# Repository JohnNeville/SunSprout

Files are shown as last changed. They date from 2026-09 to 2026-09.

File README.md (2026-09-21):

# SunSprout

> [!WARNING]
> **Work in progress. This board has never been fabricated or tested.**
>
> Everything here has been verified only in software — ERC and DRC pass, pin assignments and
> component values are checked against manufacturer datasheets, and the fabrication outputs
> generate cleanly. No physical board exists. Nothing has been powered on, measured, or
> proven to work.
>
> It is published at this stage deliberately, to get design feedback before a fabrication run.
> Manufacturing and bring-up are intended; this page will say so once real measurements exist.
>
> **If you are thinking of building one:** treat it as an untested design, not a finished
> product. Expect to find mistakes. Errors in the charging or protection circuitry could damage
> a battery. Review it yourself before spending money on a panelised order.
>
> Feedback is genuinely welcome — especially on the power path, the charger and fuel-gauge
> configuration, and anything in [docs/hub/modules/](docs/hub/modules/) where the reasoning
> looks wrong.

An open-hardware solar and battery powered sensor system. SunSprout covers both halves of a
deployment: the **hub**, a custom board that manages power and talks to the network, and the
**remote sensors** that connect back to it over a long cable run.

The hub is the custom hardware in this project. The remote sensors are largely assembled from
existing modules, and are documented here so that a whole system can be reproduced rather than
inferred.

## The hub

A compact power-management and connectivity board built around the **ESP32-C5**. It takes power
from USB-C, a small DC or solar source, or a lithium battery. It charges the battery, regulates
a 3.3 V system rail, and exposes two independent I2C buses — one for its own power-management
ICs, and one for sensors, buffered onto a differential pair so it can drive a long cable.

| | |
|---|---|
| Documentation site | **[johnneville.github.io/SunSprout](https://johnneville.github.io/SunSprout/)** — pinout, connectors, power behaviour |
| Design files | [hardware/hub/](hardware/hub/) — KiCad 10 project, hand-routed |
| Why it is built this way | [docs/hub/modules/](docs/hub/modules/) — per-IC design notes |
| Firmware | [firmware/](firmware/) — ESPHome configuration; [docs/hub/firmware.md](docs/hub/firmware.md) for the reasoning |
| Off-board parts you need | [docs/hub/extra-components.md](docs/hub/extra-components.md) |

Every IC's datasheet-required external components are drawn directly into the schematic rather
than treated as black-box breakout modules. The schematic and PCB are maintained by hand in
KiCad; there is no generator producing them.

### Design decisions worth knowing up front

- **Two independent I2C buses.** An always-on internal bus carries the charger and the fuel
  gauge. A separate switched bus feeds the differential buffer that drives the two 8P8C jacks,
  plus its own STEMMA QT connector. A fault on a long external cable cannot stall the bus that
  reports the battery state.
- **Protection sized to what each port is for.** ESD/TVS on the ports meant to carry a cable
  off-board — the differential I2C lines on the 8P8C jacks, the USB-C data lines, and the USB
  `VBUS` rail. The STEMMA QT ports, GPIO headers and thermistor inputs have none, by design:
  they are for sensors inside the same enclosure. Reverse-polarity protection guards the
  battery and solar inputs, each sized to that input's real voltage range; USB-C gets none,
  being a keyed, spec-defined connector that cannot be connected backwards.
- **Alert lines go to their own GPIOs.** The charger and the fuel gauge each get a dedicated
  interrupt pin, so firmware reacts to a fault without polling, and without interrogating both
  devices to find which one raised it.
- **Connector families differ by role on purpose.** The battery and solar inputs use physically
  different connectors, so a solar source cannot be plugged into the battery input. The two
  thermistor inputs are a third family again, chosen to be field-terminable rather than
  requiring a pre-terminated probe.

## Remote sensors

A custom board, `SunSproutSatellite` ([hardware/satellite/](hardware/satellite/)), is the
differential-I2C endpoint that sits at the plant end of the cable — it terminates the line,
converts back to standard I2C, and reads four capacitive soil-moisture probes plus one
1-Wire soil-temperature probe. It integrates what was previously an off-the-shelf SparkFun
QwiicBus EndPoint wired to a breadboarded ADS1115. See
[docs/satellite/modules/](docs/satellite/modules/) for the per-IC design notes, and
[Use Cases](https://johnneville.github.io/SunSprout/use-cases) for the deployed topology.

**Status: schematic-capture spec only** — the KiCad project is scaffolded but no board has
been fabricated yet.

## Repository layout

```
.
├── hardware/
│   ├── hub/                  # the hub's KiCad project, libraries, and SPICE decks
│   └── satellite/            # the satellite's KiCad project and libraries
├── firmware/                 # ESPHome configuration for the hub
├── docs/
│   ├── hub/
│   │   ├── modules/          # per-IC design notes: part choice, passive values, constraints
│   │   ├── firmware.md       # why the firmware is configured the way it is
│   │   └── extra-components.md
│   └── satellite/
│       └── modules/          # per-IC design notes for the satellite board
├── tools/                    # Dockerised KiCad CLI: validation, fab outputs, doc assets
└── website/                  # Docusaurus documentation site
```

## Documentation

The prose documentation is split by audience:

- **[docs/hub/modules/](docs/hub/modules/)** explains *why* the hub is built the way it is —
  why each part was chosen, and why its passives have the values and packages they do. Written
  for someone reading the design cold. Start at the [index](docs/hub/modules/README.md).
- **[docs/hub/firmware.md](docs/hub/firmware.md)** explains the firmware decisions — why the
  watchdog is off, why the charge voltage comes from the declared chemistry, and what the
  `SFET_PRESENT` bit unlocks. The configuration itself is in [firmware/](firmware/); the chip
  drivers live in [esphome-bq-drivers](https://github.com/JohnNeville/esphome-bq-drivers).
- **[website/](website/)** is the source for the user-facing documentation site, published at
  **[johnneville.github.io/SunSprout](https://johnneville.github.io/SunSprout/)**: pinout,
  connectors, power behaviour, and downloads.

Manufacturer datasheets are deliberately not redistributed here. Each design note names the
exact part number, so you can get the datasheet from the manufacturer.

## Building and validating

Docker is the only prerequisite. No local KiCad installation is required.

```bash
tools/run_kicad_validation.sh
```

```bash
tools/generate-docs-assets.sh
```

The first runs ERC and DRC. The second regenerates the board renders, schematic PDF, STEP
model, interactive BOM, and pinout diagram under `website/static/`. Re-run it after any
schematic or layout change, so that the published assets never go stale.

See [hardware/hub/README.md](hardware/hub/README.md) for what you can do with the KiCad project
without any extra setup, and which external libraries are optional.

## License

Copyright John Neville 2026.
This source describes Open Hardware and is licensed under the CERN-OHL-S v2.

You may redistribute and modify this source and make products using it
under the terms of the CERN-OHL-S v2 (https://ohwr.org/cern_ohl_s_v2.txt).

This source is distributed WITHOUT ANY EXPRESS OR IMPLIED WARRANTY,
INCLUDING OF MERCHANTABILITY, SATISFACTORY QUALITY AND FITNESS FOR A
PARTICULAR PURPOSE. Please see the CERN-OHL-S v2 for applicable conditions.

Source location: https://github.com/JohnNeville/SunSprout

See [LICENSE](LICENSE) for the full license text.

This design also vendors Espressif's official CC BY-SA 4.0 KiCad library for the ESP32-C5
module. See [NOTICE.md](NOTICE.md) for that credit and an acknowledgment of other technical
references consulted during design.

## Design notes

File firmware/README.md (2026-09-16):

# Firmware

ESPHome configuration for the SunSprout hub.

| File | What it is |
|---|---|
| `sunsprout-hub.yaml` | The board package. Hardware only: MCU, both I2C buses, charger, fuel gauge, alert inputs, user rail, status LED. |
| `example-device.yaml` | A complete device built on that package, with WiFi, the Home Assistant API, OTA and deep sleep. |

The two chip drivers live in a separate repository,
[esphome-bq-drivers](https://github.com/JohnNeville/esphome-bq-drivers), because they are
drivers for stock TI parts rather than anything specific to this board. The board package
pulls them in through `external_components`.

## Flash a board

```bash
pip install esphome
```

Create `secrets.yaml` next to the config with `wifi_ssid`, `wifi_password`,
`fallback_password`, `api_encryption_key` and `ota_password`, then:

```bash
esphome run firmware/example-device.yaml
```

Hold `SW2` (boot) while pressing `SW1` (reset) to enter download mode for the first flash.
After that, OTA works.

## Pin map

| GPIO | Net | Use |
|---|---|---|
| GPIO2 | `SDA_INT` | Internal I2C data (`LP_I2C_SDA`) |
| GPIO3 | `SCL_INT` | Internal I2C clock (`LP_I2C_SCL`) |
| GPIO4 | `FG_ALERT` | Fuel gauge alert, active low |
| GPIO6 | `LED1_CTRL` | Status LED |
| GPIO8 | `CHG_INT` | Charger interrupt, active low |
| GPIO9 | `SDA_USER` | User I2C data |
| GPIO10 | `SCL_USER` | User I2C clock |
| GPIO23 | `EN_3V3_USER` | Enables the switched user rail |

| Device | Bus | Address |
|---|---|---|
| BQ25798 charger | internal | `0x6B` |
| BQ34Z100 fuel gauge | internal | `0x55` |

See [ESP32-C5 module](../docs/hub/modules/esp32-c5-mcu.md) for the full pin assignment.

## The two I2C buses

The ESP32-C5 has one general-purpose I2C controller and one low-power controller. The
low-power controller is hard-wired to **GPIO2 for SDA and GPIO3 for SCL**, and that is
exactly how `SDA_INT` and `SCL_INT` are routed. The internal bus takes the low-power
controller (`low_power_mode: true`), the user bus takes the general-purpose one, and both
run at the same time.

**Do not move either internal-bus pin.** The low-power controller works on no other pair.
Put `SCL_INT` anywhere else and both buses end up competing for the single general-purpose
controller, which ESPHome refuses to build.

GPIO3 is also `MTDI`, a strapping pin that selects the SDIO sampling edge alongside GPIO25.
It defaults to floating and the bus pull-up latches it to 1 at reset. This board does not
use SDIO, so that has no effect — and GPIO2 (`SDA_INT`) is the `MTMS` strapping pin under
the same pull-up, so the design already carries this condition.

## Things the firmware must get right

**The charge voltage.** The charger reads the `PROG` resistor at power-on and comes up
configured for a 1S **4.2 V** cell. A LiFePO4 cell charges to 3.65 V.

The board package declares `chemistry: lifepo4`, and the driver derives the charge voltage
limit from that, writes it during setup, and rewrites it after any register reset. There is
deliberately **no charge-voltage slider** — a limit that protects the cell should not be
something anyone can drag in Home Assistant.

If you fit a different cell, change `cell_chemistry` in the substitutions. The accepted
values are `lifepo4`, `li_ion`, `li_ion_4_35` and `li_ion_4_40`.

**The charge current ceiling.** `R302` and `R303` cap the *input* current at roughly 2 A in
hardware — nearer 2.0 A on USB-C and 2.14 A on a high-voltage solar input, because the
divider is referenced to the input-dependent `REGN` rail. There is no equivalent hardware
limit on the charge current, and in buck mode the charge current can exceed the input
current, so `max_charge_current: 2000` in the board package is what keeps the 2 A copper
safe. Do not raise it.

**The watchdog stays off.** The charger's I2C watchdog reverts the charge voltage and
current to the `PROG` defaults when it expires — which for the voltage means 4.2 V. The
board package disables it.

**`ship_fet_present: true` is what makes the reboot button work.** `Q3` is the ship FET on
`SDRV`. The charger locks `SDRV_CTRL` — and `EN_BATOC` — at 0 until `SFET_PRESENT` is set,
so without this flag the ship-mode and power-cycle controls exist but do nothing. The
driver rejects the config outright rather than let that happen quietly.

## Rebooting the board

**Power Cycle Board** opens `Q3` for about 350 ms and closes it again. Everything on the
`SYS` rail loses power — the regulator, the MCU, the internal I2C pull-ups, both STEMMA QT
ports and the user rail — so the board reboots. The board package sets
`ship_fet_action_delay: false`, otherwise the charger waits ~10 s before acting.

Two parts stay powered: the charger performs the reset itself, and the fuel gauge sits on
`VBAT_PROTECTED`, on the pack side of `Q3`, so it keeps counting coulombs through it. That
is deliberate — a gauge that loses its supply has to relearn the pack — but it means **a
power cycle cannot clear a stuck I2C slave**, because neither I2C device actually loses
power. For a wedged bus, send the nine-clock recovery sequence on `SCL` instead.

Holding `SW3` for about 10 seconds does the same thing in hardware, with no firmware
involved, which is the one that still works when the MCU is hung.

**Charger Ship Mode** and **Charger Shutdown** cut power until an adapter arrives or `SW3`
pulls `QON` low. Both are hidden by default; the charger ignores either while an adapter is
connected. Neither stops the fuel gauge's standing draw, so neither gives true zero-draw
storage — unplug the pack at `J4` for that.

## Fuel gauge setup, once per board

The gauge ships with a lithium-ion chemistry profile (`Device Chemistry` defaults to
`LION`). A LiFePO4 cell needs a 400-series one, and until it is loaded the state of charge
is wrong no matter what else is configured.

**There is no I2C command that sets the chemistry** — `CHEM_ID` only reports it, and the
only selection path TI documents is the BQChem feature in bqStudio (datasheet §8.1.2.1.6).
But the chemistry lives in ordinary data flash, which §7.2.3.1 says is reachable through
bqStudio *or* through data flash block transfers — the same protocol this driver already
uses for capacity and calibration. The datasheet calls the captured result a Golden Image
File that "can then be written to multiple battery packs".

So: **bqStudio once, to obtain the values; not once per board.** After that the bytes can
be replayed over I2C. What bqStudio supplies is the table contents, not exclusive write
access — the datasheet does not publish them.

Everything else the gauge needs *can* be written from firmware. Set
`apply_configuration: true` in the `bq34z100` block with a cell attached and reflash; the
driver writes Design Capacity, Design Energy, cell count, the Pack Configuration bits and
the `R60` sense-resistor calibration, comparing each value first so it does not wear the
flash, and reading each one back to confirm. Then, with the pack at rest and no current
flowing, press **Calibrate Gauge Current Offset** and **Calibrate Gauge Board Offset**.

Set `expected_chem_id` to the chemistry you loaded and the driver will log an error at
boot if the gauge is running something else.

## Solar tracking

The BQ25798 tracks the panel's maximum power point itself. It stops switching every couple
of minutes, measures the open-circuit input voltage, and sets `VINDPM` to a fraction of it.
Turn it on with the **Enable MPPT** switch — the board package enables it by default.

This is why there is no separate power monitor on the board and no VINDPM-chasing script
in the configuration.

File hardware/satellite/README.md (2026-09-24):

# SunSproutSatellite — KiCad project

The satellite board's KiCad 10 project. Open `SunSproutSatellite.kicad_pro`.

This board is a differential-I2C endpoint: it terminates the far end of the cable coming
from a [SunSproutHub](../hub/), converts the differential pair back to standard I2C, and
reads four capacitive soil-moisture probes plus one 1-Wire soil-temperature probe. For the
design reasoning behind each part, see [docs/satellite/modules/](../../docs/satellite/modules/).

**Status: Complete 4-layer PCB layout.** The project schematic and PCB layout are fully completed, featuring a 4-layer stackup (JLC04161H-7628), controlled-impedance differential I2C routing, dedicated inner reference planes (`In1.Cu` and `In2.Cu`), ESD protection, cable power decoupling, and complete DFM rule verification with 0 DRC violations.

## Layout & Architecture

| Path | Contents |
|---|---|
| `SunSproutSatellite.kicad_sch` | Root hierarchical schematic |
| `sheets/i2c_endpoint_v1.kicad_sch` | Differential I2C endpoint, PCA9615 buffer, termination array, cable power entry, power status LED (LED1), cut jumper (JP19), and headers J1, J7, J8, J9 |
| `sheets/adc_sensors_v1.kicad_sch` | ADS1115 16-bit 4-channel ADC, JST PH moisture probe headers (J2–J5), and address jumper JP1 |
| `sheets/onewire_v1.kicad_sch` | DS2482S-100+ I2C to 1-Wire bridge, JST PH probe header (J6), and bit-weighted address jumper JP16 |
| `SunSproutSatellite.kicad_pcb` | Completed 4-layer PCB layout (27.25 mm × 51.10 mm) with inner ground/power planes |
| `SunSproutSatellite.kicad_dru` | Custom JLCPCB 4-layer design rules (clearances, trace widths, track angles, and annular rings) |
| `../libraries/` | Project-specific symbol & footprint library (shared with Hub) |

## External library dependencies

Two parts have no stock KiCad equivalent and are copied in from the hub's own libraries
rather than referenced externally:

| Part | Symbol | Footprint |
|---|---|---|
| PCA9615 differential I2C buffer | `project:PCA9615DPZ` | `Snapeda:TSSOP10_SOT552-1_NXP-L` |
| 8P8C/RJ45 jack | `project:RJHSE5380_QwiicBusCompatible` | `Snapeda:AMPHENOL_RJHSE5380` |

Both footprints resolve externally via `KICAD_3RD_PARTY` the same way the hub's do (see
[hardware/hub/README.md](../hub/README.md#external-library-dependencies)) — or, simpler for
a board with only two such parts: place each once, then use KiCad's "Update PCB from
Schematic" so the footprint geometry gets embedded directly into this project's own files,
exactly as the hub does for every part once placed. After that, no external dependency
remains for either part.

Every other part on this board — the ADS1115 ADC, the DS2484 1-Wire bridge, the ESD
protection diode array, and all connectors — resolves from KiCad's own stock libraries with
zero setup.

## Regenerating the documentation assets

Documentation assets (3D board renders, interactive BOM, and interactive pinout SVGs) are generated via `tools/generate-docs-assets.sh`. The generated assets live under `website/static/` and `website/static/img/`. Release assets (schematic PDFs, STEP models, and fabrication zips) are produced by the release workflow.

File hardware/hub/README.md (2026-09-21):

# SunSproutHub — KiCad project

The hub board's KiCad 10 project. Open `SunSproutHub.kicad_pro`.

For the design reasoning behind each IC and its passives, see [docs/hub/modules/](../../docs/hub/modules/).

## Layout

| Path | Contents |
|---|---|
| `SunSproutHub.kicad_sch` | Root/hierarchical top sheet |
| `sheets/` | Hierarchical sub-sheets (charger, fuel gauge, regulator, user I2C) |
| `SunSproutHub.kicad_pcb` | Board layout, hand-routed |
| `SunSproutHub.kicad_dru` | Custom design rules |
| `../libraries/` | Project-specific and vendored symbol/footprint libraries (shared with Satellite) |
| `spice_models/` | ngspice decks used to verify the reverse-polarity FETs |

## What you can do without any extra setup

KiCad writes the full geometry of every symbol and footprint directly into the
`.kicad_sch` and `.kicad_pcb` files at placement time. The schematic and the board are
therefore self-contained. After cloning you can open both, run ERC and DRC, inspect every
part, and export gerbers and a pick-and-place file, with no libraries beyond the ones KiCad
ships with.

## External library dependencies

**3D models are not external.** The board file carries an embedded copy of every 3D model
(KiCad's "Collect and Embed 3D Models"), so the board renders completely with nothing
installed.

Footprints are mostly in-repo too. Three library entries still resolve outside it, and they
are only consulted when you update a footprint *from its library* — not to open, review,
render, or fabricate the board, because the geometry is already in the board file.

| Library | Resolves via | Parts |
|---|---|---|
| `Snapeda` | `KICAD_3RD_PARTY` | `J201`, `J202`, `U3`, `U8`, `U4`, `U5`, `U201`, `D5`, `U202`, `Q301`-`Q304` |
| `PCM_JLCPCB` | PCM package ([CDFER](https://github.com/CDFER/JLCPCB-Kicad-Library), MIT) | The 0402 capacitors |
| `PCM_SparkFun-Connector` | PCM package | The 13 test points |
| `PCM_Capacitor_SMD_AKL` | PCM package | `C17` only, which is DNP and not fitted |

If KiCad reports these as missing, the board is still correct. To silence the warnings,
install the matching PCM packages and point `KICAD_3RD_PARTY` at your own third-party library
directory, or remove the unused entries from `fp-lib-table`.

The `USBC1` USB-C footprint and the `CN5` screw terminal are project footprints, in
`../libraries/footprints/project.pretty/`. The Espressif module's footprint and 3D model are
vendored under `../libraries/vendor/`.

### A note on licensing

Every library this design still depends on has stated terms: SnapEDA is CC BY-SA 4.0 with the
Design Exception 1.0, CDFER's library is MIT, and Espressif's is CC BY-SA 4.0. All three are
credited in [NOTICE.md](../../NOTICE.md). Earlier revisions used EasyEDA/LCSC content, whose
redistribution terms are not published; it has since been replaced throughout and no longer
appears in the design or the embedded model set.

## Regenerating the documentation assets

The board renders, schematic PDF, STEP model, interactive BOM, and pinout SVG under
`website/static/` are all build artifacts of the files here. Regenerate them from the
repository root after any schematic or layout change:

```bash
tools/generate-docs-assets.sh
```

Docker is the only prerequisite. No local KiCad installation is required.

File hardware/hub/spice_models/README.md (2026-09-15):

# SPICE verification decks

Small ngspice decks used to check MOSFET threshold and on-state behaviour against real
manufacturer models, rather than against a generic symbol's assumed characteristics.

These decks drove the reverse-polarity FET selection documented in
[docs/hub/modules/input-protection.md](../../../docs/hub/modules/input-protection.md).

## Why the models themselves aren't committed

The `.cir` decks here are original work and are tracked. The vendor model files they
`.include` are **not** tracked — `.gitignore` excludes them. Three reasons:

1. **No redistribution grant.** The Diodes Inc model carries a warranty disclaimer and nothing
   else; the AOS models carry no terms at all. Silence is not permission. The TI PSpice models
   come from a click-through download, and the TPS631000 one is explicitly encrypted.
2. **This repository is licensed CERN-OHL-S v2.** Vendoring third-party files under a
   repo-wide reciprocal license statement implies they are offered under that license too.
   They aren't, and they can't be.
3. **Nothing is lost.** A SPICE model is a design-verification aid. It is not needed to build
   the board, so it is an "Available Component" at most — the license obligation is to say
   where to get it, which is what this file does.

This matches how the repository already treats no-redistribution vendor CAD models.

## Getting the models

Download each model and drop it in this directory under the filename shown. Then the decks run
as-is.

| Filename | Part | Source |
|---|---|---|
| `AO3400.mod` | AO3400A (`Q301`–`Q304`) | Alpha & Omega Semiconductor product page for AO3400A |
| `AO3415.mod` | AO3415 | Alpha & Omega Semiconductor product page for AO3415 |
| `DMP3098L.spice.txt` | DMP3098L-7 (`Q2`) | Diodes Incorporated product page for DMP3098L-7 |

`AO3415_clean.mod` was a locally-edited copy of `AO3415.mod`, trimmed so ngspice would parse
it. Recreate it if needed rather than expecting it in the repository.

`AO3415` stands in for `Q1`'s actual part, MDD3415, which has no published SPICE model.
Treat that result as indicative, not authoritative.

## Decks

| Deck | Checks |
|---|---|
| `test_Q301_real.cir` | `Q301` (AO3400A), gate swept 0–5 V against the USB rail. |
| `test_Q2_real.cir` | `Q2` (DMP3098L-7), the solar/DC reverse-polarity FET. |
| `test_Q1_AO3415.cir`, `test_Q1_AO3415_v2.cir` | `Q1`'s battery-side FET, using the AO3415 stand-in. The `_v2` deck uses a coarser sweep. |

Each deck measures the gate threshold at 1 mA of drain current and the on-state current at full
gate drive.

## Running

```bash
ngspice -b test_Q301_real.cir
```

Run from inside this directory, because the decks use relative `.include` paths. Log and output
files are ignored by git — they regenerate on every run.

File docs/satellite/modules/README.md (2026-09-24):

# Per-IC design notes

This folder explains the design decisions for each integrated circuit on the satellite
board. Each page covers one IC and the passive components that belong to it.

These pages tell you *why* the design uses a part or a value. They do not repeat the
manufacturer datasheets. The board does not include the datasheets. Each page gives the exact
part number, so you can get the datasheet from the manufacturer.

See [docs/hub/modules/](../../hub/modules/) for the hub's own per-IC notes. This satellite
is the far end of the cable the hub's differential I2C buffer drives — several design
decisions here are direct mirrors, or direct contrasts, of decisions made there.

## Writing style

These pages use ASD-STE100 Simplified Technical English. Sentences are short. Each sentence
gives one idea. The text uses the active voice and one term for each concept.

## Reference terms

| Term | Meaning |
|---|---|
| `SAT_3V3` | This board's local 3.3V rail. In default direct mode, it is bridged to the cable's `RJ45_VCC_1` rail via solder jumper `JP18`. For long cable runs, it can be powered by an external buck converter connected between headers `J7` and `J9`. |
| `SDA_LOCAL` / `SCL_LOCAL` | The single-ended I2C bus on this board's own side of the PCA9615. The ADS1115 and the DS2482S-100+ both sit on this bus. |
| `ADDR_SEL` | The ADS1115's address-select pin, net-named separately from `SDA_LOCAL`/`SCL_LOCAL` because it is solder-jumpered to one of four different straps, not fixed to one net. |
| `ONEWIRE_DQ` | The single 1-Wire data line between the DS2482S-100+ and the temperature probe connector. |
| DNP | Do not populate. The part is on the schematic and the layout, but the board ships without it. |

## Pages

| Page | Reference | Part |
|---|---|---|
| [Differential I2C endpoint](pca9615-i2c-endpoint.md) | `U1` | PCA9615DPZ |
| [ADS1115 ADC](ads1115-adc.md) | `U2` | ADS1115IDGSR |
| [DS2482 1-Wire bridge](ds2482-1wire-bridge.md) | `U3` | DS2482S-100+ |
| [Sensor connectors](sensor-connectors.md) | `J2`–`J6` | — |

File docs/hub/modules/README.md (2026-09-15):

# Per-IC design notes

This folder explains the design decisions for each integrated circuit on the board. Each page
covers one IC and the passive components that belong to it.

These pages tell you *why* the design uses a part or a value. They do not repeat the
manufacturer datasheets. The board does not include the datasheets. Each page gives the exact
part number, so you can get the datasheet from the manufacturer.

## Writing style

These pages use ASD-STE100 Simplified Technical English. Sentences are short. Each sentence
gives one idea. The text uses the active voice and one term for each concept.

## Reference terms

| Term | Meaning |
|---|---|
| SYS rail | The charger output rail. The voltage changes with the battery and the input source. |
| `VBAT_RAW` | The battery connector `J4`, before the reverse-polarity FET `Q1`. |
| `VBAT_PROTECTED` | The pack side of the battery path. It sits after `Q1` and before the ship FET `Q3`. The fuel gauge connects here. |
| `VBAT` | The system side of the battery path. It sits after `Q3` and feeds the charger `BAT` pins. |
| 3V3_SYS | The always-on 3.3 V rail. It supplies the MCU and the internal I2C bus. |
| 3V3_USER | The switched 3.3 V rail. Firmware controls it. It defaults to off. |
| Internal I2C bus | The always-on bus. The charger, the fuel gauge and the `J6` port share it. |
| User I2C bus | The switched bus. The differential buffer, the `J203` port and the 8P8C jacks share it. |
| DNP | Do not populate. The part is on the schematic and the layout, but the board ships without it. |

## The BOM is optimised for small batches, not for volume

This is the single decision that most shapes the passive selection, and it is not obvious from
any individual part. **The board is costed for runs of tens, not thousands.**

At an assembly house like JLCPCB, an order carries two different kinds of cost. There is the
per-unit price of each component, and there is a one-off charge for every *distinct* part
number in the design — a feeder-loading or setup fee, plus an extended-part fee for anything
outside the house's basic library. On a run of ten boards, those one-off charges dominate.
A part that costs 2 cents more per unit is irrelevant next to a few dollars of setup for the
line it sits on.

So the design repeatedly does something that looks wrong in isolation: it fits a
higher-specified, more expensive component where a cheaper one would be electrically
sufficient, because that component is *already on the board somewhere else*.

Worked examples, all visible in the schematic's per-part notes:

- The 4.7 µF positions all use one 25 V 0805 part, including where the rail never exceeds
  3.3 V and a 6.3 V 0402 would have been fine. One feeder instead of two.
- The 10 µF positions use two parts rather than five: a 0603 for the low-voltage rails and a
  25 V 0805 where derating demands it.
- The ship FET `Q3` uses the same AO3400A as the four input-multiplexer FETs, so adding it cost
  a placement but no new part number.
- One 100 nF 0402 part covers every high-frequency decoupling position on the board.

The result is **61 distinct part numbers across 112 placements**, with the passives at 27
part numbers covering 70 placements — roughly 2.6 placements per unique passive.

**If you are building this at volume, reverse these decisions.** Once per-unit cost dominates,
the calculus inverts: fit the cheapest adequate part in each position, accept more distinct
part numbers, and the setup fees amortise away. Nothing in the electrical design depends on
these choices — a 6.3 V part where 6.3 V suffices works exactly as well.

## Pages

| Page | Reference | Part |
|---|---|---|
| [ESP32-C5 module](esp32-c5-mcu.md) | `U1` | ESP32-C5-WROOM-1U |
| [Battery charger](bq25798-charger.md) | `U8`, `Q3`, `Q301`–`Q304`, `L1` | BQ25798RQMR |
| [Fuel gauge](bq34z100-fuel-gauge.md) | `U3`, `R60` | BQ34Z100PWR-G1 |
| [Buck-boost regulator](tps631000-regulator.md) | `U4`, `L2` | TPS631000DRLR |
| [User-rail load switch](tps22918-load-switch.md) | `U5` | TPS22918DBVR |
| [Differential I2C buffer](pca9615-i2c-buffer.md) | `U201` | PCA9615DPZ |
| [ESD protection](usblc6-esd-protection.md) | `D5`, `U202` | USBLC6-4SC6-ES |
| [Input reverse-polarity protection](input-protection.md) | `Q1`, `Q2`, `D2` | MDD3415, DMP3098L-7, BZT52C12S |

## Removed parts

The board does not have a separate power monitor IC. An early design had one. The charger
reports the input voltage and the input current through its own ADC. The fuel gauge reports the
battery voltage and the battery current. Together they cover the same measurements, so the
design removed the separate monitor.

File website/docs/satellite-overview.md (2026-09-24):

---
sidebar_position: 1
title: Satellite Overview
---

import useBaseUrl from '@docusaurus/useBaseUrl';

# SunSprout Satellite

:::info[Differential I2C Sensor Leaf Node]

The **SunSprout Satellite** is the dedicated remote sensor endpoint for the SunSprout ecosystem. It terminates a long differential-I2C cable run from the [SunSprout Hub](./overview.md), restores standard local I2C signaling, and monitors up to four capacitive soil-moisture probes plus a 1-Wire soil-temperature probe.

:::

<div style={{textAlign: 'center', margin: '2rem 0'}}>
  SunSprout Satellite 3D top render hero image
</div>

## What is the Satellite?

The **SunSprout Satellite** functions as a remote garden/agricultural probe station. Where standard I2C buses degrade after a few tens of centimetres, the Satellite connects to the Hub over standard Category-rated twisted-pair patch cable (up to 20+ metres) using differential signaling.

At the endpoint, the board translates the differential clock and data signals back into standard 3.3V single-ended I2C, hosts an onboard 16-bit analog-to-digital converter (ADS1115) and a hardware 1-Wire master bridge (DS2482-100+), and distributes power and ground to local sensors.

<div style={{textAlign: 'center', margin: '2rem 0'}}>
  SunSprout Satellite 3D bottom render
</div>

---

## Physical Specifications

| Property | Value | Notes |
|---|---|---|
| **Form factor** | 27.25 × 51.10 mm | Slender rectangular profile fits small waterproof enclosures or conduit |
| **Board thickness** | 1.6 mm | Standard FR4 |
| **Layer stackup** | 4 copper layers | `F.Cu` (signals), `In1.Cu` (power), `In2.Cu` (ground plane), `B.Cu` (signals) |
| **Mounting** | 3× M2 non-plated holes | 3.0 mm corner inset at top; 1 mid-board support hole |
| **Primary interface** | 1× Amphenol RJHSE5380 | 8P8C (RJ45) jack with metal EMI shield |
| **Sensor ports** | 5× JST PH 2.0mm 3-pin | 4 moisture probe inputs + 1 temperature probe input |
| **Auxiliary port** | 1× 2.54mm 4-pin header | Secondary power injection / tap header (`VCC_2`, `GND_2`, `GND`, `SAT_3V3`) |

---

## Capabilities & Architecture

### 1. Differential I2C Bus Endpoint (PCA9615)
- **PCA9615DPZ** differential buffer translates `DSCL+`/`DSCL-` and `DSDA+`/`DSDA-` back into local `SCL_LOCAL` and `SDA_LOCAL`.
- **Fixed Onboard Termination**: Populated with matched resistor ladders (390Ω bias pull-ups to `SAT_3V3`, 100Ω line matching resistors, and 390Ω bias pull-downs to `GND`) across both differential pairs. This ensures proper transmission line termination without loose plug-in resistors.
- **TVS / ESD Protection**: An onboard **USBLC6-4SC6** transient voltage suppressor array clamps all four differential lines against outdoor static and handling discharge.

### 2. High-Precision Soil Moisture Monitoring (ADS1115)
- **ADS1115IDGS** 16-bit 4-channel delta-sigma ADC with programmable gain amplifier and internal reference.
- Reads analog voltage outputs from up to **four** independent capacitive soil-moisture probes (e.g., DFRobot SEN0193 / Gravity interface).
- Four 3-pin vertical JST PH connectors (`J2`–`J5`) distribute `GND`, `SAT_3V3`, and signal lines (`MOIST1`–`MOIST4`).
- **Configurable I2C Address (`JP1`)**: 4-way solder jumper on the bottom side selects addresses `0x48`, `0x49`, `0x4A`, or `0x4B` (`0x48` default bridged).

### 3. Dedicated 1-Wire Temperature Bridge (DS2482-100+)
- Hardware I2C-to-1-Wire master bridge eliminates software bit-banging and timing jitter over long probe leads.
- Dedicated 3-pin vertical JST PH connector (`J6`) connects a waterproof DS18B20 digital temperature probe (`SAT_3V3`, `GND`, `ONEWIRE_DQ`).
- Onboard 4.7kΩ pull-up to `SAT_3V3` provides reliable bus drive.
- **Configurable I2C Address (`JP16`)**: Dual solder jumper with bit-weighting notation (`AD0 (+1)` and `AD1 (+2)`) selects addresses `0x18` (factory default), `0x19`, `0x1A`, or `0x1B`.

### 4. Power & Auxiliary Flexibility
- **Decoupled Power Architecture**: PCA9615 transceiver power (`VDDB`), differential termination bias networks (`R3`, `R5`, `R6`, `R8`), and the ESD clamp array (`U4`) connect directly to raw cable power (`RJ45_VCC_1` / `RJ45_GND_1`). This isolates cable common-mode transients and transmission-line reference planes from the local analog sensing domain.
- **Bulk Cable Reservoir (`C1`)**: An onboard 22 µF bulk capacitor (`C1`) sits directly across `RJ45_VCC_1` and `RJ45_GND_1` right at the cable entry, dampening inductive cable ringing and buffering transient load steps. Dedicated 100 nF ceramic decoupling capacitors sit directly adjacent to every active IC pin.
- **Factory Default Operation (Zero Overhead)**: Pre-bridged cuttable solder jumpers `JP18` (`RJ45_VCC_1` $\leftrightarrow$ `SAT_3V3`) and `JP17` (`RJ45_GND_1` $\leftrightarrow$ `GND`) power the board directly from the Hub's regulated 3.3V rail over Pair 1 out of the box with zero external wiring.
- **Cable Power Breakout Header (`J7`)**: Exposes raw Pair 1 (`RJ45_VCC_1`, `RJ45_GND_1`) and Pair 3 (`RJ45_VCC_2`, `RJ45_GND_2`) conductors on a 2.54mm pitch header for secondary power injection or tapping.
- **Satellite Local Power Header (`J9`) & Long-Distance Regulation**: A 2-pin 2.54mm header (`SAT_3V3`, `GND`). On extended cable runs (50–100 m) where cable IR drop is non-negligible, users can slice `JP18` (and optionally `JP17`), send higher voltage (12V/24V) down Pair 3, and connect an off-the-shelf compact buck regulator between `J7` and `J9`.
- **Single-Cut Pull-Up Jumper (`JP11`)**: A custom 3-pad solder jumper with a single collinear cut channel allows disconnecting both local 4.7kΩ I2C pull-ups simultaneously with a single craft knife slice.
- **Power Status LED (`LED1`) & Cuttable Jumper (`JP19`)**: A green 0805 power indicator illuminates whenever `SAT_3V3` is energized. Solder jumper `JP19` allows severing the LED ground connection with a hobby knife for zero quiescent draw in battery-powered applications.
- **Cable Shield Isolation (`JP13`)**: Cuttable solder jumper on the bottom side connects the RJ45 metal shield to `RJ45_GND_1` by default, allowing single-point grounding configurations when required.

---

## Further Reading
- [Dimensions & Mounting](./satellite-dimensions.md) — Exact outline, mounting hole locations, connector courtyard extents, and enclosure clearance guidance.
- [Hub Overview](./overview.md) — Main system controller, solar MPPT charger, and differential I2C driver.
- [Design Files](./design-files.md) — Schematic PDFs, Gerbers, and 3D CAD STEP models.

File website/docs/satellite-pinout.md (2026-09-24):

---
sidebar_position: 2
title: Satellite Pins & Jumpers
---

import useBaseUrl from '@docusaurus/useBaseUrl';

# Satellite Pins & Jumpers

The **SunSprout Satellite** acts as a remote sensor endpoint terminating a differential-I2C cable run from the Hub. This page details all physical connector pinouts, sensor interfaces, and the hardware configuration solder jumpers on the bottom of the board.

---

## 1. Top View: Ports & Connectors

The top side exposes the primary **RJ45 differential bus interface (`J1`)**, **five JST PH 2.0mm sensor ports (`J2`–`J6`)**, and the **auxiliary power header (`J7`)**.

import InteractivePinout from '@site/src/components/InteractivePinout';

<InteractivePinout
  board="satellite"
  topSrc="/img/satellite-pinout-top.svg"
  bottomSrc="/img/satellite-pinout-bottom.svg"
/>

### Connector Pinout Tables

#### Primary RJ45 Interface (`J1`)
Terminates standard Category-rated twisted-pair patch cable from the Hub. Uses standard T568B pair pairings for differential integrity.

| RJ45 Pin | Net Name | Function / Description | Twisted Pair |
|:---:|---|---|---|
| **1** | `DSCL_N` | Differential I2C Clock (Negative) | Pair 2 (Orange/White) |
| **2** | `DSCL_P` | Differential I2C Clock (Positive) | Pair 2 (Orange) |
| **3** | `RJ45_VCC_2` | Auxiliary Power Conductor (Pass-through to `J7` pin 4) | Pair 3 (Green/White) |
| **4** | `RJ45_VCC_1` | Primary Cable Power (Powers diff transceivers; feeds `SAT_3V3` via `JP18`) | Pair 1 (Blue) |
| **5** | `RJ45_GND_1` | Primary Ground Return (Pass-through to `J7` pin 2; bridges to system `GND` via `JP17`) | Pair 1 (Blue/White) |
| **6** | `RJ45_GND_2` | Auxiliary Ground Return (Pass-through to `J7` pin 3) | Pair 3 (Green) |
| **7** | `DSDA_N` | Differential I2C Data (Negative) | Pair 4 (Brown/White) |
| **8** | `DSDA_P` | Differential I2C Data (Positive) | Pair 4 (Brown) |
| **SH** | `SHIELD` | RJ45 Metal Chassis Shield (Tied to `RJ45_GND_1` via `JP13`) | Outer Braid / Foil |

#### Soil Moisture Sensor Ports (`J2` – `J5`)
Vertical 3-pin JST PH (2.0mm pitch) connectors. Designed for capacitive analog moisture probes (e.g., Gravity / SEN0193).

| Connector | Pin 1 | Pin 2 | Pin 3 | ADC Channel | Notes |
|---|---|---|---|---|---|
| **`J2`** | `GND` | `SAT_3V3` | `MOIST1` | ADS1115 AIN0 | Moisture Probe Channel 1 |
| **`J3`** | `GND` | `SAT_3V3` | `MOIST2` | ADS1115 AIN1 | Moisture Probe Channel 2 |
| **`J4`** | `GND` | `SAT_3V3` | `MOIST3` | ADS1115 AIN2 | Moisture Probe Channel 3 |
| **`J5`** | `GND` | `SAT_3V3` | `MOIST4` | ADS1115 AIN3 | Moisture Probe Channel 4 |

#### 1-Wire Temperature Sensor Port (`J6`)
Vertical 3-pin JST PH connector for waterproof digital temperature probes (DS18B20). Driven by the onboard DS2482-100+ hardware I2C-to-1-Wire bridge with an onboard 4.7kΩ pull-up.

| Pin | Net Name | Function | Wire Color (Typical DS18B20) |
|:---:|---|---|---|
| **1** | `SAT_3V3` | Power Supply | Red (VCC) |
| **2** | `GND` | Ground Return | Black / Blue (GND) |
| **3** | `ONEWIRE_DQ` | 1-Wire Bidirectional Data | Yellow / White (DATA) |

#### Cable Power Breakout Header (`J7`)
Standard 2.54mm (0.1") pitch 4-pin header breaking out raw conductors from cable Pairs 1 and 3 for external tapping or powering off-board modules.

| Pin | Net Name | Description | Twisted Pair |
|:---:|---|---|---|
| **1** | `RJ45_VCC_1` | Primary cable supply conductor from RJ45 pin 4 | Pair 1 (Blue) |
| **2** | `RJ45_GND_1` | Primary cable ground conductor from RJ45 pin 5 | Pair 1 (Blue/White) |
| **3** | `RJ45_GND_2` | Secondary/auxiliary ground conductor from RJ45 pin 6 | Pair 3 (Green) |
| **4** | `RJ45_VCC_2` | Secondary/auxiliary power conductor from RJ45 pin 3 | Pair 3 (Green/White) |

#### Satellite Local Power Header (`J9`)
Standard 2.54mm (0.1") pitch 2-pin header for local voltage regulation or direct 3.3V board power injection.

| Pin | Net Name | Description |
|:---:|---|---|
| **1** | `SAT_3V3` | Satellite local 3.3V power rail (powers ADC, 1-Wire bridge, sensors, and Qwiic) |
| **2** | `GND` | System digital and analog ground |

#### Power Status Indicator (`LED1` & `JP19`)
- **`LED1`**: A dedicated green 0805 SMD LED located on the top side near the mounting hole illuminates whenever the regulated `SAT_3V3` rail is powered (via cable power or local injection). Ballasted with a 120Ω resistor (`R10`).
- **`JP19`**: A 2-pad normally closed (bridged) solder jumper in series with `LED1`'s cathode return to `GND`. For battery-powered or ultra-low-power field deployments, slice the trace across `JP19` with a hobby knife to eliminate quiescent LED current draw.

> [!TIP]
> **Long-Distance Cable Regulation:** If the satellite is deployed on a very long cable run (50–100 m) with noticeable 3.3V IR drop:
> 1. Cut solder jumper `JP18` (isolating `SAT_3V3` from cable `RJ45_VCC_1`).
> 2. Inject higher voltage (e.g., 12V or 24V) at the Hub onto Pair 3 (`VCC_2` / `GND_2`).
> 3. Connect a compact 3.3V buck regulator module: Input to `J7` (pins 3 & 4), Output to `J9` (`SAT_3V3` & `GND`).
> The PCA9615 differential transceiver and termination continue to run reliably off `RJ45_VCC_1`, while local sensors receive clean, local regulation.

---

## 2. Bottom View: Hardware Jumpers & Addressing

The bottom side hosts the solder jumpers for configuring I2C addresses, terminating pull-ups, and managing power/ground routing.

<InteractivePinout
  board="satellite"
  src="/img/satellite-pinout-bottom.svg"
/>

### Jumper Configuration Matrix

#### `JP1`: ADS1115 I2C Address Selection (4-Way)
A 4-way solder jumper connecting the ADS1115 `ADDR` pin to select one of four unique I2C bus addresses.

| Configuration | Bridge Position | 7-bit Address | State |
|---|:---:|:---:|---|
| **Pads 1-2** | `ADDR` connected to `GND` | **`0x48`** | **Factory Default** (Pre-bridged with copper trace) |
| **Pads 1-3** | `ADDR` connected to `SAT_3V3` | **`0x49`** | Cut 1-2 trace; solder bridge 1-3 |
| **Pads 1-4** | `ADDR` connected to `SDA_LOCAL` | **`0x4A`** | Cut 1-2 trace; solder bridge 1-4 |
| **Pads 1-5** | `ADDR` connected to `SCL_LOCAL` | **`0x4B`** | Cut 1-2 trace; solder bridge 1-5 |

> [!TIP]
> To change the address, slice the thin copper trace bridging pads 1 and 2 with a hobby knife, then apply a small solder blob between pad 1 (common) and your chosen address pad.

#### `JP16`: DS2482-100+ 1-Wire Master Address Selection (Bit-Weighted Dual Jumper)
Controls the `AD0` (+1 bit weight) and `AD1` (+2 bit weight) address select pins of the I2C-to-1-Wire bridge. Silkscreen markings explicitly show **`DEF (0x18)`**, **`AD0 (+1)`**, and **`AD1 (+2)`**.

| Address Bits | Bridge Selection | 7-bit Address | Configuration Method |
|:---:|---|:---:|---|
| **`AD1=0, AD0=0`** | Pads 2A to GND & 2B to GND | **`0x18`** | **Factory Default** (Pre-bridged traces to GND) |
| **`AD1=0, AD0=1`** | Cut 2A bridge; solder bridge 2A to `VCC` | **`0x19`** | Adds **+1** to base address `0x18` |
| **`AD1=1, AD0=0`** | Cut 2B bridge; solder bridge 2B to `VCC` | **`0x1A`** | Adds **+2** to base address `0x18` |
| **`AD1=1, AD0=1`** | Cut both bridges; solder both to `VCC` | **`0x1B`** | Adds **+1 + 2** to base address `0x18` |

#### `JP11`: Local I2C Pull-Up Resistor Disconnect
- **Purpose**: Disconnects the two onboard 4.7kΩ pull-up resistors on `SDA_LOCAL` and `SCL_LOCAL`.
- **Design**: Collinear single-cut 3-pad jumper on top side.
- **Usage**: Both pull-ups are enabled by default. Slice across the center cut line with a single blade stroke to disable both local pull-ups if the bus master already provides adequate pull-up strength.

#### `JP19`: Power Status LED Disconnect (`LED1`)
- **Default (Bridged)**: The green power status LED (`LED1`) cathode returns to `GND` through pre-bridged trace on `JP19`.
- **Cuttable**: Slicing the copper trace between pads of `JP19` on the top side disables `LED1` to eliminate quiescent draw (~4–10 mA) for battery or energy-harvesting deployments.

#### `JP18`: Power Source Bridge (`RJ45_VCC_1` $\leftrightarrow$ `SAT_3V3`)
- **Default (Bridged)**: Satellite local power (`SAT_3V3`) is fed directly from cable Pair 1 (`RJ45_VCC_1`).
- **Cuttable**: Slicing the copper trace disconnects `SAT_3V3` from the cable supply, allowing local power injection via `J9` from an external buck or LDO regulator.

#### `JP17`: Ground Isolation Bridge (`RJ45_GND_1` $\leftrightarrow$ `GND`)
- **Default (Bridged)**: Cable primary ground (`RJ45_GND_1`) is bonded directly to local system `GND`.
- **Cuttable**: Slicing this bridge isolates cable ground return from local sensor/analog ground for galvanically isolated multi-supply operation.

#### `JP13`: Cable Shield Grounding
- **Default (Bridged)**: The metal shield of the RJ45 jack is tied directly to `RJ45_GND_1`.
- **Cuttable**: Slicing the copper trace between pads 1 and 2 isolates the cable shield from satellite ground, enabling single-point earth grounding at the Hub end to prevent ground loops.

---

## 3. Interactive BOM Viewer

For interactive probing and component highlighting:
- **[Open the Satellite Interactive BOM](pathname:///ibom-satellite/)** — Click any component to highlight its footprint, routing, and pin connections.

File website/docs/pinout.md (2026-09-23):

---
sidebar_position: 3
title: Pins & Signals
---

# Pins & Signals

The ESP32-C5-WROOM-1U module's pins are split between board-managed functions (things the
board itself wires up — buttons, I2C buses, alerts) and pins left free for your own use.

## Pinout diagram

import InteractivePinout from '@site/src/components/InteractivePinout';

<InteractivePinout
  board="hub"
  topSrc="/img/pinout-top.svg"
  bottomSrc="/img/pinout-bottom.svg"
/>

Auto-generated vector pinout diagrams (`tools/generate-docs-assets.sh`) showing all board peripherals, expansion headers (`J7`, `J8`), Stemma QT ports, buttons, strapping pins, and bottom-side hardware test points with color-coded signal tags. Use the **Top (Signals)** and **Bottom (Test Points)** toggle in the diagram toolbar to inspect both layers.

For something more useful when you're actually holding the board: **[open the interactive
BOM](pathname:///ibom/)** — hover or click any reference designator to highlight
it on the board (and vice versa), search by part/value, and toggle top/bottom layers. Generated
by [InteractiveHtmlBom](https://github.com/openscopeproject/InteractiveHtmlBom) from the same
`.kicad_pcb` source as everything else on this page.

## GPIO map

| GPIO | Function | Category | Strapping pin? | Pull resistor | Notes |
|---|---|---|---|---|---|
| CHIP_PU/EN | Reboot button (SW1) | Fixed | No (dedicated EN pin) | R1 10kΩ pull-up to 3V3_SYS + C2 1µF | Reset button |
| GPIO0 | LP_GPIO0 (Expansion) | Free | No (not a strap on ESP32-C5) | — | Routed to expansion header J7 pin 3. Low-power domain, deep-sleep wake capable |
| GPIO1 | Unused | Free | No | — | Routed to expansion header J7 |
| GPIO2 | SDA_INT — **`LP_I2C_SDA`** | Assigned | No | R20 4.7kΩ pull-up to 3V3_SYS | Internal I2C data. Fixed-function LP pin; see below. |
| GPIO3 | SCL_INT — **`LP_I2C_SCL`** | Assigned | Yes — SDIO sampling/clock-edge select | R21 4.7kΩ pull-up to 3V3_SYS | Internal I2C clock. Fixed-function LP pin; see below. |
| GPIO4 | FG_ALERT (fuel gauge) | Assigned | No — deep-sleep wake capable | R401 10kΩ pull-up to 3V3_SYS | Fuel-gauge alert, wake-capable. Kept on its own net, separate from the charger's interrupt |
| GPIO5 | Unused | Free | No | — | Routed to expansion header J8 |
| GPIO6 | LED1_CTRL (status LED) | Assigned | No | — (push-pull output) | Drives LED1 through R3 (120Ω) |
| GPIO7 | Unused | Free | Yes — paired SDIO edge-select strap | — | Routed to expansion header J7 |
| GPIO8 | CHG_INT (charger interrupt) | Assigned | No | R24 10kΩ pull-up to 3V3_SYS | Short interrupt pulse; recoverable via I2C polling |
| GPIO9 | SDA_USER (user I2C data) | Assigned | No | R201 4.7kΩ pull-up to 3V3_USER | Feeds the I2C differential buffer + external STEMMA QT port |
| GPIO10 | SCL_USER (user I2C clock) | Assigned | No | R202 4.7kΩ pull-up to 3V3_USER | Paired with GPIO9 |
| GPIO11 | U0TXD | Fixed | No | — | Debug console UART, also routed to J8 |
| GPIO12 | U0RXD | Fixed | No | — | Debug console UART, also routed to J8 |
| USB_D− | USB_DN | Fixed | No | R7, 22Ω series | Native USB peripheral. The series resistor Espressif recommends. |
| USB_D+ | USB_DP | Fixed | No | R8, 22Ω series | Native USB peripheral. Shared with the charger's BC1.2 detection input via R9/R11, which ship as cuttable 0Ω bridges. See [Notes](notes.md#the-charger-taps-the-usb-data-lines-through-cuttable-bridges). |
| GPIO15 | Reserved — in-package PSRAM chip-select | Reserved | No | — | Consumed inside the module, not by this board. See below. |
| GPIO16–22 | Not exposed | Reserved | — | — | Internal to the module, not broken out |
| GPIO23 | EN_3V3_USER | Assigned | No | R23 100kΩ pull-down to GND | Enables the switched 3V3_USER rail; defaults OFF at power-up |
| GPIO24 | Unused | Free | No | — | Routed to expansion header J8; free for reassignment |
| GPIO25 | Unused | Free | Yes — boot-mode strap, floating default | — | Routed to expansion header J8 |
| GPIO26 | Unused | Free | Yes — boot-mode strap, floating default | — | Routed to expansion header J8 |
| GPIO27 | Unused | Free | Yes — boot-mode strap | — | Routed to expansion header J8 |
| GPIO28 | Boot/flash button (SW2) | Fixed/Strap | Yes — ROM download boot strap | Internal pull-up + R4 10kΩ pull-up to 3V3_SYS | Primary ESP32-C5 boot strap. Hold SW2 low during reset (SW1) to enter download mode. Also routed to TP18 |

## Why the internal bus is on GPIO2/GPIO3

The ESP32-C5 has **one** general-purpose I2C controller and **one** low-power controller
(datasheet §4.2.1.3: *"ESP32-C5 has an I2C and an LP I2C bus interface"*). Two simultaneous I2C
buses therefore need both.

The HP controller routes to any pin through the GPIO matrix, but `LP_I2C` does not — it is
hard-wired through the LP IO MUX to **GPIO2 (`LP_I2C_SDA`) and GPIO3 (`LP_I2C_SCL`)**. So the
internal bus sits on exactly those two pins, and the user bus takes the HP controller on
GPIO9/GPIO10. Put the internal bus anywhere else and both buses contend for the single HP
controller, which won't build.

That pinning also buys something: the LP peripherals and LP CPU stay powered in deep sleep, so
the charger and fuel gauge can be polled while the main CPU is off, rather than waking the
whole chip to read a register.

## Free IO

GPIO0, GPIO1, GPIO5, GPIO7, GPIO24, GPIO25, GPIO26, and GPIO27 are unused and available for
your own projects. All of them are routed out to the two expansion headers (`J7` and `J8`),
which aren't fitted at the factory — solder a 2.54mm header strip to use them.

Note the strapping-pin caveats on GPIO7, GPIO25, GPIO26, and GPIO27 above: the
MCU samples these at reset to select a boot mode, so check what each strap does before loading
one down at boot. (GPIO28 is dedicated to the SW2 download boot button with an internal and external pull-up).

## Special-function pins

CHIP_PU/EN, GPIO28, GPIO11–12 and the native USB pins are committed to fixed board functions —
reset, boot select (SW2), debug UART and native USB respectively — and aren't available for
reassignment. (GPIO0 is in the low-power domain `LP_GPIO0` and is broken out on header J7 pin 3).

**GPIO15 is a module-level reservation, not a board one.** This design uses the
`ESP32-C5-WROOM-1U-N8R8` variant, where the `R8` denotes 8 MB of PSRAM packaged inside the
module alongside the 8 MB of flash. That PSRAM's chip-select is wired to GPIO15 *within the
module*, so the pin never reaches the module's edge as a usable IO no matter what the host
board does. This board leaves it unconnected, and the firmware doesn't enable the PSRAM either
— so it is neither routed nor in use here. A module variant without in-package PSRAM would free
the pin, at the cost of the PSRAM.

## Hardware Test Points (Bottom View)

The bottom side of the SunSproutHub PCB breaks out key electrical nodes as circular surface-mount test pads for multimeter and oscilloscope probing during bringup and verification:

| Test Point | Signal / Net | Function & Description | Category |
|---|---|---|---|
| **TP17** | `U0TXD` | ESP32-C5 primary UART console transmit | Debug / Serial |
| **TP16** | `U0RXD` | ESP32-C5 primary UART console receive | Debug / Serial |
| **TP18** | `BOOT` (`BTN1_NODE`) | Download boot mode strap (GPIO28) | Control / Strap |
| **TP19** | `RESET` (`RESET_NODE`) | Hardware reset line (`CHIP_PU` / `EN`) | Control / Power |
| **TP2** | `SDA_INT` | Internal `LP_I2C` bus data line (GPIO2) | Internal I2C |
| **TP3** | `SCL_INT` | Internal `LP_I2C` bus clock line (GPIO3) | Internal I2C |
| **TP8** | `3V3_SYS` | Always-on 3.3V system supply from buck converter | Power Rail |
| **TP7** | `3V3_USER` | Switched 3.3V power rail feeding external sensors and J8 | Power Rail |
| **TP12** | `SYS_RAIL` | Main system power bus from BQ25798 NVDC charger | Power Rail |
| **TP14** | `VBAT` | Raw 1S battery cell positive terminal voltage | Battery |
| **TP15** | `VBAT_PRO` | Protected battery voltage after discharge protection FET | Battery |
| **TP9** | `VBUS_INTERNAL` | USB-C and Solar input power rail (5V–20V) | Power Rail |
| **TP13** | `REGN_RAIL` | 5V internal gate drive and bootstrap LDO rail | Power Rail |
| **TP10** | `TS_NODE` (`CHGR_TS`) | Battery thermistor analog sensing node for BQ25798 charger | Thermistor |
| **TP11** | `FG_TS_NODE` (`FG_TS`) | Independent battery temperature sensor for BQ34Z100 fuel gauge | Thermistor |
| **TP4, TP5, TP6** | `GND` | System reference ground test pads | Ground |

### Hardware Solder Jumpers (Bottom)

- **`JUMP_CHGR_GND2` (USB D+/D- Conditioning)**: 3-pad jumper between `CHGR_USB_DN`, `GND`, and `CHGR_USB_DP`. Allows configuring USB data lines for standalone charger BC1.2 port detection.
- **`JP2` (`GRN_P -> 3V3_USER`) & `JP3` (`GRN_N -> GND`) (RJ45 Aux Power Isolation)**: Cuttable solder jumpers bridging the otherwise unused green twisted pair (RJ45 pins 3 & 6: `VCC_2` and `GND_2`/`GRN_N`) to the Hub's `3V3_USER` rail and system `GND`. Shorted as fabricated. Slice both jumpers open to isolate `VCC_2` from the onboard 3.3V supply, allowing custom external voltages (e.g. 5V, 12V) to be injected via header `J2` to power remote differential QwiicBus sensors or power-hungry satellite peripherals without back-powering the Hub.

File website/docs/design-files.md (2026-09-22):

---
sidebar_position: 8
title: Design Files & Key Components
---

# Design Files & Key Components

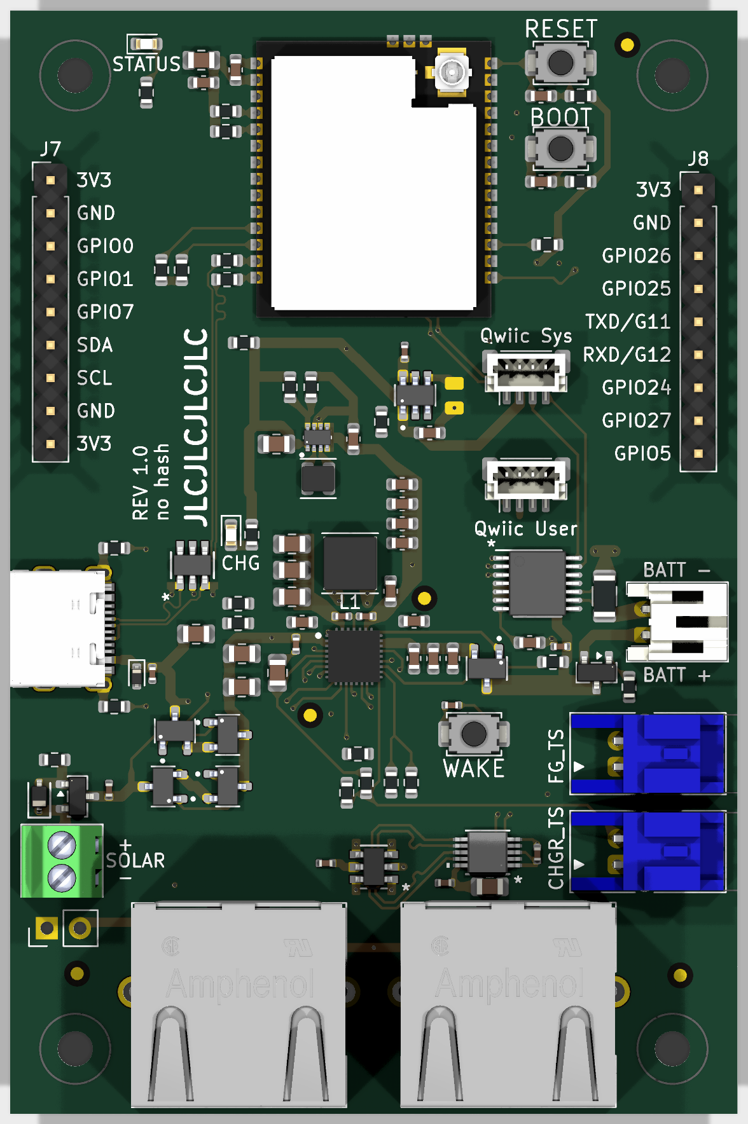
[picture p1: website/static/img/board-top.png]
Board render, top view


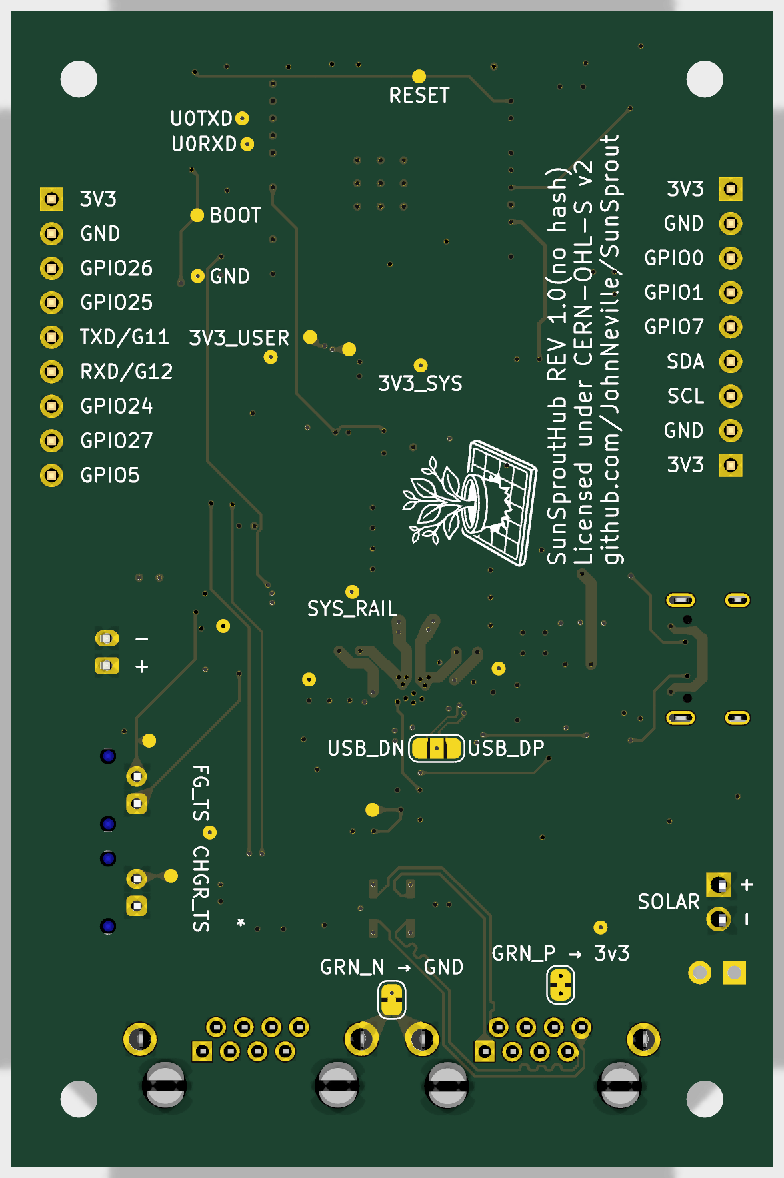
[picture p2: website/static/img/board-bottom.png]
Board render, bottom view


## Key components

| Ref | Part | Function |
|---|---|---|
| U1 | ESP32-C5-WROOM-1U | Main MCU, Wi-Fi 6 / Bluetooth 5 / 802.15.4 / CAN FD radio module |
| U8 | BQ25798 | Li-ion/Li-Po battery charger |
| U3 | BQ34Z100 | Fuel gauge |
| U4 | TPS631000 | Buck-boost regulator, 3.3V system rail |
| U5 | TPS22918 | Load switch, switched 3.3V user rail |
| U201 | PCA9615 | Differential I2C buffer, drives the two 8P8C jacks |
| D5, U202 | USBLC6-4SC6-ES | USB-C and I2C-buffer ESD protection |
| Q1, Q2, D2 | MDD3415, DMP3098L-7, BZT52C12S | Reverse-polarity protection on the battery and DC/solar inputs; D2 clamps Q2's gate |

For why each of these parts was chosen, and why its surrounding passives have the values they
do, see the per-IC design notes in the repository's `docs/hub/modules/` folder.

## A note on the BOM

The bill of materials is optimised for **small-batch assembly**, not for volume production.

Assembly houses charge a one-off setup fee per distinct part number on top of each component's
per-unit price. On a run of tens of boards, that setup cost dominates — so this design
deliberately fits a higher-specified part where a cheaper one would do, whenever that part is
already used elsewhere on the board. All the 4.7 µF positions share one 25 V 0805 part, for
instance, even where 6.3 V would be sufficient.

That yields 61 distinct part numbers across 112 placements. If you intend to build this at
volume, revisit those choices: once per-unit cost dominates, fitting the cheapest adequate part
in each position is the cheaper answer. Nothing electrical depends on it.

## Downloads

Interactive viewers hosted with the documentation site:

- **[Hub Interactive BOM](pathname:///ibom/)** — inspect component placements, values, and LCSC part numbers directly on the Hub board layout.
- **[Satellite Interactive BOM](pathname:///ibom-satellite/)** — inspect component placements and solder jumper configurations on the Satellite board layout.

Published per release on the [Releases page](https://github.com/JohnNeville/SunSprout/releases):

- **Schematic PDFs** — full multi-sheet vector schematics for both boards (`SunSproutHub-schematic_*.pdf`, `SunSproutSatellite-schematic_*.pdf`), regenerated directly from the KiCad source files.
- **3D models (STEP)** — board mechanical models (`SunSproutHub_*.step`, `SunSproutSatellite_*.step`), including the MCU module and embedded connector geometry.
- **Gerbers, BOM, and pick-and-place** — ready-to-order JLCPCB fabrication archives.

Large build outputs (schematic PDFs, 19 MB STEP mechanical models, and fabrication zips) are attached directly to each release on GitHub rather than committed to the repository history or static web bundle.

Everything above is a build artifact of the KiCad source. Regenerate the local documentation assets with `tools/generate-docs-assets.sh`; Docker is the only prerequisite there, and no local KiCad install is needed. The fabrication set, STEP models, and schematic PDFs are built automatically by the Release artifacts workflow.

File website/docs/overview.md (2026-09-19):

---
sidebar_position: 1
title: Overview
---

# SunSproutHub

:::warning[Work in progress — never fabricated or tested]

No physical board exists yet. Everything on this site is verified in software only: ERC and DRC
pass, values and pin assignments are checked against manufacturer datasheets, and the
fabrication outputs generate cleanly. Nothing has been powered on or measured.

The design is published at this stage to gather feedback before a fabrication run. Treat it as
an untested design rather than a finished product, and review it yourself before building one —
errors in the charging or protection circuitry could damage a battery.

:::

A compact power-management and connectivity board built around the **ESP32-C5**, designed to
take power from USB-C, a small DC/solar source, or a Li-ion/Li-Po battery — charge the
battery with true maximum-power-point tracking on the solar input, and regulate a clean 3.3V
system rail — while exposing two independent I2C buses for onboard and remote sensors.

Every IC's datasheet-required external components are drawn directly into the schematic rather
than treated as black-box breakout modules, and the board is hand-routed rather than
auto-generated.

## Physical

- 6-layer PCB (F.Cu, 4× inner, B.Cu).
- 10 external connectors: USB-C power input, screw-terminal DC/solar input, JST battery input,
  two STEMMA QT ports, two 8P8C (RJ45-style) differential-I2C jacks, two field-terminable
  thermistor connectors, and two GPIO expansion headers you fit yourself. See
  [Connectors](./connectors.md) for the full list.
- Two LEDs: a charge-status LED driven by the charger, and a firmware-controlled status LED.
- Three buttons: reset, boot-mode, and a wake button that brings the charger out of ship mode —
  or, held for ~10 seconds, hard power-cycles the whole board.
- U.FL external antenna connector (module-side), for installations where the onboard antenna
  isn't sufficient.

## Capabilities

### Compute & radio

| | |
|---|---|
| MCU | ESP32-C5-WROOM-1U |
| Wireless | Dual-band Wi-Fi 6, Bluetooth 5, 802.15.4, CAN FD |
| Antenna | U.FL external connector (module variant) |

### Power management

- **Li-ion/Li-Po battery charging** with JEITA temperature-qualified fast charge, via an
  onboard charge-temperature thermistor input.
- **Automatic source arbitration** between USB-C and the DC/solar input — both can be
  connected simultaneously; the charger ORs them into a single charge-path rail.
- **Fuel gauge** for state-of-charge tracking, with its own independent battery-temperature
  thermistor input (kept separate from the charger's, since each IC applies its own excitation
  to whatever's wired to its thermistor pin).
- **True MPPT on the solar input**, performed by the charger itself. It periodically samples
  the panel's open-circuit voltage and regulates to the corresponding maximum-power point,
  autonomously — no firmware control loop and no separate monitor IC involved.
- **Measurement from the charger's integrated 16-bit ADC** — input voltage, input current,
  battery voltage, battery current and temperature, all readable over I2C. Between that and the
  fuel gauge, every rail is covered without a dedicated power-monitor part.
- **Switched 3.3V "user" rail**, independent from the always-on system rail, that firmware can
  power down to save current when the secondary I2C bus and its downstream devices aren't
  needed.

### Other protections

- Reverse-polarity protection on both the battery and DC/solar inputs, sized to each source's
  expected voltage range. USB-C doesn't need one — it's a keyed, spec-defined connector.
- **ESD/TVS protection on the ports designed to carry a cable off-board**: the four
  differential I2C lines on the two 8P8C jacks, and the USB-C data lines. The USB `VBUS` rail
  gets its own TVS as well.

  The remaining connectors have **no** dedicated ESD parts — both STEMMA QT ports, the two GPIO
  expansion headers and the debug UART on them, both thermistor inputs, and the USB `CC` lines.
  Those are intended for sensors sitting close by inside the same enclosure. If you run a cable
  from one of them out of the enclosure, add protection at that end.
- Hardware alert/interrupt lines from the charger and the fuel gauge are wired to their own
  separate GPIOs, so firmware can react to a fault without polling — and without having to
  interrogate both devices to work out which one raised it.

## Interfaces

### I2C — two independent buses

- **Internal bus** — always-on, dedicated to the board's own power-management ICs (charger and
  fuel gauge) plus a local STEMMA QT connector for directly-attached sensors.
- **User bus** — switchable, feeding a PCA9615 differential I2C buffer that drives two 8P8C
  jacks, plus a second, separate STEMMA QT connector.

The differential side is wired to be compatible with the [SparkFun QwiicBus —
EndPoint](https://www.sparkfun.com/products/16988): same PCA9615 buffer, same 8P8C pinout, so
a standard Ethernet patch cable carries I2C from this board to an EndPoint, and Qwiic/STEMMA QT
devices plug into the EndPoint at the far end. That's how you get sensors metres away from the
hub instead of centimetres.

This board takes the pass-through role, so it carries **no termination resistors** on the
differential lines — the EndPoint at the far end provides them. It therefore needs to connect
to an EndPoint rather than acting as the end of a chain itself.

These buses are deliberately kept apart — see [Notes](./notes.md) for why that matters when
wiring things up.

### Connectors

See the dedicated [Connectors](./connectors.md) page for the full list with mating-part
guidance.

## Power

### Input

| Source | Connector | Notes |
|---|---|---|
| USB-C | `USBC1` | 5V USB-C power/data input. The charger runs BC1.2 and non-standard adapter detection over D+/D- to set its own input current limit. There is no USB-PD controller, so the port is 5V only; HVDCP (9V/12V) is reachable only from a USB-A QuickCharge supply over an A-to-C cable, and only if firmware enables it. |
| DC / small solar panel | `CN5` (screw terminal) | Wide-range DC input suitable for a small solar panel; can be connected at the same time as USB-C. |
| Battery | `J4` (JST PH, 2-pin) | Single cell. Double-check pack polarity against the board's silkscreen before connecting — JST-PH battery polarity isn't universally standardized across cable vendors. |

### Charging summary

| | |
|---|---|
| Charger | BQ25798, buck-boost, dual-input |
| Cell configuration | **1S**, set in hardware by the `PROG` resistor at power-on |
| Chemistry | Li-ion / Li-Po and LiFePO4 (the fuel gauge carries profiles for both) |
| Input voltage, either source | **3.6 V to 24 V** for a valid input; 30 V absolute maximum |
| Practical solar ceiling | **24 V**, the charger's own recommended maximum — the input protection no longer sets a lower one. The reverse-polarity FET on that input is self-biased, so the full input voltage appears across its ±20 V gate in normal operation as well as under a reversed source; a Zener gate clamp (`D2`) holds that within rating across the whole range. Size a panel by its cold-weather open-circuit voltage, which rises above the rated Voc. See [input protection](https://github.com/JohnNeville/SunSprout/blob/main/docs/hub/modules/input-protection.md). |
| Input current limit | **~2.0–2.1 A**, set in hardware by a resistor divider. Firmware cannot exceed it. The exact value tracks the charger's REGN rail, which is itself input-dependent — see below. |
| Charge current | Firmware-set over I2C. Defaults to **1 A**; **do not exceed 2 A** (see below). |
| Solar tracking | Autonomous open-circuit-voltage MPPT, run by the charger itself |
| Source arbitration | Both inputs may be connected at once; the charger's internal mux selects between them |
| Measurement | Integrated 16-bit ADC: input voltage/current, battery voltage/current, temperature |
| Temperature qualification | JEITA, via a thermistor on `J302` (not fitted — see [Connectors](./connectors.md)). **With no thermistor fitted the charger reads "too cold" and suspends charging** until firmware sets `TS_IGNORE`; see below. |

### Output

| Rail | Voltage | Description |
|---|---|---|
| System rail (always-on) | 3.3V | Powers the MCU, the internal power-management I2C bus, and its STEMMA QT connector (`J6`). |
| User rail (switched) | 3.3V | Powers the I2C differential buffer and its STEMMA QT connector (`J203`); firmware-controlled, defaults OFF at power-up. |

### Charging & PMU behavior

- **Input current limit: roughly 2.0 A to 2.1 A**, hardware-set by the `R302`/`R303` divider on
  the charger's `ILIM_HIZ` pin. This is an analog ceiling the charger enforces regardless of what
  firmware writes to the corresponding register. It caps the combined draw from whichever source
  (USB-C, DC/solar, or both at once) is feeding the charge path — it isn't the battery's charge
  rate.

  It is not a single fixed number, because the divider is referenced to `REGN`, and `REGN` itself
  depends on the input voltage. The charger computes the clamp as
  `V(ILIM_HIZ) = 1 V + 800 mΩ × I`, and the divider ratio is 130 k / (110 k + 130 k) = 0.542:

  | Input | `REGN` (typical) | Resulting limit |
  |---|---|---|
  | USB-C at 5 V | 4.8 V | **2.00 A** |
  | Solar or DC at 15 V | 5.0 V | **2.14 A** |
  | Across the full `REGN` spec, 4.6 V to 5.2 V | | **1.87 A to 2.27 A** |

  The divider was sized for the 5 V case. On a high-voltage input the ceiling sits about 7% above
  2 A, and worst-case silicon reaches 2.27 A — budget the copper for the top of that range, not
  for 2.00 A. The charger latches this clamp from an ADC reading taken at power-on before the
  converter starts switching, so whichever source is present at power-up sets it for that
  session.
- **Charging is enabled in hardware, but not currently sufficient on its own.** The charger's
  `CE` pin is tied to ground, so nothing has to be written to start a charge. The charger's own
  protections (OVP, OCP, thermal shutdown, UVLO) apply throughout.

  As built, though, a board with no firmware running **will not charge**, because of the
  thermistor. `J302` ships unpopulated, and the `TS` divider (`R305` 5.1 kΩ to `REGN`, `R306`
  30 kΩ to ground) then sits at 85.5% of `REGN`. Every JEITA cold threshold is below that —
  the 0 °C threshold is 73.3% of `REGN`, and even the −20 °C OTG threshold is 80% — so the
  charger reads a battery colder than its cold cutoff and suspends charging.

  The network is correct once a thermistor is present: a 103AT-type 10 kΩ NTC at 25 °C puts the
  divider at 59.5% of `REGN`, mid-window. **Fit one** — a Semitec 103AT-11 is the specified
  part; see [Connectors](./connectors.md). It is what the charger's datasheet expects, and the
  only arrangement that gives real JEITA temperature protection.

  To run without one, firmware must set `TS_IGNORE` (register `REG18`, bit 0), which tells the
  charger to treat the temperature as always acceptable. The bit defaults to 0 and TI lists it
  as reset by the watchdog and by a register reset; this board's firmware disables the watchdog,
  so in practice only the register-reset control clears it. That route gives up temperature
  qualification entirely, and the ESPHome driver does not currently expose the bit.

  There is deliberately no fixed resistor standing in for the thermistor. It would make the
  charger read a permanent 25 °C and report that as a real measurement, which is a worse
  failure than having no reading at all.
- **Battery charge current is firmware-configured** over I2C, and resets to that 1A default on
  power-up, on a watchdog timeout, and on a register reset. Program a charge current
  appropriate to your specific pack's capacity before relying on fast charging.
- **Firmware must not set the charge current above 2000mA.** Unlike the input limit, the charge
  current has no hardware ceiling, and in buck mode it can exceed the input current — so a
  higher setting can push the charge-side copper past its rating.
- **Ship mode and a true hardware power cycle**, via an external ship FET (`Q3`) on the
  charger's `SDRV` gate-driver pin. The FET sits in series in the battery path, so the charger
  can physically disconnect the pack from the system rail. That gives three states beyond normal
  operation: *ship mode* (FET off, I2C still alive — for shipping and storage), *shutdown* (FET
  off, I2C down, only an adapter brings it back), and a *system power reset* that drops the FET
  for ~350ms and actively pulls the `SYS` rail down before restoring it.
- **Holding `SW3` (WAKE) for about 10 seconds hard power-cycles the board.** This runs entirely
  inside the charger — no working firmware, no I2C — which makes it the recovery path when the
  MCU is wedged. A shorter press (~1s) just wakes the charger out of ship mode.

  Two caveats worth knowing. The reset cycles the `SYS` rail, so it restarts the MCU, both 3.3V
  rails and everything downstream of them — but *not* the charger itself (it's the thing
  performing the reset) and *not* the fuel gauge, which is deliberately wired to the pack side
  of the ship FET so it keeps coulomb-counting straight through. And since neither I2C device
  loses power, the reset can't unstick a hung I2C slave; that still needs the usual nine-clock
  recovery sequence in firmware.
- **Firmware must set the charger's `SFET_PRESENT` bit** (`REG14`, bit 7) during init. It
  defaults to 0, and while it's 0 the charger locks out every ship-FET mode above — the board
  behaves as though no FET were fitted.

### Current consumption

Not yet characterized — measurements will be added here once bring-up testing is complete.

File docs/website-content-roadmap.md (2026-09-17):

# Docs Site Content Roadmap

Tracks what's still missing or placeholder on the public docs site (`website/`), grouped by
what unblocks it. Update this alongside the site as items land — check items off or delete them
once done rather than letting it drift out of sync with the actual design.

## Blocking: needed before the site can go public at all

- [x] **Push this repo to GitHub** and enable Pages (Settings → Pages → Source: "GitHub
      Actions"). The deploy workflow (`.github/workflows/deploy-docs.yml`) is already scaffolded
      and inert until this happens.
- [x] **Fill in the real GitHub Pages URL** in `website/docusaurus.config.ts` — `url`,
      `organizationName`, and (if deploying to a project-page subpath) `baseUrl`. Currently
      placeholders.

## Near-term: fills in placeholders already on the live pages today

- [ ] **Design files download** (`website/docs/design-files.md` → Downloads section) — once the
      repo is public, publish gerbers/BOM/pick-and-place/STEP as a GitHub Release and link it
      here instead of the current "not yet available" placeholder.
- [ ] **Schematic PDF** (`website/docs/design-files.md` → Schematic section) — export and link a
      clean schematic PDF.
- [ ] **Current consumption numbers** (`website/docs/overview.md` → Power → Current consumption)
      — currently "not yet characterized." Fill in once bring-up/bench measurements exist,
      ideally broken out by state (deep sleep, Wi-Fi active, charging, etc.) the way PowerFeather-
      style hardware docs typically do — use real bring-up measurements rather than estimating.
- [ ] **Real board photos** — the site currently uses `kicad-cli`-rendered CAD images
      (`website/static/img/board-top.png` / `board-bottom.png`). Swap in or supplement with actual
      assembled-board photography once a unit exists.

## Later: new content, not just filling gaps

- [ ] **Getting Started guide** — first power-up steps, flashing firmware over native USB, LED
      status meanings, connecting a battery pack for the first time. This is genuinely new
      content (a "Guides" category alongside the existing "Hardware" one), not adapted from
      anything currently in `docs/`.
- [x] **Physical dimensions & mounting page** — done: `website/docs/dimensions.md` carries the
      outline, the M2.5 mounting pattern, and courtyard extents for every connector and control,
      all extracted from the PCB file.
- [ ] **Errata / hardware revision history** — currently only Rev A exists, so there's nothing to
      track yet, but this page should exist before a Rev B happens so changes have somewhere to
      land.
- [ ] **FAQ expansion** — `website/docs/notes.md` currently reflects known-gotchas identified
      during design review; real usage will surface more.

## Open decisions (not urgent, but worth deciding before the site gets wide traffic)

- Whether the site's own original prose needs an explicit license statement (separate from the
  Espressif CC BY-SA credit already on the Attribution page, which only covers that one vendored
  library, not writing original to this site).
- Whether to add site search (e.g. Algolia DocSearch) — only really useful once the site is
  public and indexed.

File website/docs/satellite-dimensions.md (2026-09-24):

---
sidebar_position: 2
title: Satellite Dimensions & Mounting
---

# Satellite Dimensions & Mounting

Everything on this page is measured from the production layout in
`hardware/satellite/SunSproutSatellite.kicad_pcb`. If you need exact three-dimensional geometry — component
heights, connector bodies, mating clearances — use the STEP model linked from
[Design Files](./design-files.md) rather than working from the numbers here.

---

## Board Outline

| Property | Value |
|---|---|
| **Outline Dimensions** | **27.25 × 51.10 mm** |
| **Thickness** | 1.6 mm |
| **Copper Layers** | 4 (`F.Cu`, `In1.Cu`, `In2.Cu`, `B.Cu`) |
| **Corners** | Square — no radius |
| **Cutouts / Notches** | None |

The outline is a clean, slender rectangle engineered to fit inside slim waterproof enclosures, electrical conduit, or outdoor probe housings. There is no asymmetrical keying cutout; orient the board by the RJ45 jack (`J1`) facing the cable entry point.

---

## Coordinate Frame

All positions below are given in millimetres from the **top-left corner of the board, viewed from the component (top) side**:
- **X = 0.0 mm** at the left edge, increasing to the **right** (+X).
- **Y = 0.0 mm** at the top edge, increasing **downward** (+Y).

This matches the coordinate convention used in KiCad 10 and aligns directly with the board layout and interactive pinout diagram.

---

## Mounting Holes

The board provides three non-plated mounting holes sized for standard M2 hardware:

| Hole | X (mm) | Y (mm) | Inset X | Inset Y | Purpose |
|---|---|---|---|---|---|
| **MP1** | 3.00 | 3.00 | 3.0 mm from left | 3.0 mm from top | Top-left corner mounting |
| **MP2** | 24.25 | 3.00 | 3.0 mm from right | 3.0 mm from top | Top-right corner mounting |
| **MP3** | 12.00 | 32.10 | 12.0 mm from left | Mid-board (32.1 mm) | Central mechanical standoff support |

### Mounting Hole Specifications

| Property | Value |
|---|---|
| **Drill Diameter** | **Ø2.1 mm** |
| **Fastener Size** | **M2** (screws or hex standoffs) |
| **Plating** | **Non-plated** (isolated from all internal copper and planes) |
| **Top Hole Span** | 21.25 mm (center-to-center between MP1 and MP2) |
| **Keep-out Diameter** | Ø4.5 mm circular annular clearance around each hole |

:::note[Non-Plated Holes]
Because the mounting holes are non-plated, metal screws or standoffs provide **no electrical ground connection** to the board. If chassis or shield grounding is desired, bond to the shield jumper (`JP13`) or a ground terminal on header `J7`.
:::

---

## Connector Locations & Clearances

All connectors are through-hole components mounted on the **top side** of the PCB:

| Ref | Function | Part / Type | Center X (mm) | Center Y (mm) | Orientation | Height Above PCB |
|---|---|---|---|---|---|---|
| **`J1`** | Differential I2C / Cable Input | Amphenol RJHSE5380 (8P8C / RJ45) | 15.95 | 45.20 | Facing bottom edge | ~13.5 mm |
| **`J6`** | 1-Wire Temperature Probe | JST PH 2.0mm 3-pin vertical | 3.65 | 8.30 | Vertical (left edge) | ~6.0 mm (~7.5 mm mated) |
| **`J2`** | Moisture Sensor Channel 1 | JST PH 2.0mm 3-pin vertical | 3.70 | 17.40 | Vertical (left edge) | ~6.0 mm (~7.5 mm mated) |
| **`J3`** | Moisture Sensor Channel 2 | JST PH 2.0mm 3-pin vertical | 3.65 | 26.50 | Vertical (left edge) | ~6.0 mm (~7.5 mm mated) |
| **`J4`** | Moisture Sensor Channel 3 | JST PH 2.0mm 3-pin vertical | 3.60 | 35.50 | Vertical (left edge) | ~6.0 mm (~7.5 mm mated) |
| **`J5`** | Moisture Sensor Channel 4 | JST PH 2.0mm 3-pin vertical | 3.60 | 44.50 | Vertical (left edge) | ~6.0 mm (~7.5 mm mated) |
| **`J8`** | Qwiic / STEMMA QT Extension | JST SH 1.0mm 4-pin vertical | 10.40 | 14.70 | Vertical (top-mid) | ~3.0 mm (~4.5 mm mated) |
| **`J9`** | Local Satellite Power (3.3V) | 1×2 Pin Header (2.54mm pitch) | 24.20 | 14.50 | Vertical (right edge) | ~8.5 mm mated |
| **`J7`** | Cable Bus Power Tap | 1×4 Pin Header (2.54mm pitch) | 24.20 | 25.10 | Vertical (right edge) | ~8.5 mm mated |

### Connector Spacing Highlights
- **Sensor Port Strip (`J6`, `J2`–`J5`)**: The five sensor connectors form a neat, uniform line along the left edge. The centers sit roughly 3.65 mm from the board edge, with a consistent **~9.0 mm vertical pitch** between successive connectors:
  - `J6` (Y = 8.30 mm)
  - `J2` (Y = 17.40 mm, Δ = 9.1 mm)
  - `J3` (Y = 26.50 mm, Δ = 9.1 mm)
  - `J4` (Y = 35.50 mm, Δ = 9.0 mm)
  - `J5` (Y = 44.50 mm, Δ = 9.0 mm)
- **RJ45 Differential Port (`J1`)**: Positioned at the bottom center (X = 15.95, Y = 45.20 mm). The jack's mating face is flush with the bottom board edge with the release latch facing downward towards the PCB.

---

## Solder Jumpers & Configuration Points

The board incorporates six configuration jumpers (five on the bottom side, one on the top side):

| Ref | Layer | Center (X, Y) | Silk Label | Default State | Function |
|---|---|---|---|---|---|
| **`JP1`** | **Bottom** | (12.00, 19.30) | `ADC 0x48 0x49 0x4A 0x4B` | **Pads 1-2 bridged** (Address `0x48`) | ADS1115 I2C address strap selector. Cut bridge to select alternate address. |
| **`JP11`** | **Top** | (20.30, 8.90) | `I2C PULL UP` | **Both pull-ups bridged** | Dual-trace single-cut jumper for local 4.7kΩ I2C pull-ups on `SCL_LOCAL`/`SDA_LOCAL`. |
| **`JP13`** | **Bottom** | (24.10, 38.30) | `SHLD GND` | **Bridged** | Bonds RJ45 metal shield (`J1.SHIELD`) to `RJ45_GND_1`. Cut for single-point grounding. |
| **`JP16`** | **Bottom** | (13.50, 12.40) | `1W ADDR` / `AD0 (+1)` `AD1 (+2)` `DEF (0x18)` `VCC (1)` | **Both grounded** (Address `0x18`) | Configures address strap pins on DS2482-100+ 1-Wire bridge using bit-weighting. |
| **`JP17`** | **Bottom** | (21.50, 17.30) | `GND_1 <-> GND` | **Bridged** | Bonds cable ground (`RJ45_GND_1`) to satellite system `GND`. Cut to isolate when powering externally. |
| **`JP18`** | **Bottom** | (24.00, 17.30) | `VCC_1 <-> 3V3` | **Bridged** | Passes Pair 1 cable power (`RJ45_VCC_1`) directly into local `SAT_3V3`. Cut to insert an external regulator between `J7` and `J9`. |

---

## Enclosure & Mechanical Clearances

When designing or choosing an enclosure for the SunSprout Satellite:

1. **Internal Cavity Width**: At least **29.0 mm** (providing ~0.9 mm clearance on both lateral sides of the 27.25 mm PCB).
2. **Internal Cavity Length**: At least **53.0 mm** for the PCB body, plus cable egress clearance.
3. **Cable Egress Clearance**: Allow at least **35.0 mm** clearance extending off the bottom edge (below `J1`) to accommodate the mating RJ45 plug body, strain relief boot, and minimum bend radius.
4. **Vertical Clearance (Top Side)**: At least **15.0 mm** above the top copper face. The RJ45 jack stands 13.5 mm tall; extra headroom ensures easy mating/unmating of the latch and vertical JST PH plugs.
5. **Vertical Clearance (Bottom Side)**: At least **2.5–3.0 mm** standoff clearance beneath the bottom copper layer to clear through-hole leads, clipped pins, and solder jumper beads.

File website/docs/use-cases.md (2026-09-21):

---
sidebar_position: 7
title: Use Cases
---

# Use Cases

:::warning[Not yet validated on this board]

The system described here runs today on an earlier, different board, with an off-the-shelf
SparkFun QwiicBus EndPoint standing in for the satellite. Neither half of the design
described on this page has been built yet: the hub has **not** been built, flashed, or
tested, and the satellite is a custom board (`hardware/satellite/`) that currently exists
only as a schematic-capture spec — no board has been fabricated, and the ESPHome
configuration has not been adapted to either board's components.

Treat this as the intended design, not a working recipe.

:::

## Garden soil monitoring

The design driver for this board: a solar-powered garden monitor where the sensors need to sit
some distance from the electronics.

```
  ┌──────────────────────┐              ┌───────────────────────────┐
  │  SunSproutHub        │              │  Satellite 1              │
  │  (weatherproof box)  │   Ethernet   │  SunSproutSatellite       │
  │                      │   patch      │  @ 0x48 ── 4 moisture     │
  │  solar panel ────────┤   cable      │           probes + 1 temp │
  │  battery      8P8C ──┼──────────────►└───────────────────────────┘
  │  ESP32-C5     8P8C ──┼──────────────►
  │                      │              ┌───────────────────────────┐
  └──────────────────────┘              │  Satellite 2              │
                                         │  SunSproutSatellite       │
                                         │  @ 0x49 ── 4 moisture     │
                                         │           probes + 1 temp │
                                         └───────────────────────────┘
```

The hub sits in one weatherproof enclosure with the panel and battery. Each satellite is its
own enclosure out among the plants, holding a `SunSproutSatellite` board
(`hardware/satellite/`) — a custom differential-I2C endpoint that integrates the PCA9615
buffer, the ADS1115, and a DS2484 for soil temperature onto one PCB, replacing what was
previously an off-the-shelf [SparkFun QwiicBus
EndPoint](https://www.sparkfun.com/products/16988) wired to a breadboarded ADS1115. An
ordinary Ethernet patch cable carries I2C to each one.

The board's two 8P8C jacks are wired in parallel onto the *same* differential bus, not two
separate ones — so a satellite can hang off either jack, or chain from another satellite. That
is why each ADC needs its own address.

The deployed system uses **two satellites covering eight plants** — four probes per satellite,
one per ADC channel.

### Why not just run the sensor wires

Capacitive soil probes output an analog voltage, and analog over a long run picks up noise and
drifts with wire resistance. Digitising at the plant and sending I2C differentially is far more
robust — and plain I2C itself won't survive the distance, which is what the differential buffer
on this board solves.

### Inside a satellite

| Part | Role |
|---|---|
| PCA9615 | Converts the differential pair back to standard I2C, and terminates the line — see `docs/satellite/modules/pca9615-i2c-endpoint.md` |
| ADS1115 | 16-bit ADC, four single-ended channels — one per moisture probe |
| DS2484 | I2C-to-1-Wire bridge, drives one DS18B20 soil-temperature probe |
| Capacitive soil probes | Up to four, one per ADS1115 channel |
| DS18B20 probe | One, on the DS2484's 1-Wire bus |

One PCB per enclosure keeps each satellite simple and puts the probes close to what
digitises them. Scaling means adding satellites, not stuffing more into one.

The ADS1115's address is strap-selected across `0x48`–`0x4B`, so up to four satellites can
share the bus — sixteen probes in total before addressing runs out. The deployed pair sit at
`0x48` and `0x49`.

Each probe is calibrated with a dry and a wet reference voltage, measured per-probe rather than
assumed — roughly 2.43 V dry and 1.12 V wet in the deployed setup, with one probe needing its
own value. Probes vary enough that this is worth doing individually.

### Power behaviour

Soil moisture changes slowly, so the node spends most of its life asleep: wake, read, publish,
sleep. The deployed configuration polls soil every 300 s and runs a 120 s awake window against
a 10 minute deep sleep cycle.

That pattern suits this board's switched user rail — the differential buffer and everything
downstream of it can be powered down between readings, leaving only the MCU, charger and fuel
gauge on the always-on rail. See [Overview](./overview.md#power).

## Adapting the existing configuration

The reference configuration is
[`plant_sensor.yaml`](https://github.com/JohnNeville/esphome-garden-sensor/blob/main/plant_sensor.yaml)
in the [esphome-garden-sensor](https://github.com/JohnNeville/esphome-garden-sensor)
repository. It targets the earlier board, so the satellite half carries over unchanged while
the hub half does not:

| | Earlier board | SunSproutHub |
|---|---|---|
| MCU | ESP32-S3 | ESP32-C5 |
| Charger | BQ25628E @ `0x6A` | BQ25798 |
| Fuel gauge | LC709204F @ `0x0B` | BQ34Z100 |
| Rail monitoring | INA3221 | Charger's integrated 16-bit ADC |
| I2C pins | GPIO35/36, GPIO47/48 | GPIO2/3 (internal, on `LP_I2C`), GPIO9/10 (user) — see [Pins & Signals](./pinout.md) |

The ADS1115 addressing, the soil-probe template, and calibration voltages carry over
unchanged, because nothing about them depends on which board is at the other end of the
cable. The `SunSproutSatellite` board itself is new, though — its DS2484/DS18B20
soil-temperature channel has no equivalent in the earlier configuration.

Three things are genuinely unresolved, and are the reason this page is marked work in progress:

- **ESPHome component support.** The earlier board's charger and fuel gauge had usable ESPHome
  components. Whether equivalents exist for the BQ25798 and BQ34Z100, or whether they need
  writing, has not been established.
- **MPPT handling.** The earlier configuration adjusted a target voltage in software based on
  the detected supply. This board's charger performs open-circuit-voltage MPPT in hardware, so
  that logic should be removed rather than ported — but that needs confirming against real
  behaviour once a board exists.
- **DS2484/DS18B20 support.** The earlier satellite had no soil-temperature channel, so
  `plant_sensor.yaml` has nothing to adapt here — this is new firmware work, not a port,
  once a `SunSproutSatellite` board exists to test it against.

## Other shapes this fits

Nothing about the board is specific to soil. The same hub-and-satellite pattern suits any
deployment where I2C sensors need to be metres from the power electronics: greenhouse climate
monitoring, water tank levels, or several satellites chained from one hub. The constraint is
I2C's — total bus capacitance and address collisions — rather than anything this board imposes.

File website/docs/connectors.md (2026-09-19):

---
sidebar_position: 4
title: Connectors
---

# Connectors

Ten external connectors, deliberately spread across distinct connector families by role —
so a solar source can't be physically mis-plugged into the battery input, and the two
temperature-probe inputs use a field-terminable connector rather than requiring a
pre-terminated probe.

The thermistor inputs use JST **PA**, not the JST **PH** of the battery input `J4`, precisely
so a cell can never be plugged into a `TS` sense pin. Both are 2.0 mm pitch; the housings do
not intermate.

| Ref | Type | Purpose | Mating part |
|---|---|---|---|
| `USBC1` | USB-C receptacle | USB-C power input | Any standard USB-C cable |
| `CN5` | 2.54mm screw terminal | DC / small solar panel input | Bare-wire or ferrule termination |
| `J4` | JST PH, 2-pin | Battery input | Single-cell Li-ion/Li-Po pack with a JST-PH cable — check polarity against the silkscreen before connecting |
| `J6` | JST SH, 4-pin (STEMMA QT) | Internal I2C bus — for sensors that should share the always-on power-management bus | Any STEMMA QT / Qwiic cable |
| `J203` | JST SH, 4-pin (STEMMA QT) | User I2C bus — for sensors on the switched, differential-buffer-side bus | Any STEMMA QT / Qwiic cable |
| `J201` / `J202` | 8P8C (RJ45-style) | Differential I2C — connects to a [SparkFun QwiicBus EndPoint](https://www.sparkfun.com/products/16988) for remote sensors | Standard Ethernet patch cable |
| `J2` | 2.54mm header (not fitted) | Optional external supply for the `VCC_2` rail on the 8P8C jacks — see [Notes](./notes.md#vcc_2-is-a-separate-cuttable-power-rail-on-the-8p8c-jacks) | Standard 2.54mm header strip, hand-soldered |
| `J302` | JST PA, 2-pin (`S02B-PASK-2`) | Charger thermistor input | Semitec 103AT-11 NTC thermistor (10kΩ @ 25°C), mounted on the battery pack — see [below](#terminating-your-own-thermistor-probe) |
| `J401` | JST PA, 2-pin (`S02B-PASK-2`) | Fuel-gauge thermistor input | A **second, separate** Semitec 103AT-11 NTC thermistor (10kΩ @ 25°C), also mounted on the pack |
| `J7` / `J8` | 2.54mm header (not fitted) | Spare/expansion GPIO breakout, plus the debug UART | Standard 2.54mm header strip, hand-soldered |

## Why two separate thermistors (J302 and J401)

The charger and fuel gauge each apply their own excitation/bias to whatever's wired to their
thermistor pin. Sharing a single NTC between both active bias circuits would give both ICs a
bad reading, so each gets its own thermistor — both mounted at the same physical location on
the battery cell.

## Terminating your own thermistor probe

`J302` and `J401` are JST PA 2-pin side-entry headers (`S02B-PASK-2`). To make up a probe cable:

| Part | Number | Notes |
|---|---|---|
| Housing | `PAP-02V-S` | 2-circuit, latching |
| Crimp contact | `SPHD-001T-P0.5` | AWG 28–22, insulation O.D. 0.76–1.5 mm |
| Thermistor | Semitec `103AT-11` | 10 kΩ @ 25 °C, B25/85 = 3435 K, 600 mm insulated lead |

The PA series is rated −40 °C to +105 °C and latches. Both matter for a probe that lives on a
battery pack: an intermittent `TS` connection reads as out-of-range and suspends charging, and
the connector should not be the narrowest part of the temperature range it is qualifying.

**Do not substitute the Semitec 103AT-2.** It is the same element electrically, but it ships as
a bare bead on 17 mm solid 42-alloy leads — too short for a crimp barrel, not ductile enough to
form a gas-tight crimp, and with no insulation for the support wings to grip. If you only have
103AT-2 parts, solder them to a 24–26 AWG stranded pigtail, heatshrink the joint, and crimp the
pigtail instead.

**A 3D-printer hotend thermistor will not work here**, despite the familiar-looking connector.
Those are 100 kΩ, B ≈ 3950 parts; the `R305`/`R306` divider is sized for 10 kΩ. Borrow the
connector ecosystem, not the part.

## Why two STEMMA QT ports

`J6` and `J203` sit on genuinely independent I2C buses (see [Pins & Signals](./pinout.md)) —
one always-on and dedicated to the board's own power-management ICs, the other switched and
shared with the differential-buffer path. Plugging a sensor into one vs. the other has real
electrical consequences; see [Notes](./notes.md).

## Controls

Three buttons, all on the top side:

| Ref | Label | Function |
|---|---|---|
| `SW1` | RESET | Pulls the MCU's `EN` pin low. Resets the board. |
| `SW2` | BOOT | Hold during a reset to enter firmware download mode. |
| `SW3` | WAKE | Pulls the charger's `QON` pin low — it does not go to the MCU. The hold time picks the action: a short press (~1s) wakes the charger from ship mode, bringing the board back after it has shut down to preserve the battery. **Holding for ~10 seconds triggers a full system power reset** — the charger opens the ship FET, actively pulls the `SYS` rail down, and restores it after ~350ms, restarting the MCU and both 3.3V rails. That path is pure hardware, so it works even with no firmware running. The charger and the fuel gauge stay powered through it. |

## Headers you fit yourself

`J7` and `J8` are on the board but **not factory-fitted**. They're excluded from both the bill
of materials and the pick-and-place file, so the assembler neither sources nor places them —
the pads are simply left bare for you to solder a standard 2.54mm header strip onto.

They break out the free GPIOs and the debug UART. Several of the exposed pins are strapping
pins, so check [Pins & Signals](./pinout.md) before loading one down at reset.

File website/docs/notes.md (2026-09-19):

---
sidebar_position: 6
title: Notes & FAQ
---

# Notes & FAQ

A few things that aren't obvious from the schematic alone.

## The two I2C buses are not interchangeable

This board has two independent I2C buses:

- **Internal bus** (`J6` STEMMA QT) — always-on, shared with the charger and the fuel gauge.
  Adding your own devices here means sharing bus time and address space with the board's own
  power-management traffic.
- **User bus** (`J203` STEMMA QT, plus the two 8P8C jacks via the differential I2C buffer) —
  switched, and electrically isolated from the internal bus by the buffer IC. This is the
  right bus for your own sensors and peripherals.

The 8P8C jacks speak differential I2C, not Ethernet. They use the same PCA9615 scheme and
pinout as the [SparkFun QwiicBus EndPoint](https://www.sparkfun.com/products/16988), so an
ordinary Ethernet patch cable runs from a jack here to an EndPoint, and your Qwiic/STEMMA QT
sensors plug into that. Don't plug a network switch into these — nothing will be damaged, but
nothing will work either.

This board is a pass-through node and carries no termination resistors, so the far end has to
be an EndPoint that provides them.

Downstream STEMMA QT/Qwiic accessories typically carry their own pull-up resistors, which
combine in parallel as you chain more devices onto a bus — worth keeping in mind if you chain
many devices onto the user bus.

## VCC_2 is a separate, cuttable power rail on the 8P8C jacks

Each 8P8C jack carries two power nets, not one. `VCC_1` feeds the differential I2C buffer
itself and is always tied to the board's 3.3V user rail. `VCC_2` — routed on its own wire pair
— is a second, independent rail that only reaches `VCC_1`/`GND` through two solder-jumper
bridges (`JP2` and `JP3`), which are shorted as shipped.

This mirrors the SparkFun QwiicBus reference layout, and it exists for one reason: to leave the
door open for powering hungrier sensors — soil-moisture ADCs, for example — at something other
than 3.3V, without a board revision. Cut `JP2` and `JP3` and `VCC_2` is fully isolated from this
board's own supply and ground. An unpopulated 2-pin header sits on that same net pair, ready to
accept an external 5V or 12V boost converter once the jumpers are cut.

Cutting the jumpers only isolates the rail here. The EndPoint at the far end of the cable needs
its own jumpers set to accept the injected voltage instead of drawing `VCC_2` from its own
`VCC_1`.

## J7 and J8 aren't fitted at the factory

These headers exist in the schematic and PCB layout, but they're excluded from both the bill of
materials and the pick-and-place file. The assembler leaves the pads bare. If you want them,
solder a standard 2.54mm header strip on yourself.

## Connector families are intentionally mismatched

The battery input (`J4`, JST PH) and the DC/solar input (`CN5`, screw terminal) use physically
different connector families on purpose, so a solar panel can't be plugged into the battery
input (or vice versa) even by accident.

## Reverse-polarity protection doesn't cover USB-C

The battery and DC/solar inputs both have reverse-polarity protection, sized to each source's
expected voltage range. USB-C doesn't — it's a mechanically keyed, spec-defined connector, so
there's no practical way to connect it backwards in the first place.

## Battery polarity

Double-check your battery pack's JST-PH cable polarity against the board's silkscreen marking
before connecting. JST-PH battery cables aren't universally standardized across vendors, and a
mismatched cable is one of the few ways to damage the board despite the onboard protection.

## The charger taps the USB data lines through cuttable bridges

The USB-C D+ and D- lines are shared. Each one meets the ESD diode `D5`, the MCU's native USB
peripheral, and the charger's BC1.2 detection input. The three branches join at `D5` itself,
whose footprint carries the junction internally so the clamp sits at a single star point.

The charger's branch runs through `R9` (D+) and `R11` (D-). These are **not** fitted resistors.
They are 0603 pads with a 0.3 mm copper bridge built into the footprint, shorted from the
factory and excluded from the assembly BOM. The charger therefore sees the data lines directly,
and BC1.2 detection works as intended on a prototype out of the box.

The bridges exist so the link can be broken later without a board revision. If the charger's
input capacitance turns out to disturb USB enumeration — most likely during firmware flashing —
cut the bridge through the soldermask window and, if a real value is wanted, hand-solder a 0603
resistor onto the same pads.

`JUMP_CHGR_GND2` is a three-way solder jumper that grounds the charger-side pins after a cut:
bridge the centre pad to one outer pad to ground D+, to the other to ground D-. Grounded is the
correct resting state for those pins, since a floating detection input can read as anything.

:::warning Cut before you ground
Bridging `JUMP_CHGR_GND2` while `R9`/`R11` are still intact shorts the live USB data lines to
ground and kills the port. Cut the bridges first, then ground. Nothing on the board prevents
this — the jumper is an open footprint and the bridges are declared as net ties, so neither
DRC nor the ratsnest will flag the mistake.
:::

Cutting a bridge also puts the board out of step with the design files, which continue to show
the nets as connected.

## Thermistors are required, not optional, for full charger/fuel-gauge behavior

The charger's JEITA temperature-qualified fast charging and the fuel gauge's temperature
compensation both depend on their respective thermistor inputs (`J302` and `J401`) actually
having a thermistor attached. Without them, both ICs still function, but you lose
temperature-qualified charging and accurate temperature-compensated state-of-charge.

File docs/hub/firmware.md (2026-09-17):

# Firmware

The board runs ESPHome. The configuration is in [`firmware/`](../../firmware/).

This page explains the firmware decisions. It does not explain how to flash a board. See
[firmware/README.md](../../firmware/README.md) for that.

## Why ESPHome

The board is a sensor hub. Its job is to read remote sensors and report them to a home
automation system. ESPHome does that work already. It also gives OTA updates, a Home
Assistant integration and a deep-sleep scheduler.

## Where the code lives

The configuration is split into two parts.

| Part | Location |
|---|---|
| Chip drivers for the BQ25798 and the BQ34Z100 | A separate repository, [esphome-bq-drivers](https://github.com/JohnNeville/esphome-bq-drivers) |
| Board configuration | `firmware/sunsprout-hub.yaml` in this repository |

The two chips are stock Texas Instruments parts. The drivers talk to the chips. They do not
know about this board. A separate repository lets other designs use them. It also matches the
layout that an ESPHome upstream contribution needs.

The board configuration stays here. It holds the values that the hardware sets: the pin map,
the charge limits and the sense resistor value. Those values belong next to the pages that
explain them.

## The charge voltage

The charger reads the `PROG` resistor at power-on. `R301` selects a 1S cell. The charger
then sets its battery voltage limit to **4.2 V**.

A LiFePO4 cell charges to **3.65 V**. 4.2 V damages it.

The configuration declares the cell chemistry. The driver derives the charge voltage limit
from that chemistry. It writes the limit during setup. It writes the limit again after a
register reset.

The firmware does not give a control for the charge voltage. A user must not be able to
change a limit that protects the cell. The chemistry sets the limit, and nothing else does.

## The two I2C buses

The MCU has one general-purpose I2C controller. It also has one low-power I2C controller.
The low-power controller works only on GPIO2 for `SDA` and GPIO3 for `SCL`.

The board connects `SDA_INT` to GPIO2. The board connects `SCL_INT` to GPIO3. Both match.

The internal bus therefore uses the low-power controller. The user bus uses the
general-purpose controller. Both buses work at the same time.

An earlier revision connected `SCL_INT` to GPIO1. That pin does not match. Neither bus could
then use the low-power controller, and the two buses had to share the one general-purpose
controller. Only one bus worked. The design moved the net to GPIO3 to correct this.

**Do not move the `SDA_INT` or `SCL_INT` nets.** The low-power controller accepts no other
pin pair. Any other pin returns the board to the earlier fault.

GPIO3 is also `MTDI`. `MTDI` is a strapping pin. It selects the SDIO sampling edge together
with GPIO25. Its default state is floating. The bus pull-up resistor sets the strap to 1 at
reset.

This board does not use the SDIO interface. The strap value therefore has no effect. GPIO2
is the `MTMS` strapping pin and carries the same pull-up, so the design already accepts this
condition.

## The watchdog

The charger has an I2C watchdog. The default period is 40 seconds. When the watchdog
expires, the charger returns the charge current, the charge voltage and several other
registers to their `PROG` defaults.

For this board, that means the charge voltage returns to 4.2 V.

The firmware disables the watchdog. A watchdog that can damage the cell gives no safety.

## The charge current limit

`R302` and `R303` limit the input current. That limit is analog. Firmware cannot exceed it.

The limit is not exactly 2.00 A. The divider is referenced to `REGN`, and `REGN` tracks the
input voltage: about 2.00 A from a 5 V USB source, about 2.14 A from a 15 V solar input, and
1.87 A to 2.27 A across the full `REGN` spec. See
[Battery charger](modules/bq25798-charger.md) for the derivation.

The charge current has no equivalent hardware limit. In buck mode, the charge current can be
larger than the input current. The board copper carries 2 A.

The firmware therefore applies its own ceiling of 2000 mA. The driver clamps every write to
that value. See [Battery charger](modules/bq25798-charger.md).

## The battery thermistor blocks charging

`J302` ships with no thermistor. The `TS` divider then sits at 85.5% of `REGN`, which is above
every JEITA cold threshold — the 0 °C threshold is 73.3% of `REGN`. The charger reads a cell
colder than its cold cutoff and **suspends charging**. A board with no thermistor does not
charge, whatever the firmware does.

The charger offers `TS_IGNORE`, bit 0 of `REG18`, to disable the check. **The driver does not
expose it.** The `ts_resistor_upper`, `ts_resistor_lower`, `ts_nominal_resistance` and `ts_beta`
options convert the `TS` reading into a reported temperature; none of them writes `REG18`.

Two consequences while that remains true:

- The board needs a thermistor on `J302` before it will charge. Fit a Semitec 103AT-11 — a
  103AT-type 10 kΩ NTC, which is the part the charger datasheet recommends, in the variant
  that ships on 600 mm of insulated lead you can crimp.
- The **Battery Temperature** sensor reads implausibly cold on a board with `J302` open,
  because the driver is solving for a thermistor that is not there. Treat a wildly cold
  reading as "no thermistor fitted", not as a real measurement.

Adding a `ts_ignore` option to the driver would let a thermistor-less board charge, at the cost
of giving up temperature qualification entirely. That is the honest way to run without a
thermistor: `TS_STAT` reports `000` and the configuration says plainly that the check is off.
Because this board disables the charger watchdog, the bit would persist once written — only a
register reset clears it.

A fixed resistor in place of the thermistor was considered and rejected. It would make the
charger read a constant 25 °C and publish that as a measurement.

## Maximum power point tracking

The charger has a VOC-based MPPT algorithm. The charger stops switching at an interval. It
measures the open-circuit input voltage. It then sets its input voltage limit to a fraction
of that voltage.

The firmware enables this algorithm. It does not track the maximum power point itself.
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

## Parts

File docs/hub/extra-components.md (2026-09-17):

# Extra / Off-Board Components

Hardware that isn't part of this board's own BOM but is required (or optional) for the design
to work as intended — things you need to source and wire in separately, usually onto the
battery pack itself.

## J302 — charger thermistor input (BQ25798 TS)

- **Connector:** JST PA 2-pin, side entry (`S02B-PASK-2`, LCSC `C265094`), net `TS_NODE`/GND,
  biased on-board from the charger's `REGN` rail by the R305/R306 divider (5.1kΩ / 30kΩ).
- **Required part:** a **Semitec 103AT-11 NTC thermistor (10kΩ @ 25°C, B25/85 = 3435 K)**
  mounted directly on/against the battery cell.
- **Purpose:** feeds BQ25798's TS pin for JEITA charge-temperature qualification (charger
  won't fast-charge outside its configured safe temperature window without this).
- **Status:** intended, not yet physically sourced/mounted.

## J401 — fuel gauge thermistor input (BQ34Z100 TS)

- **Connector:** JST PA 2-pin, side entry (`S02B-PASK-2`, LCSC `C265094`), net `FG_TS_NODE`,
  biased from the gauge's own `REG25` rail (the IC's internal pull-down means no external bias
  resistor is needed here).
- **Required part:** a second, separate **Semitec 103AT-11 NTC thermistor (10kΩ @ 25°C,
  B25/85 = 3435 K)**, also mounted on/against the battery cell.
- **Purpose:** lets BQ34Z100 read pack temperature directly in hardware via its TH pin, instead
  of firmware having to compute temperature elsewhere and write it into the fuel gauge's
  Temperature register over I2C. This was a deliberate choice to keep temperature reporting out
  of firmware.
- **Why a separate thermistor from J302, not a shared one:** BQ25798 and BQ34Z100 each apply
  their own excitation/bias to whatever's on their thermistor pin — sharing one physical NTC
  between two active bias circuits would give both ICs a bad reading. Two independent 103AT-11
  units (both mounted at the same physical location on the cell) is the correct approach.
- **Status:** intended, not yet physically sourced/mounted.

## J4 — main battery connector

- **Connector:** JST PH 2-pin (`Connector_JST:JST_PH_S2B-PH-K_1x02_P2.00mm_Horizontal`),
  labeled "BATTERY" in the schematic.
- **Required part:** the Li-ion/Li-Po battery pack itself (cell + any pack-level protection),
  sourced separately — standard JST-PH 2-pin battery cable.
- **Status:** external to this board by design; no action needed here beyond having a pack with
  a matching JST-PH connector.

## J7 / J8 — expansion headers (optional)

- **Connectors:** 2.54mm pin headers (1x08 and 1x10), both marked DNP — the board ships without
  them.
- **Required part:** standard 2.54mm pin header strip, hand-soldered, only if you want the free
  GPIOs or the debug UART broken out. See [docs/modules/esp32-c5-mcu.md](modules/esp32-c5-mcu.md)
  for which pins land where, and which of them are strapping pins.
- **Status:** optional, not needed for the board to function.

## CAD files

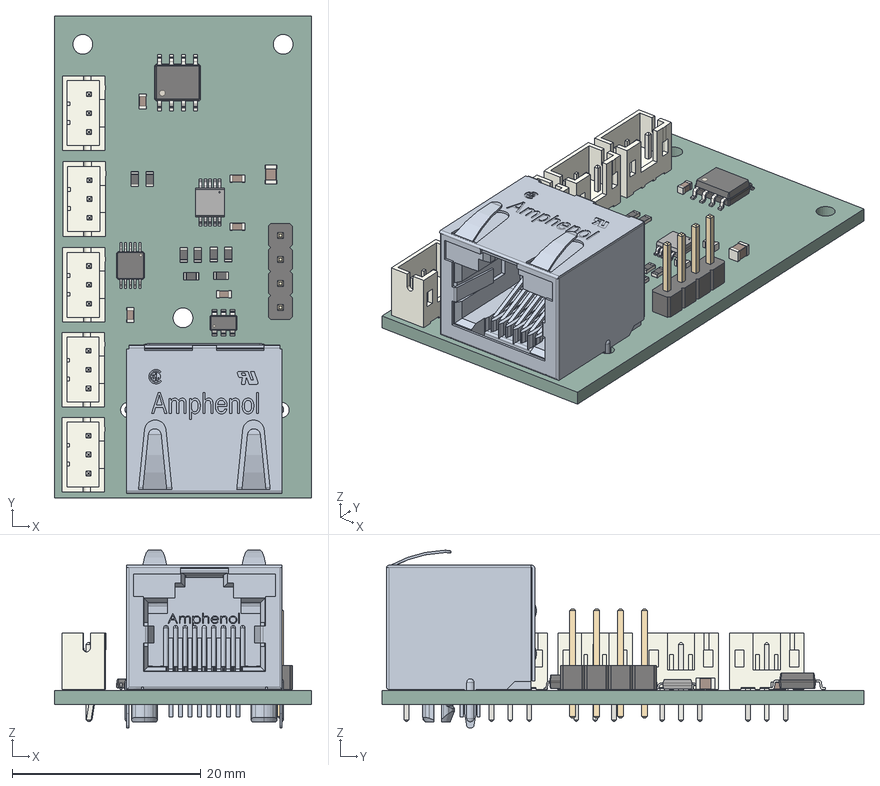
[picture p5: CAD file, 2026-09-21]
hardware/satellite/PCBModel.step
27.2 x 51.1 x 18.8 mm
R_0603_1608Metric x 8
C_0603_1608Metric x 5
JST_B3B_PH_K x 5
M-RJHSE-5380-REVT1
TSSOP-10_3x3mm_P0.5mm
SOT-23-6
C_0805_2012Metric
PinHeader_1x04_P254mm_Vertical
SOIC-8_3.9x4.9mm_P1.27mm
SunB146_PCB

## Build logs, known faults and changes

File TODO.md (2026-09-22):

# SunSprout Project TODOs

## Satellite PCB (`hardware/satellite/`)

See the detailed action items in [hardware/satellite/TODO.md](hardware/satellite/TODO.md):

- [x] **Reference Plane on `In2.Cu`:** Added `GND Fill In2` copper pour and `VCC_2` power plane zone on `In2.Cu` to provide continuous reference plane for `B.Cu` differential and I2C traces.
- [x] **ESD Diode (`U4`) Flow-Through Routing:** Eliminated branch stubs on `DSCL` and `DSDA`; traces now flow directly through SMT pads before reaching `U1`.
- [x] **RJ45 Shield Trace Width:** Replaced 0.2mm trace with dedicated copper pour `SHIELD GND Area` on `B.Cu`.
- [x] **Decoupling Capacitor Ground Inductance:** Widened GND traces on all decoupling capacitors `C1`-`C6` (`C1`: 0.40mm, `C2`: 0.60mm, `C3`: 0.60mm, `C4`: 0.50mm, `C5`: 0.50mm, `C6`: 0.50mm).
- [x] **PCA9615 Ground Pin:** Widen `U1.pin5` ground trace to 0.4mm-0.5mm (completed: 0.40mm trace to GND via at 115.5, 118.5).
- [x] **Differential Pair Coupling:** Tighten and match spacing between `DSCL_P/N` and `DSDA_P/N` pairs and align transition vias (`DSDA` vias tightened to 1.30mm; `DSCL` aligned horizontally).
- [x] **Ground Stitching Vias:** Placed adjacent ground return vias across both differential pairs and local I2C signal layer transitions (board via count increased to 58).
- [x] **Analog Crosstalk:** Increase spacing between `MOIST3` and `MOIST4` from 0.35mm edge-to-edge to >= 0.6mm (completed: 0.700mm edge-to-edge / 0.900mm center-to-center on F.Cu).
- [x] **Acid Traps:** Eliminated acute corners and hairpins on `F.Cu`, `B.Cu`, and `In2.Cu`; enforced JLCPCB DRC rule `track_angle >= 90deg` (0 violations).
- [x] **J7 Footprint Metadata:** Updated `Usage` property to `"Auxiliary 1x4 2.54mm header: Pin 1: VCC_2, Pin 2: GND_2, Pin 3: GND, Pin 4: SAT_3V3 (power breakout and bus injection)"`.
- [x] **DFM Test Points (`B.Cu`):** Added 2-pole 1.0mm test points `TP4` (`DSCL+/-`) and `TP5` (`DSDA+/-`) on `B.Cu`; power, GND, and local I2C probed via accessible solder jumpers.
- [x] **Optical Fiducial Markers:** Added 4 optical fiducials on `F.Cu` (`Fiducial_0.5mm_Mask1mm`) across board quadrants for automated SMT pick-and-place.

---

## Hub PCB (`hardware/hub/`)

See the detailed action items in [hardware/hub/TODO.md](hardware/hub/TODO.md):

- [x] **BQ25798 Charger Switching Nodes (`SW1_NODE` & `SW2_NODE`):** Enhanced with 0.3mm pad escape necking into a 3-via parallel cluster on `F.Cu`, wide polygon pours on `B.Cu`, and 2 parallel vias connecting into inductor `L1` pads.
- [x] **High-Frequency Loop Necking (`PMID_NET` & `SYS_RAIL`):** Expanded `U8` pin 29 (`PMID`) and pin 25 (`SYS`) connections into solid polygon pours directly to their high-frequency decoupling capacitors, minimizing loop inductance and ripple.
- [x] **Bootstrap Capacitor Loops (`C317` & `C318`):** Kept on `F.Cu` to preserve single-sided SMT assembly, routed with via transitions per TI BQ25798 datasheet Section 8.4.1 (which explicitly validates vias on both sides of BTST caps).
- [x] **Battery Path Trace Widths (`VBAT`, `VBAT_RAW`, `VBAT_PROTECTED`):** Covered `U8` pins 22/23 entry with a 0.8mm polygon pour, and widened `VBAT_RAW` / `VBAT_PROTECTED` tracks with filled pin connections to minimize IR drop and localized resistance at 2A.
- [x] **Fuel Gauge Shunt (`R60`) Kelvin Sensing & Filtering:** Re-routed `FG_SRN` and `BATT_RTN` as an ultra-short (2.78 mm), tightly coupled parallel pair from the inner edges of `R60` pads directly to `U3` pins 9/10 (matched to within 0.007 mm), eliminating solder/pad IR drop errors.
- [x] **ESP32-C5 Boot Button Rewiring:** Re-routed `SW2` / `C21` (`BTN1_NODE`) to `GPIO28` instead of `GPIO0`, and exposed `GPIO0` on header `J7 pin 3`.
- [x] **Mass Programming Pogo-Pin Test Points:** Added `TP16` (`U0RXD`), `TP17` (`U0TXD`), `TP18` (`BTN1_NODE` / `GPIO28`), and `TP19` (`RESET_NODE`) on `B.Cu` to enable automated single-sided bed-of-nails flashing.
- [x] **Inner Layer Copper Balance (`In2.Cu` & `In3.Cu`):** Added full-board GND fill zone (`"Inner GND fills"`) across `In2.Cu` and `In3.Cu` with filled copper polygons to balance layer density and mitigate board warpage during reflow.
- [x] **Acid Traps:** Cleaned up acute corners and trace reversals across the board; verified with KiCad custom DRC rule (0 violations).
- [x] **Firmware Sleep Leakage Prevention:** Float `GPIO9`/`GPIO10` (to stop 1.40 mA into `R201`/`R202` on unpowered `3V3_USER`) and clear BQ25798/BQ34Z100 interrupts before sleep (to stop 660 uA on `R24`/`R401`).

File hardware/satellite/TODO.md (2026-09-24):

# SunSprout Satellite PCB -- Layout & Routing Review Action Items

This document tracks electrical, signal integrity, power integrity, and DFM improvements identified during post-DRC routing review of `SunSproutSatellite.kicad_pcb`.

---

## 1. High Priority (Reliability, Protection & Signal Integrity)

- [x] **Add Reference Planes to `In2.Cu` and `In1.Cu` (Copper Flood / Zone Splits)**
  - **Status:** **Completed.** 
    - **`In2.Cu` (directly adjacent to `B.Cu` differential pairs across 0.10mm prepreg):** Split into 2 zones: `SAT GND` covering the main board, and `RJ45_GND_1` providing an unbroken, solid ground reference plane under 100% of the differential I2C traces on `B.Cu`.
    - **`In1.Cu` (adjacent to `F.Cu`):** Split into 3 zones: `SAT GND` covering sensor circuitry, `RJ45_GND_1` under differential components, and a large bottom-right copper pour for `RJ45_VCC_2`.
  - **Issue:** Inner planes previously lacked proper zone definitions and grounding separation between raw cable domain and clean sensor ground.
  - **Resolution:** Re-architected both inner layers with clean boundary splits and continuous reference under all high-speed and differential signals.

- [x] **Decouple Cable Power Entry & Add External Buck Header (`C1`, `JP18`, `JP17`, `J7`, `J9`)**
  - **Status:** **Completed.** 
    - Placed bulk capacitor `C1` (22µF) directly across raw cable entry nets `RJ45_VCC_1` and `RJ45_GND_1`.
    - Tied `U1` `VDDB`, differential bus termination pull-ups/pull-downs (`R3`-`R8`), and TVS `U4` to `RJ45_VCC_1` and `RJ45_GND_1`.
    - Added cuttable normally-closed solder jumpers `JP18` (`RJ45_VCC_1` $\leftrightarrow$ `SAT_3V3`) and `JP17` (`RJ45_GND_1` $\leftrightarrow$ `GND`).
    - Standardized `J7` as 4-pin cable bus power breakout: Pin 1 = `RJ45_VCC_1`, Pin 2 = `RJ45_GND_1`, Pin 3 = `RJ45_GND_2`, Pin 4 = `RJ45_VCC_2`.
    - Added `J9` 2-pin header for local satellite power: Pin 1 = `SAT_3V3`, Pin 2 = `GND`, enabling plug-and-play external buck converter attachment for long-distance runs (>20m).

- [x] **Route ESD Diode (`U4`) In-Line Without Stubs (Flow-Through Routing)**
  - **Status:** **Completed.** Re-routed differential lines (`DSCL_P/N`, `DSDA_P/N`) so signals enter `U4` pads directly and exit towards termination resistors and `U1`, eliminating the previous 1.4mm-2.5mm dead-end side stubs.
  - **Issue:** Dead-end stubs to `U4` added parasitic inductance that compromised sub-nanosecond transient ESD clamping into `U1` (`PCA9615`).
  - **Resolution:** Replaced branching stubs with direct in-pad entry/exit routing.

- [x] **Widen RJ45 Cable `SHIELD` Trace to >= 1.5mm - 2.0mm**
  - **Status:** **Completed.** Replaced the narrow 24mm long 0.2mm trace on `B.Cu` with a dedicated copper flood zone polygon: `SHIELD GND Area` on `B.Cu` (`min_thickness 0.25mm`), providing a robust, low-inductance connection from RJ45 tabs `SH1`/`SH2` to `JP13`.
  - **Issue:** A 0.2mm trace on `SHIELD` posed impedance and surge-handling risks during cable discharge events (CDE).
  - **Resolution:** Converted the entire shield connection into a solid polygon pour on `B.Cu`.

- [x] **Optimize Decoupling Capacitor GND Connections (`C1`-`C6`)**
  - **Status:** **Completed.** All decoupling capacitor GND connections widened (`C1`: 0.40mm, `C2`: 0.60mm, `C3`: 0.60mm, `C4`: 0.50mm, `C5`: 0.50mm, `C6`: 0.50mm), minimizing parasitic loop inductance.
  - **Resolution:** Widened GND traces on F.Cu to 0.40mm-0.60mm.

- [x] **Widen PCA9615 (`U1`) Pin 5 (`VSS`/`GND`) Connection**
  - **Status:** **Completed.** Connection from Pin 5 at (115.5, 117.665) to GND via (115.5, 118.5) widened to 0.40mm on `F.Cu`, minimizing driver sink inductance and mitigating ground bounce.
  - **Resolution:** Re-routed with 0.40mm width.

---

## 2. Medium Priority (Differential Symmetry, Crosstalk & Return Paths)

- [x] **Tightly Couple Differential I2C Pairs (`DSCL_P/N` and `DSDA_P/N`)**
  - **Status:** **Completed.** `DSDA` transition vias tightened to 1.30mm center-to-center. `DSCL` pair aligned horizontally at Y=134.6mm. Straight differential runs maintain tight 0.20mm-0.25mm edge-to-edge coupling.
  - **Resolution:** Vias aligned and tightened; skew compensation matched.

- [x] **Add Ground Stitching Vias at Signal Layer Transitions**
  - **Status:** **Completed.** Ground stitching vias placed adjacent to signal layer transitions across both differential pairs (`DSCL_N` at 1.11mm, `DSCL_P` at 1.32mm, `DSDA_P` at 1.46mm) and local I2C lines (`SDA_LOCAL` at 1.05mm, `SCL_LOCAL` at 1.29mm). Total board vias increased to 58.
  - **Resolution:** Return current loop area minimized at every transition.

- [x] **Increase Isolation Between Analog Sensor Inputs (`MOIST3` & `MOIST4`)**
  - **Status:** **Completed.** Increased center-to-center spacing along the 6.4mm parallel run on `F.Cu` (Y=131.69 to 138.10) to 0.900mm (0.700mm edge-to-edge), exceeding the >= 0.6mm target to prevent capacitive sensor crosstalk.
  - **Resolution:** Offset `MOIST4` to X=105.900mm (0.70mm isolation from `MOIST3` at X=105.000mm).

---

## 3. Low Priority (DFM & Documentation Consistency)

- [x] **Eliminate Acute 45 deg Corners and Trace Hairpins (< 90 deg Acid Traps)**
  - **Status:** **Completed.** Cleaned up acute trace angles, added JLCPCB track angle rule constraint (`track_angle >= 90deg`) in `SunSproutSatellite.kicad_dru`, and verified with KiCad DRC passing with 0 design violations.
  - **Resolution:** Acute junctions on In2.Cu, B.Cu shield, and F.Cu diff traces eliminated.

- [x] **Update J7 & J9 Footprint Property Descriptions**
  - **Status:** **Completed.** Updated footprint `Usage` property in schematic and PCB:
    - `J7`: `"Auxiliary 1x4 2.54mm header: Pin 1: RJ45_VCC_1, Pin 2: RJ45_GND_1, Pin 3: RJ45_GND_2, Pin 4: RJ45_VCC_2"`
    - `J9`: `"Local Satellite Power 1x2 2.54mm header: Pin 1: SAT_3V3, Pin 2: GND"`
  - **Resolution:** Metadata accurately matches physical pinout.

- [x] **Add Dedicated Test Points on `B.Cu` for Production & Bench Probing**
  - **Status:** **Completed.** Added 2-pole 1.0mm test point pads on `B.Cu`: `TP4` for differential clock (`DSCL_P` / `DSCL_N`) and `TP5` for differential data (`DSDA_P` / `DSDA_N`). Dedicated test points for `SDA_LOCAL`, `SCL_LOCAL`, `GND`, and `SAT_3V3` are intentionally omitted as accessible solder jumpers for the address pin (`JP1`, etc.) and power jumper pads for `VCC_1` / `VCC_2` already provide direct probe access.

- [x] **Add Optical Fiducial Markers on `F.Cu` and `B.Cu`**
  - **Status:** **Completed.** Added 4 optical fiducial markers on `F.Cu` (`Fiducial_0.5mm_Mask1mm`) distributed across board quadrants for automated SMT pick-and-place alignment.
  - **Resolution:** Added fiducials at (113.9, 122.3), (106.6, 102.9), (123.9, 133.7), and (124.2, 106.5).

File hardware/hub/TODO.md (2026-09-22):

# SunSprout Hub PCB — Layout & Routing Review Action Items

This document tracks electrical, power integrity, thermal, signal integrity, and DFM improvements identified during post-DRC routing review of `SunSproutHub.kicad_pcb`.

---

## 1. High Priority (Critical Power, Thermal & SMPS Reliability)

- [x] **Strengthen Charger Switching Nodes (`SW1_NODE` & `SW2_NODE`) Via Transitions and Fanout**
  - **Status:** **Completed.** Implemented 0.30mm pad fanouts into parallel 3-via clusters at `U8` pins 26/28, wide low-inductance polygon fills on `B.Cu`, and parallel 2-via clusters at `L1` pads.
  - **Context & Design Ceiling:** The system input current ceiling is limited to 2A and firmware limits charging current to 2A. Section 8.4.2 of the BQ25798 datasheet demonstrates routing switching nodes through vias to the bottom layer (`B.Cu`), which validates the layer-hopping topology.
  - **Issue:**
    - Pins 28 (`SW1`) and 26 (`SW2`) originally exited their QFN pads with narrow **0.20mm (8 mil) traces** over ~0.8mm–1.3mm before reaching a single via.
    - Transitioning through only a single 0.3mm drill via added ~1.2 nH parasitic inductance to the fast switching loop.
  - **Resolution:**
    - Kept the `F.Cu` pad escape necking at 0.30mm over the short ~0.8mm exit to comfortably satisfy DRC clearances.
    - Expanded into 3 parallel vias on `F.Cu` / `B.Cu` under the IC and 2 parallel vias at `L1`, cutting transition inductance by >60% and dividing current to <0.7A/via.
    - Replaced the single 0.8mm trace with wide polygon fills on `B.Cu` for low AC impedance.

- [x] **Widen High-Frequency Loop Connections on `PMID_NET` and `SYS_RAIL`**
  - **Status:** **Completed.** Fanned out `U8` pins 29 (`PMID`) and 25 (`SYS`) into solid polygon pours directly bridging into their respective decoupling capacitors on `F.Cu`, eliminating 0.20mm bottlenecks and minimizing switching ripple and loop inductance.
  - **Issue:**
    - Pin 29 (`PMID`) of `U8` carries high-frequency discontinuous input current and was necked down to a **0.20mm trace for 0.82mm** (from 50.57, 73.01 to 50.57, 72.19) before reaching its capacitor.
    - Pin 25 (`SYS_RAIL`) was necked down to a **0.20mm trace for 1.57mm** (from 52.37, 73.04 to 52.88, 71.67) before fanning out.
  - **Impact:** Choked high-frequency decoupling capacitor charge delivery, increased input/output voltage ripple, and caused unnecessary $I^2R$ power loss.
  - **Resolution:** Replaced narrow traces with wide polygon pours on `F.Cu` directly connecting IC pins to capacitor pads, passing full DRC.

- [x] **Bootstrap Capacitor Loops (`C317` / `C318`) Placement and Routing**
  - **Status:** **Completed / Closed as Designed.** Retained `C317` and `C318` on `F.Cu` connected via layer transitions.
  - **Rationale & Datasheet Reference:** TI BQ25798 datasheet Section 8.4.1 (Priority 2) explicitly states: *"The BTST capacitors can be connected with vias on both sides."* Unlike the continuous high-frequency multi-amp current loops on `PMID` and `SYS`, bootstrap capacitors only provide pulsed gate drive charge to the high-side FETs and recharge from `REGN`.
  - **DFM Advantage:** Keeping `C317` and `C318` on `F.Cu` alongside all other passives preserves single-sided SMT assembly, eliminating the costs, stencils, and yield risks of a double-sided SMT process.

- [x] **Widen Battery & High-Current Power Paths (`VBAT`, `VBAT_RAW`, `VBAT_PROTECTED`)**
  - **Status:** **Completed.** Entry into `U8` pins 22/23 is covered with a 0.8mm polygon pour, eliminating the 0.30mm neck, and `VBAT_RAW` / `VBAT_PROTECTED` high-current battery paths have wide tracks with solid filled pin connections.
  - **Issue:**
    - Battery net `VBAT` previously dropped to **0.30mm** at `U8` pins 22/23 over ~2.9mm of segments.
    - Battery lines required solid wide copper connections to handle the 2A charge/discharge current with minimal IR drop.
  - **Resolution:** Upgraded the `U8` pins 22/23 entry to a 0.8mm polygon pour and ensured wide tracks with solid pad connections across the battery path.

---

## 2. Medium Priority (Precision Sensing, Crosstalk & RF)

- [x] **Correct Kelvin Sense Routing on Fuel Gauge Shunt Resistor (`R60`)**
  - **Status:** **Completed.** Re-routed `FG_SRN` and `BATT_RTN` as an ultra-short (2.78 mm), tightly coupled parallel pair from the inner corners of `R60` pads directly to `U3` pins 9/10, matched to within 0.007 mm.
  - **Issue:**
    - `R60` is a 10 mOhm 1206 current sense resistor. Previously, sense traces connected to the outer edges of the pads where high-current traces entered, including solder fillet and copper pad resistance in the measurement.
    - Sense lines originally diverged with a large open loop area.
  - **Resolution:**
    - Connected both sense traces directly to the inside edges of `R60` pads (under the component body), bypassing all power return current and eliminating the 10%-20% measurement offset.
    - Routed as a matched parallel pair (2.7804 mm vs 2.7876 mm) with minimal loop area for high common-mode noise rejection.

- [x] **Balance Copper on Inner Signal Layers (`In2.Cu` & `In3.Cu`)**
  - **Status:** **Completed.** Added full-board GND fill zone (`"Inner GND fills"`) across `In2.Cu` and `In3.Cu` (Priority 1, 0.5mm clearance, 0.25mm min thickness), ensuring balanced copper distribution across the 6-layer stackup to eliminate reflow warpage.

- [x] **Rewire Hardware Boot Button (`SW2`) to `GPIO28` Instead of `GPIO0`**
  - **Status:** **Completed.** `U1` Pin 15 (`GPIO28`) is now connected to `BTN1_NODE` (`SW2` and debounce cap `C21`), and `GPIO0` is cleanly routed out to header `J7` pin 3 as an expansion LP I/O.
- [x] **Add Mass-Programming & Flashing Test Points to `B.Cu` (Bed-of-Nails Jig)**
  - **Status:** **Completed.** Added dedicated test points on `B.Cu`: `TP16` (`U0RXD`), `TP17` (`U0TXD`), `TP18` (`BTN1_NODE` / `GPIO28`), and `TP19` (`RESET_NODE` / `EN`), enabling automated single-sided bed-of-nails flashing.

---

## 3. Low Priority (DFM & Cleanup)

- [x] **Fix 52 Acute Angle Corners (< 90°) and Trace Reversals (Acid Traps)**
  - **Status:** **Completed.** Cleaned up acute trace junctions and hairpins across the board; verified against custom DRC rule (`track_angle >= 90deg`), passing with 0 violations.
  - **Issue:**
    - 52 acute 45° corners and 0° trace hairpins/reversals were previously identified across the board.
  - **Resolution:** Straightened trace geometries and verified clean DRC pass under the 90-degree track angle rule.

---

## 4. Firmware & Power Architecture Checklist (Battery Sleep Optimization)

- [x] **Float `GPIO9` and `GPIO10` Before Entering Deep Sleep (1.40 mA Leakage Fix)**
  - **Status:** **Completed.** Added `on_shutdown` hook in `firmware/example-device.yaml` turning off `user_rail` (`GPIO23`) and setting `GPIO9` / `GPIO10` to floating inputs (High-Z) with pad hold disabled via `gpio_set_direction`, `gpio_set_pull_mode(GPIO_FLOATING)`, and `gpio_hold_dis`.
  - **Issue:** When the `TPS22918` load switch turns off `3V3_USER`, its quick output discharge (QOD) pulls the rail to 0V. Pull-ups `R201` and `R202` (4.7k ohm) connect `SDA_USER` and `SCL_USER` to `3V3_USER`. If the ESP32 enters deep sleep with `GPIO9` or `GPIO10` driving HIGH or internal pull-ups enabled, up to 1.40 mA continuously leaks into ground through the QOD.
  - **Resolution:** Configured `GPIO9` and `GPIO10` as High-Z inputs with internal pull-ups/pull-downs and RTC pad hold disabled prior to cutting `EN_3V3_USER`.

- [x] **Clear BQ25798 and BQ34Z100 Interrupts Prior to Deep Sleep (660 uA Leakage Fix)**
  - **Status:** **Completed.** Implemented native `on_shutdown()` hooks and `clear_interrupts()` / `clear_alert()` methods in `esphome-bq-drivers` for both `BQ25798Component` (reading registers 0x22-0x27) and `BQ34Z100Component` (reading `CMD_FLAGS` 0x0E/0x0F), automatically releasing open-drain lines high on shutdown/deep sleep. Also exposed buttons and automation actions (`bq25798.clear_interrupts`, `bq34z100.clear_alert`).
  - **Issue:** `CHG_INT` and `FG_ALERT` have 10k ohm pull-up resistors (`R24`, `R401`) to `3V3_SYS`. If an uncleared fault, charge state change, or fuel gauge alert holds either open-drain line low during sleep, each asserted line continuously drains 330 uA (3.3V / 10k ohm).
  - **Resolution:** Implemented native interrupt and alert clearing directly in `esphome-bq-drivers` via component `on_shutdown()` lifecycle hooks, guaranteeing zero static draw on `R24` and `R401` during deep sleep.

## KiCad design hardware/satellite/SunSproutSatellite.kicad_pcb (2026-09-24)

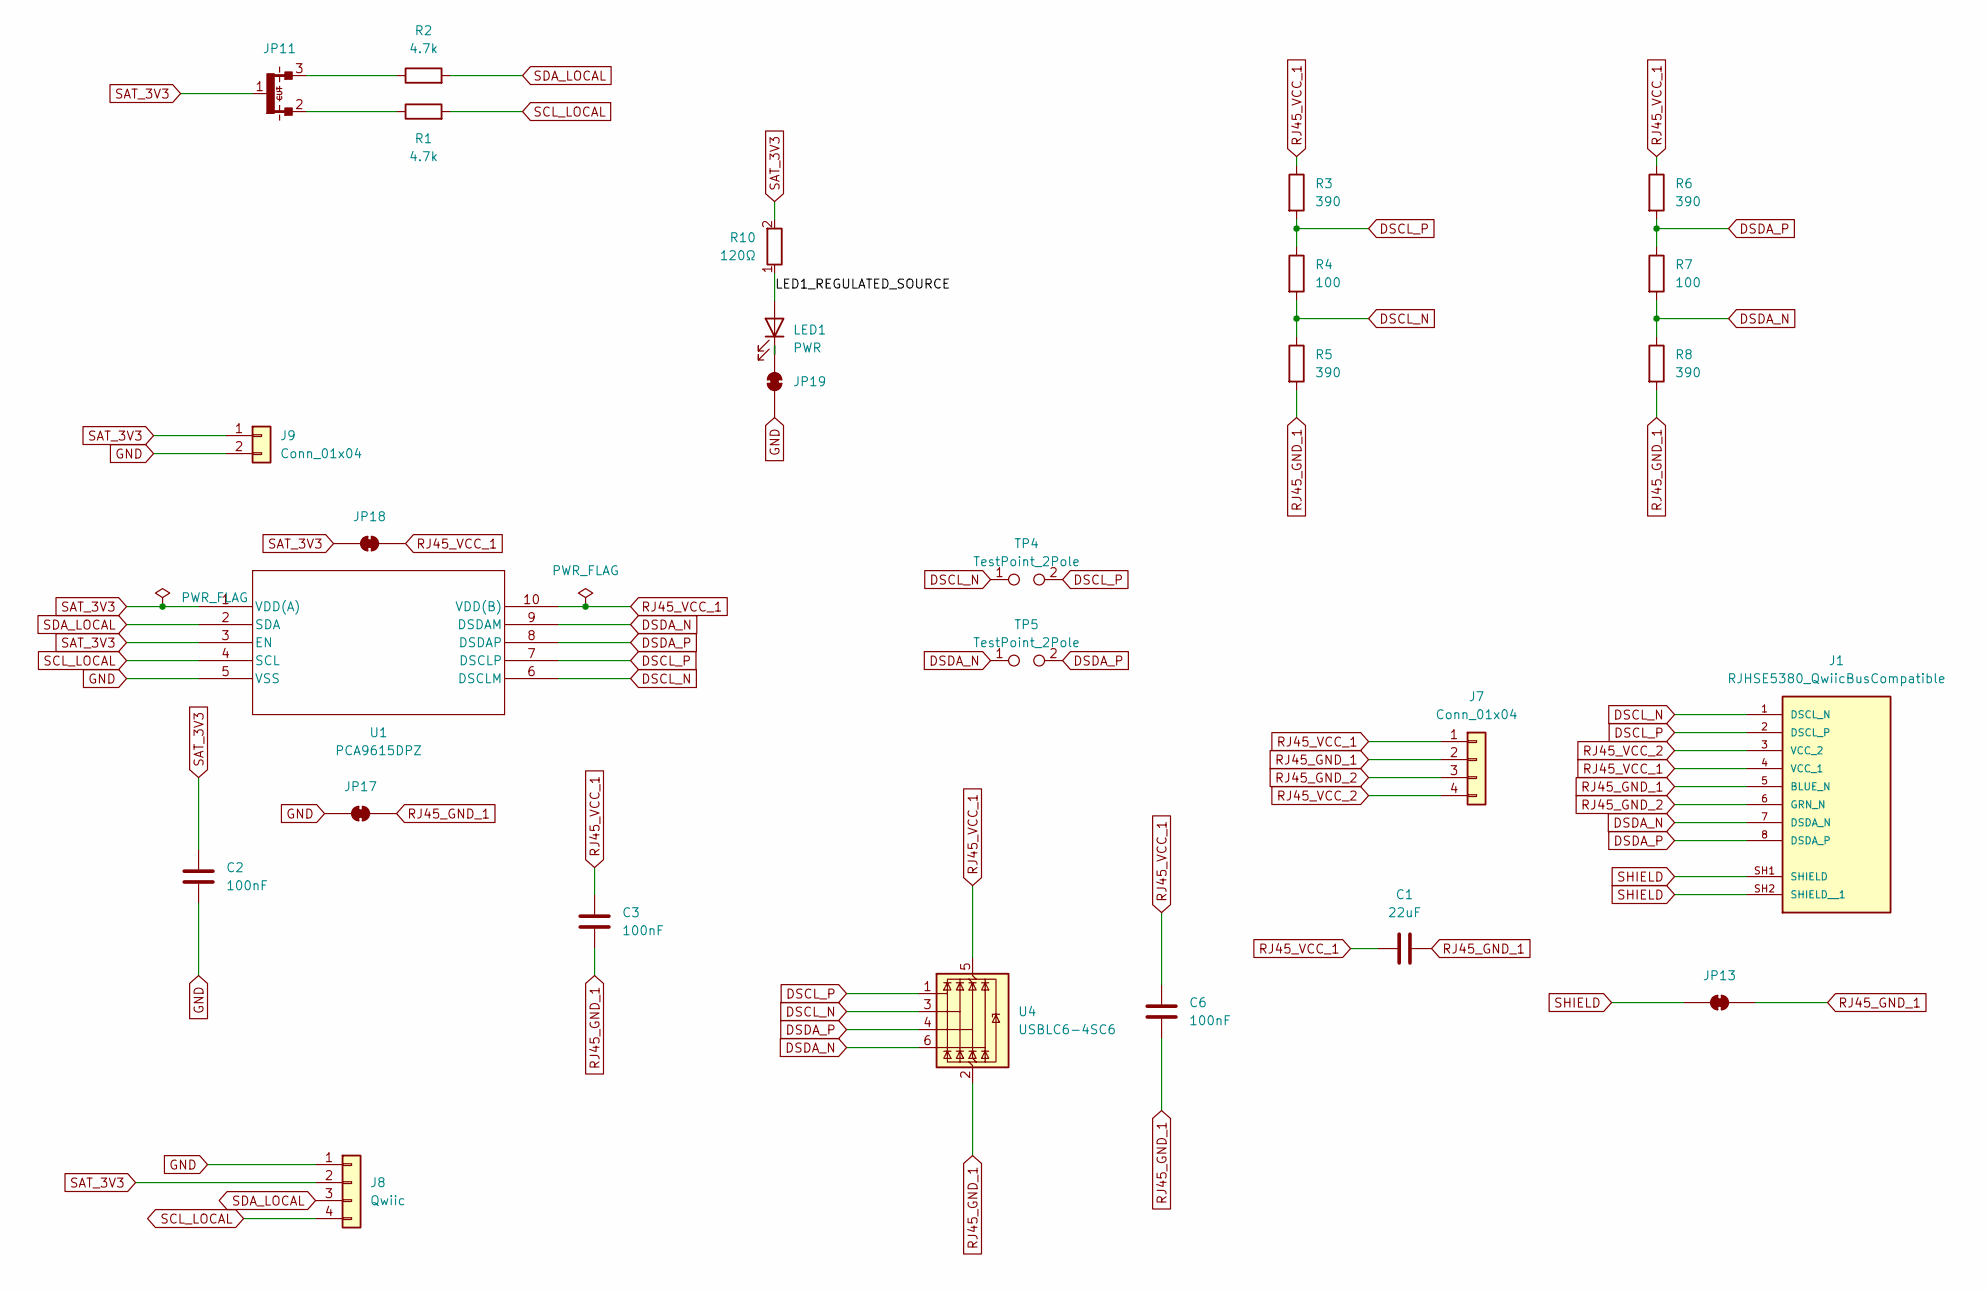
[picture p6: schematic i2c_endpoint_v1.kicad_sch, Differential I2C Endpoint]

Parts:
C1: 22uF; C_0805_2012Metric_Pad1.18x1.45mm_HandSolder; LCSC Part C45783
C2, C3, C6: 100nF; C_0805_2012Metric_Pad1.18x1.45mm_HandSolder; LCSC Part C28233
J1: RJHSE5380_QwiicBusCompatible; AMPHENOL_RJHSE5380; LCSC Part C464586
J7: Conn_01x04; PinHeader_1x04_P2.54mm_Vertical; LCSC Part C22368214
J8: Qwiic; JST_SH_BM04B-SRSS-TB_1x04-1MP_P1.00mm_Vertical; MPN BM04B-SRSS-TB(LF)(SN); LCSC Part C160390
J9: Conn_01x04; PinHeader_1x02_P2.54mm_Vertical; LCSC Part C22368214
JP11: SolderJumper_3_DualPullUp_Bridged; SolderJumper-3_P1.3mm_DualPullUp_SingleCut_RoundedPad1.0x1.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
JP13, JP17, JP18, JP19: SolderJumper_2_Bridged; SolderJumper-2_P1.3mm_Bridged_RoundedPad1.0x1.5mm
LED1: PWR; LED_0805_2012Metric_Pad1.15x1.40mm_HandSolder
R1, R2: 4.7k; R_0805_2012Metric_Pad1.20x1.40mm_HandSolder; LCSC Part C17673
R3, R5, R6, R8: 390; R_0805_2012Metric_Pad1.20x1.40mm_HandSolder; LCSC Part C17655
R4, R7: 100; R_0805_2012Metric_Pad1.20x1.40mm_HandSolder; LCSC Part C17408
R10: 120Ω; R_0805_2012Metric_Pad1.20x1.40mm_HandSolder
TP4, TP5: TestPoint_2Pole; TestPoint_2Pole_Pad_D1.0mm
U1: PCA9615DPZ; TSSOP10_SOT552-1_NXP-L; LCSC Part C3824272
U4: USBLC6-4SC6; SOT-23-6; LCSC Part C5180279

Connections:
/Differential I2C Endpoint/LED1_REGULATED_SOURCE: LED1.2 (A), R10.1
DSCL_N: J1.1 (DSCL_N), R4.2, R5.1, TP4.1, U1.6 (DSCLM), U4.3 (I/O2)
DSCL_P: J1.2 (DSCL_P), R3.2, R4.1, TP4.2, U1.7 (DSCLP), U4.1 (I/O1)
DSDA_N: J1.7 (DSDA_N), R7.2, R8.1, TP5.1, U1.9 (DSDAM), U4.6 (I/O4)
DSDA_P: J1.8 (DSDA_P), R6.2, R7.1, TP5.2, U1.8 (DSDAP), U4.4 (I/O3)
GND: C2.2, J8.1 (GND), J9.2, JP17.2 (B), JP19.2 (B), U1.5 (VSS); also elsewhere on the board
unnamed: JP11.2 (SCL_PU), R1.1
unnamed: JP11.3 (SDA_PU), R2.1
unnamed: JP19.1 (A), LED1.1 (K)
RJ45_GND_1: C1.2, C3.2, C6.2, J1.5 (BLUE_N), J7.2, JP13.2 (B), JP17.1 (A), R5.2, R8.2, U4.2 (GND)
RJ45_GND_2: J1.6 (GRN_N), J7.3
RJ45_VCC_1: C1.1, C3.1, C6.1, J1.4 (VCC_1), J7.1, JP18.1 (A), R3.1, R6.1, U1.10 (VDD(B)), U4.5 (VBUS)
RJ45_VCC_2: J1.3 (VCC_2), J7.4
SAT_3V3: C2.1, J8.2 (3v3), J9.1, JP11.1 (VCC), JP18.2 (B), R10.2, U1.1 (VDD(A)), U1.3 (EN); also elsewhere on the board
SCL_LOCAL: J8.4 (SCL), R1.2, U1.4 (SCL); also elsewhere on the board
SDA_LOCAL: J8.3 (SDA), R2.2, U1.2 (SDA); also elsewhere on the board
SHIELD: J1.SH1 (SHIELD), J1.SH2 (SHIELD__1), JP13.1 (A)

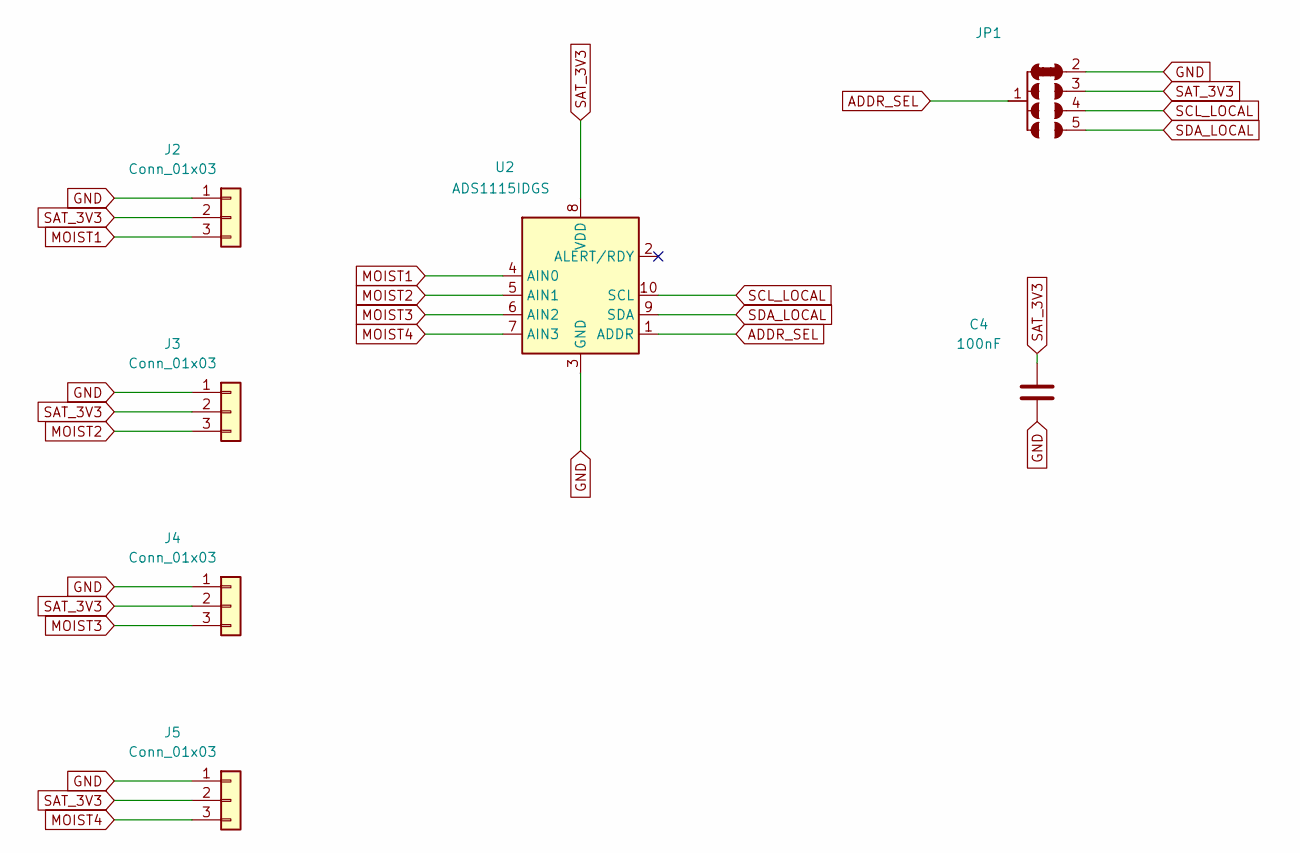
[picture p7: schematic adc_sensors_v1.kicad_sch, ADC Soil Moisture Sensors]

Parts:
C4: 100nF; C_0805_2012Metric_Pad1.18x1.45mm_HandSolder; LCSC Part C28233
J2, J3, J4, J5: Conn_01x03; JST_PH_B3B-PH-K_1x03_P2.00mm_Vertical; LCSC Part C131339
JP1: SolderJumper_4_Bridged12; ADCAddrJumper1mmPads
U2: ADS1115IDGS; TSSOP-10_3x3mm_P0.5mm; LCSC Part C37593

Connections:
ADDR_SEL: JP1.1 (ADDR), U2.1 (ADDR)
GND: C4.2, J2.1, J3.1, J4.1, J5.1, JP1.2 (0x48), U2.3 (GND); also elsewhere on the board
MOIST1: J2.3, U2.4 (AIN0)
MOIST2: J3.3, U2.5 (AIN1)
MOIST3: J4.3, U2.6 (AIN2)
MOIST4: J5.3, U2.7 (AIN3)
SAT_3V3: C4.1, J2.2, J3.2, J4.2, J5.2, JP1.3 (0x49), U2.8 (VDD); also elsewhere on the board
SCL_LOCAL: JP1.4 (0x4B), U2.10 (SCL); also elsewhere on the board
SDA_LOCAL: JP1.5 (0x4A), U2.9 (SDA); also elsewhere on the board

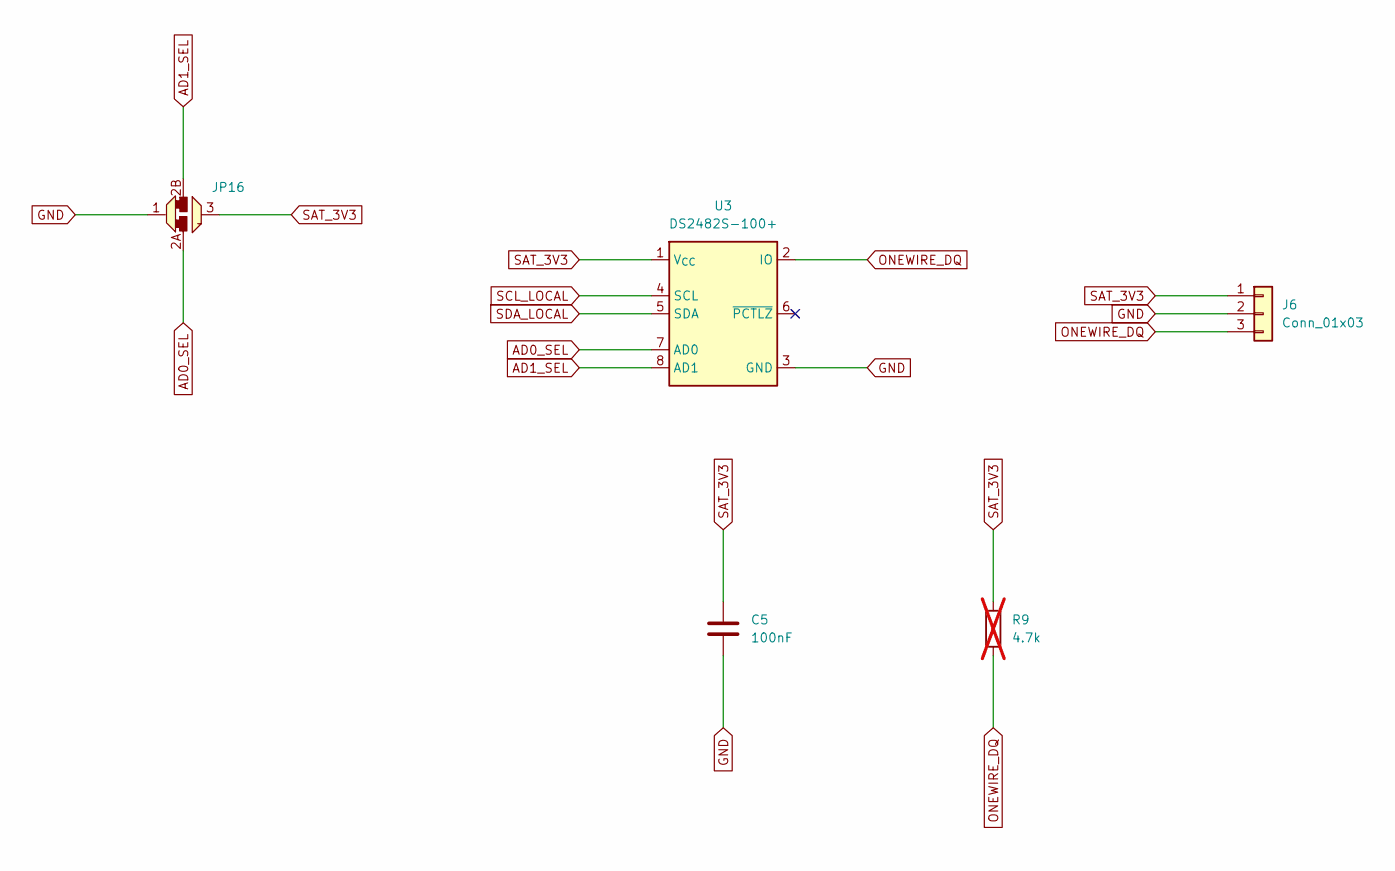
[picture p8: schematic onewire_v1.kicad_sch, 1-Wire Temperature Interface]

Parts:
C5: 100nF; C_0805_2012Metric_Pad1.18x1.45mm_HandSolder; LCSC Part C28233
J6: Conn_01x03; JST_PH_B3B-PH-K_1x03_P2.00mm_Vertical; LCSC Part C131339
JP16: Dual Solder Jumper with Both connected to Pin 1.; SolderJumper-3_P_1WAddr
R9: 4.7k; R_0805_2012Metric_Pad1.20x1.40mm_HandSolder; LCSC Part C23162; not fitted
U3: DS2482S-100+; SOIC-8_3.9x4.9mm_P1.27mm; LCSC Part C143306

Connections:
AD0_SEL: JP16.2A (C), U3.7 (AD0)
AD1_SEL: JP16.2B (C), U3.8 (AD1)
GND: C5.2, J6.2, JP16.1 (A), U3.3 (GND); also elsewhere on the board
ONEWIRE_DQ: J6.3, R9.2, U3.2 (IO)
SAT_3V3: C5.1, J6.1, JP16.3 (B), R9.1, U3.1 (V_{CC}); also elsewhere on the board
SCL_LOCAL: U3.4 (SCL); also elsewhere on the board
SDA_LOCAL: U3.5 (SDA); also elsewhere on the board

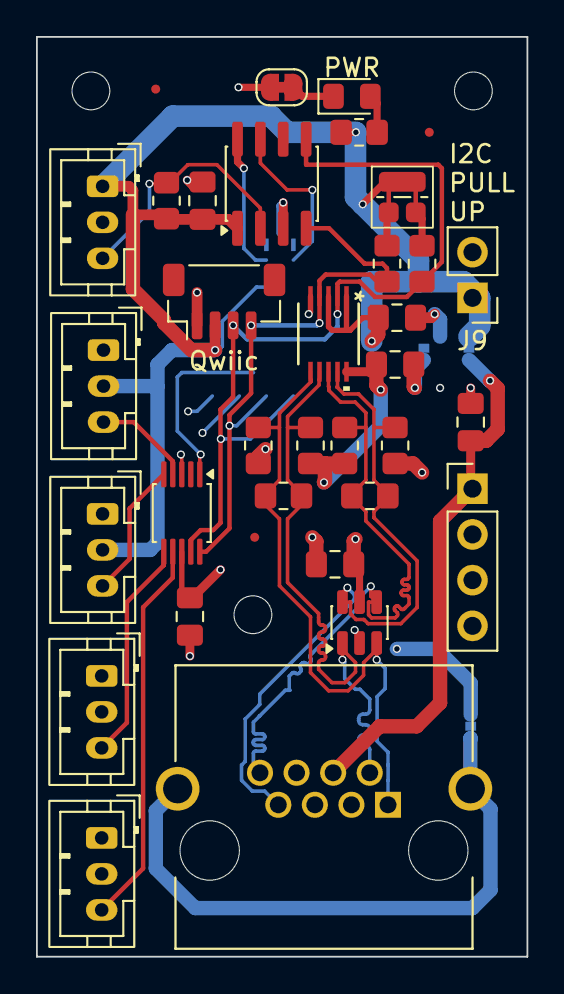
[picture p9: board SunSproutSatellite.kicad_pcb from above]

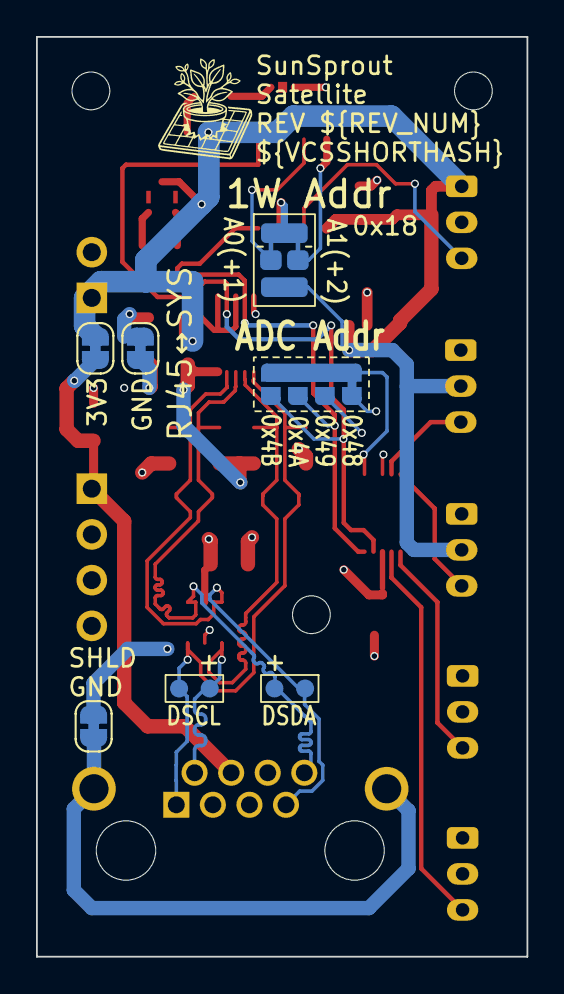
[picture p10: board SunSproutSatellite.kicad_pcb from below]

Board: 4 copper layers, 27.2 x 51.1 mm, 45 parts (7 on the bottom side), 25 nets.

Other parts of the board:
MP1, MP2, MP3: MountingHole_2.1mm
Ref**: Fiducial_0.5mm_Mask1mm
Ref**#2, Ref**#3: Fiducial_0.5mm_Mask1mm

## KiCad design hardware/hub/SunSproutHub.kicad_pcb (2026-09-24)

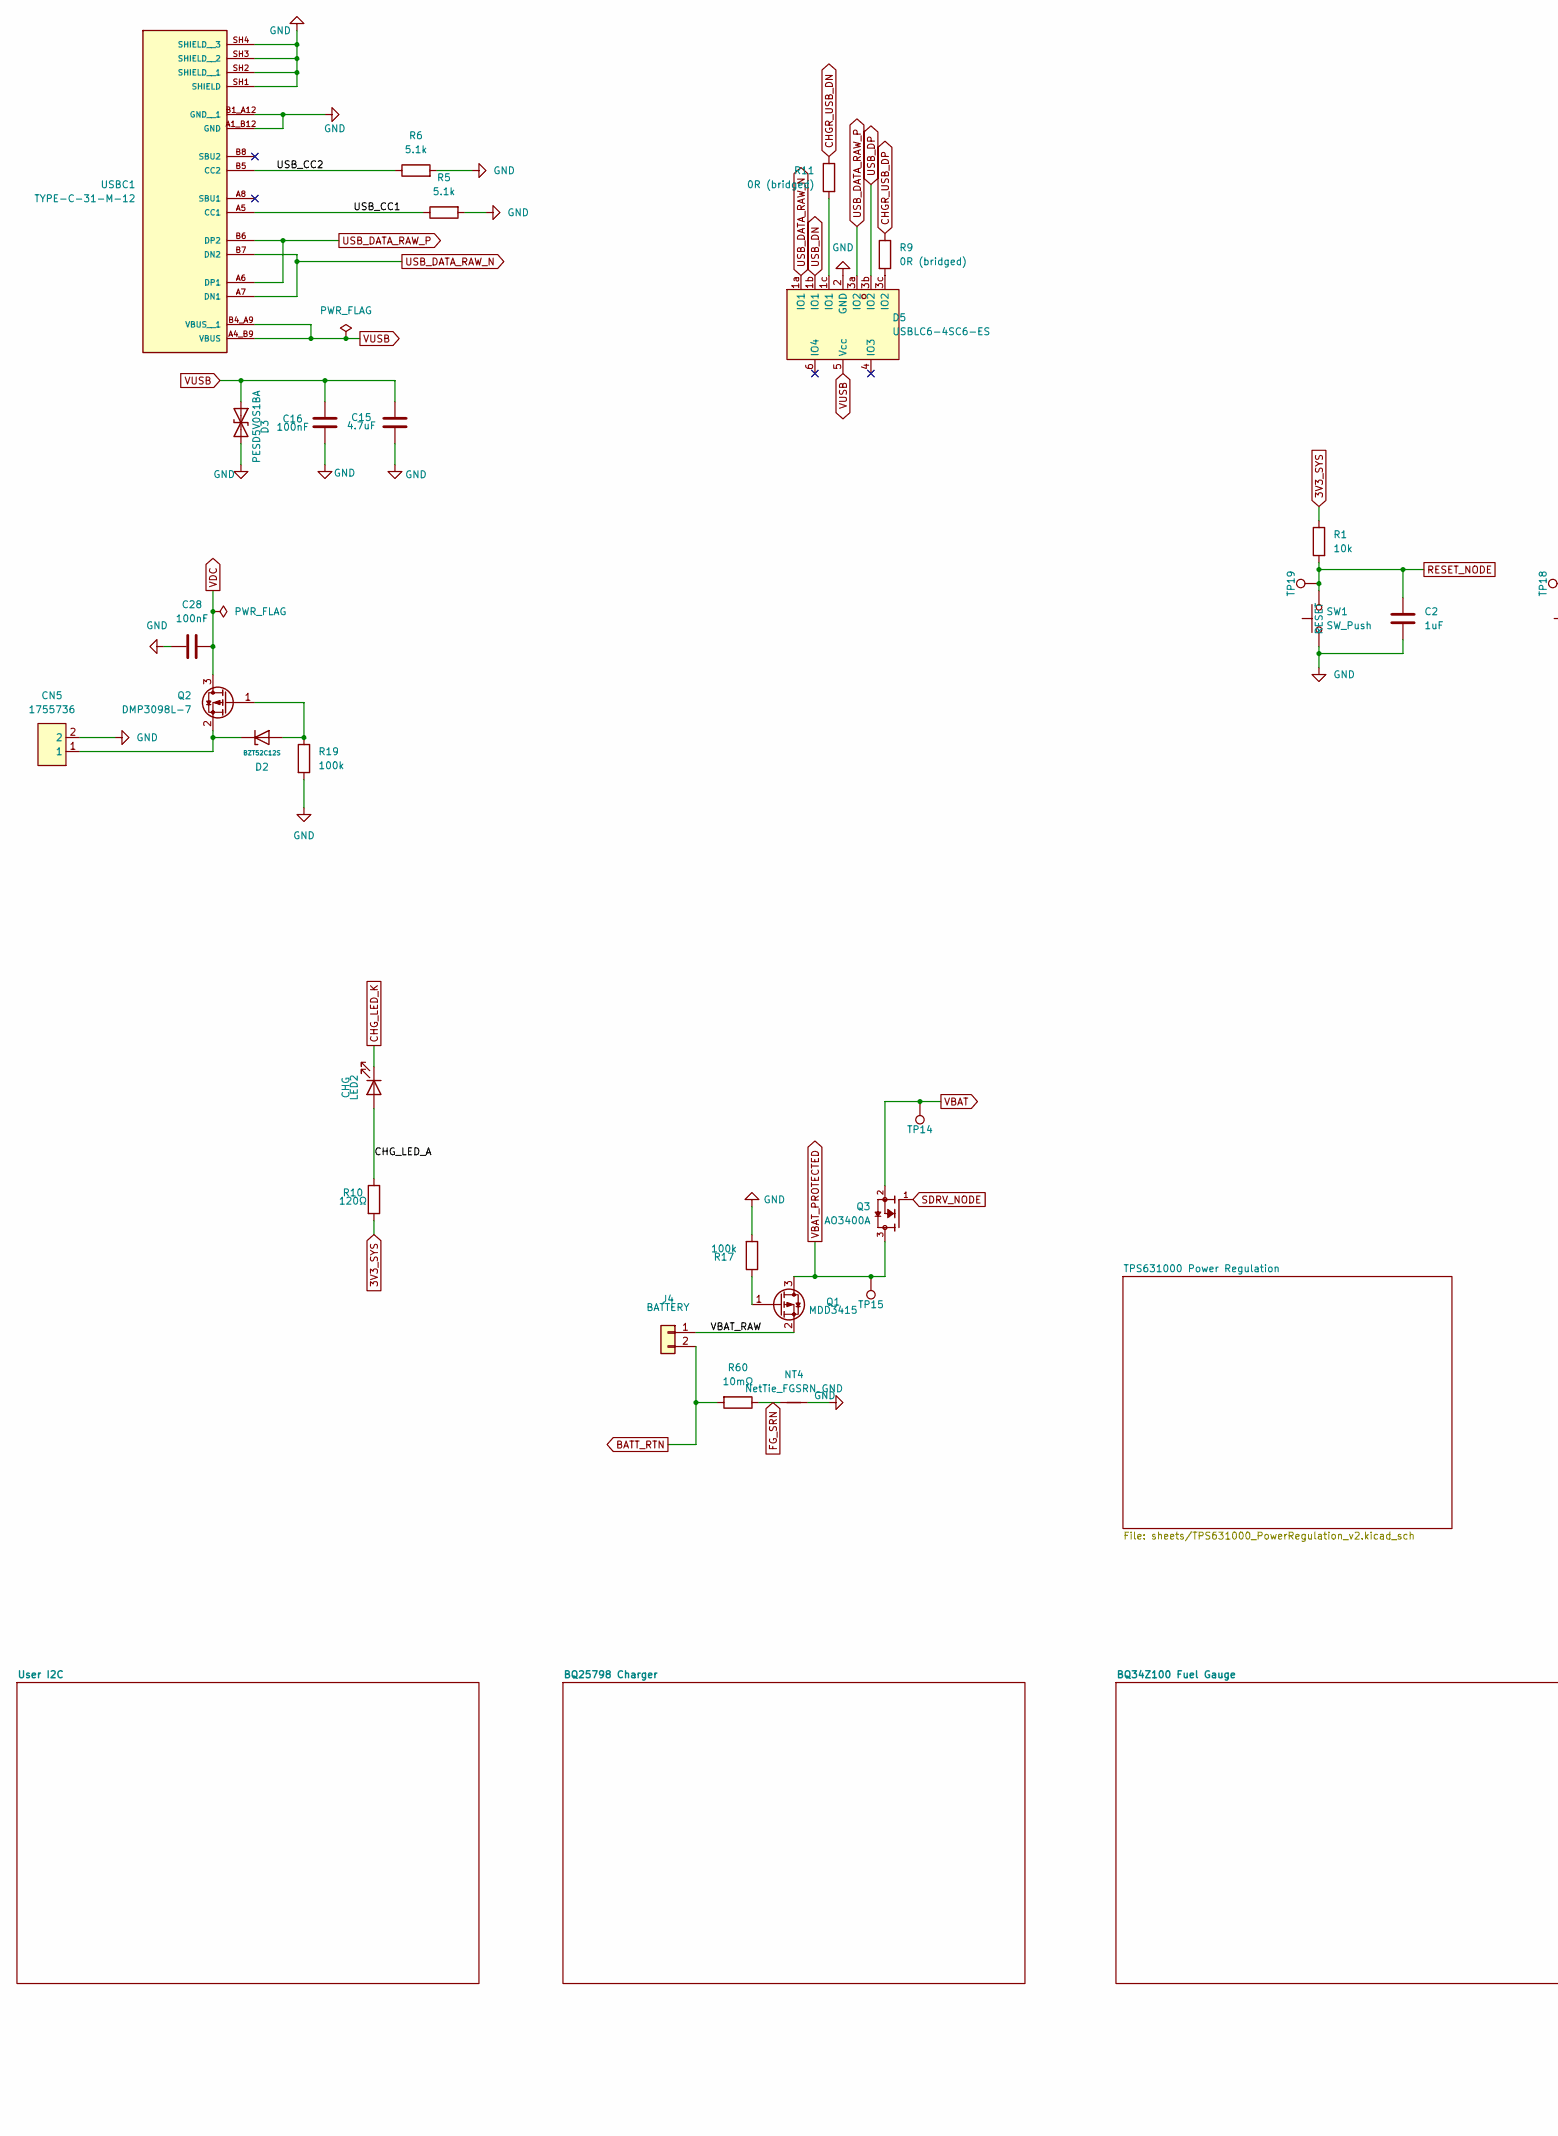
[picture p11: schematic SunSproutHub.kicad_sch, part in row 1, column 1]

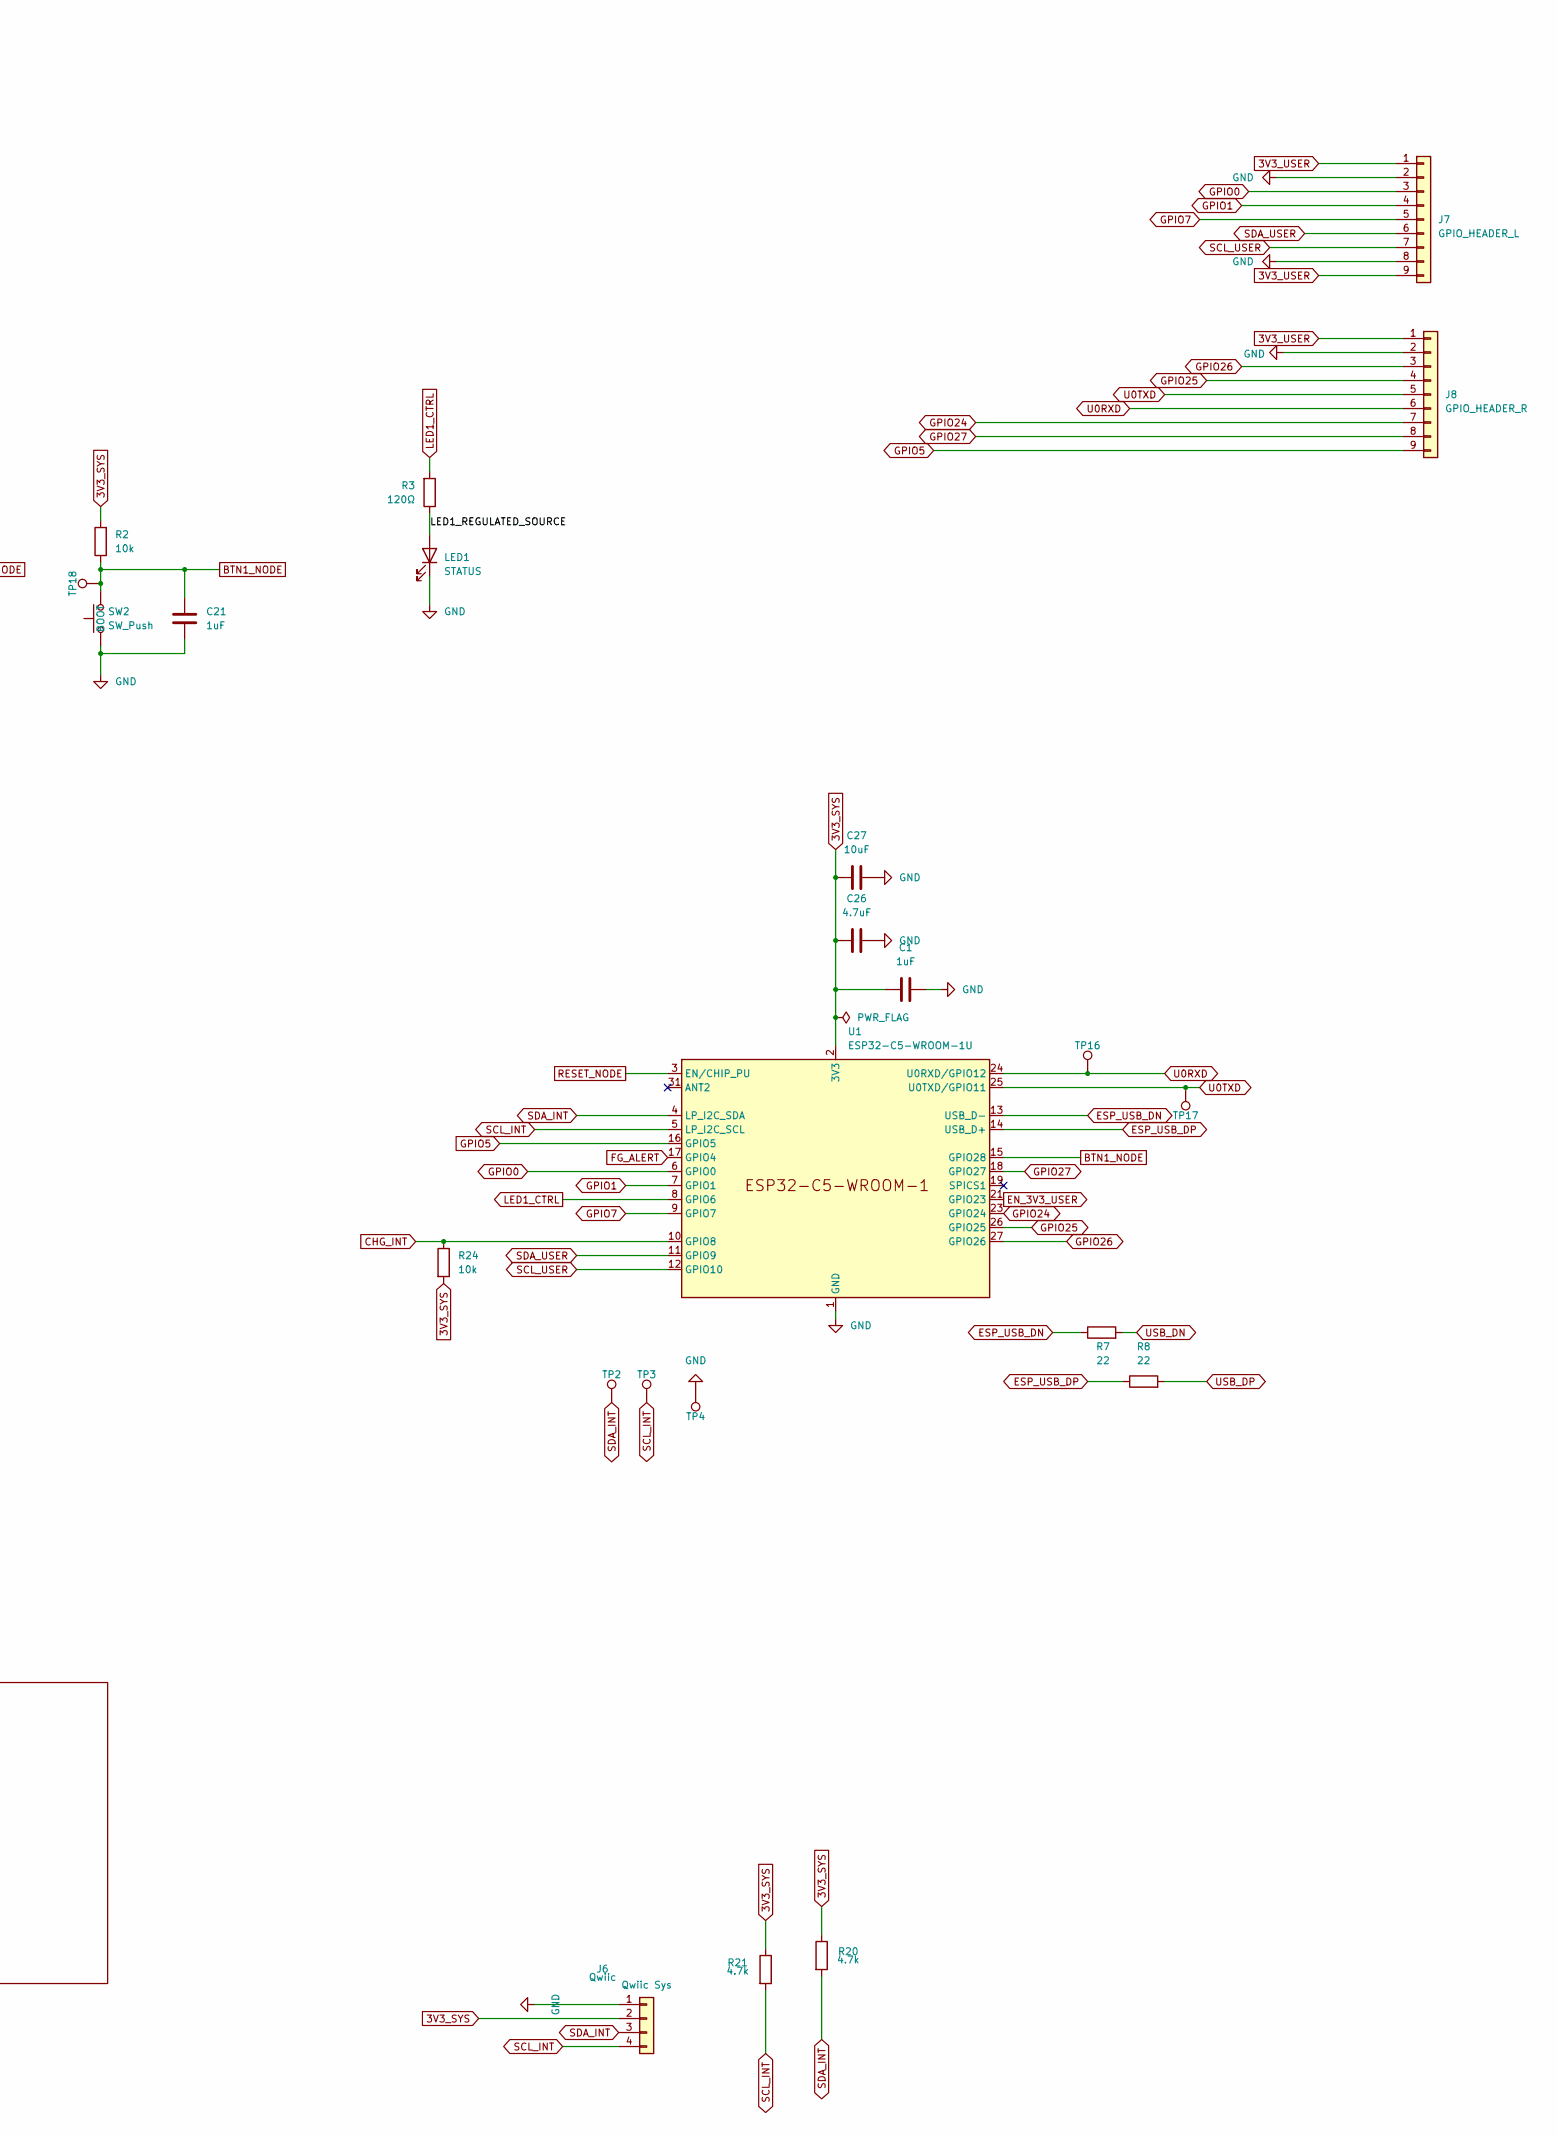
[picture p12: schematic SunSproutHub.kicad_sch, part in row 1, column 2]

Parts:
C1, C2, C21: 1uF; C_0603_1608Metric; MPN CL10A105KB8NNNC; LCSC Part C15849
C15, C26: 4.7uF; C_0805_2012Metric; MPN CL21A475KAQNNNE; LCSC Part C1779
C16: 100nF; C_0402; MPN CL05B104KB54PNC; LCSC Part C307331
C27: 10uF; C_0603_1608Metric; MPN CL10A106MA8NRNC; LCSC Part C96446
C28: 100nF; C_0402; LCSC Part C307331
CN5: 1755736; DB125-2.54-2P-GN-S; MPN DB125-2.54-2P-GN-S; LCSC Part C918120
D2: BZT52C12S; D_SOD-323; MPN BZT52C12S; LCSC Part C19077447
D3: PESD5V0S1BA; D_SOD-523; LCSC Part C20615818
D5: USBLC6-4SC6-ES; USBLC6-4SC6-ES_WIthNetTie; MPN USBLC6-4SC6-ES; LCSC Part C5180279
J4: BATTERY; JST_PH_S2B-PH-K_1x02_P2.00mm_Horizontal; MPN S2B-PH-K(LF)(SN); LCSC Part C265016
J6: Qwiic; JST_SH_BM04B-SRSS-TB_1x04-1MP_P1.00mm_Vertical; MPN BM04B-SRSS-TB(LF)(SN); LCSC Part C160390
J7: GPIO_HEADER_L; LeftSide_PinHeader_1x09_P2.54mm_Vertical
J8: GPIO_HEADER_R; PinHeader_1x09_P2.54mm_Vertical
LED1: STATUS; LED_0603_1608Metric; MPN KT-0603W; LCSC Part C2290
LED2: CHG; LED_0603_1608Metric; MPN KT-0603R; LCSC Part C2286
NT4: NetTie_FGSRN_GND; NetTie-2_SMD_Pad0.8mm_ParallelVias0.3mm
Q1: MDD3415; SOT-23; MPN MDD3415; LCSC Part C840839
Q2: DMP3098L-7; SOT-23; MPN DMP3098L-7; LCSC Part C150492
Q3: AO3400A; SOT95P280X125-3N; MPN AO3400A; LCSC Part C20917
R1, R2, R24: 10k; R_0603_1608Metric; MPN 0603WAF1002T5E; LCSC Part C25804
R3, R10: 120Ω; R_0603_1608Metric; MPN 0603WAF1200T5E; LCSC Part C22787
R5, R6: 5.1k; R_0603_1608Metric; MPN 0603WAF5101T5E; LCSC Part C23186
R7, R8: 22; R_0603_1608Metric; MPN 0603WAF220JT5E; LCSC Part C23345
R9, R11: 0R (bridged); R_0603_1608Metric_CuttableBridge
R17, R19: 100k; R_0603_1608Metric; MPN 0603WAF1003T5E; LCSC Part C25803
R20, R21: 4.7k; R_0603_1608Metric; MPN 0603WAF4701T5E; LCSC Part C23162
R60: 10mΩ; R_1206_3216Metric; LCSC Part C105362
SW1, SW2: SW_Push; SW_SPST_TS-1088-xR020; MPN TS-1088-AR02016; LCSC Part C720477
TP2: SDA_INT; TestPoint-1.0mm
TP3: SCL_INT; TestPoint-1.0mm
TP4: GND; TestPoint-1.0mm
TP14: VBAT; TestPoint-1.0mm
TP15: VBAT_PRO; TestPoint-1.0mm
TP16: U0RXD; TestPoint-1.0mm
TP17: U0TXD; TestPoint-1.0mm
TP18: BOOT; TestPoint-1.0mm
TP19: RESET; TestPoint-1.0mm
U1: ESP32-C5-WROOM-1U; MPN ESP32-C5-WROOM-1U-N8R8-V1.2; LCSC Part C54951858
USBC1: TYPE-C-31-M-12; USB-C_TYPE-C-31-M-12; MPN TYPE-C-31-M-12; LCSC Part C165948

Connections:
3V3_SYS: C1.1, C26.1, C27.1, J6.2 (3v3), R1.1, R2.2, R10.2, R20.1, R21.1, R24.2, U1.2 (3V3); also elsewhere on the board
3V3_USER: J7.1, J7.9, J8.1; also elsewhere on the board
/CHG_LED_A: LED2.2 (A), R10.1
/LED1_REGULATED_SOURCE: LED1.2 (A), R3.1
/USB_CC1: R5.1, USBC1.A5 (CC1)
/USB_CC2: R6.1, USBC1.B5 (CC2)
/VBAT_RAW: J4.1, Q1.2 (S)
BATT_RTN: J4.2, R60.2; also elsewhere on the board
BTN1_NODE: C21.1, R2.1, SW2.1, TP18.1 (1_1), U1.15 (GPIO28)
CHGR_USB_DN: R11.1; also elsewhere on the board
CHGR_USB_DP: R9.1; also elsewhere on the board
CHG_INT: R24.1, U1.10 (GPIO8); also elsewhere on the board
CHG_LED_K: LED2.1 (K); also elsewhere on the board
EN_3V3_USER: U1.21 (GPIO23); also elsewhere on the board
ESP_USB_DN: R7.1, U1.13 (USB_D-)
ESP_USB_DP: R8.1, U1.14 (USB_D+)
FG_ALERT: U1.17 (GPIO4); also elsewhere on the board
FG_SRN: NT4.2, R60.1; also elsewhere on the board
GND: C1.2, C2.2, C15.2, C16.2, C21.2, C26.2, C27.2, C28.2, CN5.2, D3.2 (A2), D5.2 (GND), J6.1 (GND), J7.2, J7.8, J8.2, LED1.1 (K), NT4.1, R5.2, R6.2, R17.2, R19.2, SW1.2, SW2.2, TP4.1 (1_1), U1.1 (GND), U1.28 (GND), U1.29 (GND), U1.30 (GND), U1.32 (GND), USBC1.A1_B12 (GND), USBC1.B1_A12 (GND__1), USBC1.SH1 (SHIELD), USBC1.SH2 (SHIELD__1), USBC1.SH3 (SHIELD__2), USBC1.SH4 (SHIELD__3); also elsewhere on the board
GPIO0: J7.3, U1.6 (GPIO0)
GPIO1: J7.4, U1.7 (GPIO1)
GPIO5: J8.9, U1.16 (GPIO5)
GPIO7: J7.5, U1.9 (GPIO7)
GPIO24: J8.7, U1.23 (GPIO24)
GPIO25: J8.4, U1.26 (GPIO25)
GPIO26: J8.3, U1.27 (GPIO26)
GPIO27: J8.8, U1.18 (GPIO27)
LED1_CTRL: R3.2, U1.8 (GPIO6)
unnamed: D5.1c (IO1), R11.2
unnamed: D5.3c (IO2), R9.2
unnamed: Q1.1 (G), R17.1
unnamed: D2.2, Q2.1 (G), R19.1
unnamed: CN5.1, D2.1, Q2.2 (S)
RESET_NODE: C2.1, R1.2, SW1.1, TP19.1 (1_1), U1.3 (EN/CHIP_PU)
SCL_INT: J6.4 (SCL), R21.2, TP3.1 (1_1), U1.5 (LP_I2C_SCL); also elsewhere on the board
SCL_USER: J7.7, U1.12 (GPIO10); also elsewhere on the board
SDA_INT: J6.3 (SDA), R20.2, TP2.1 (1_1), U1.4 (LP_I2C_SDA); also elsewhere on the board
SDA_USER: J7.6, U1.11 (GPIO9); also elsewhere on the board
SDRV_NODE: Q3.1; also elsewhere on the board
U0RXD: J8.6, TP16.1 (1_1), U1.24 (U0RXD/GPIO12)
U0TXD: J8.5, TP17.1 (1_1), U1.25 (U0TXD/GPIO11)
USB_DATA_RAW_N: D5.1a (IO1), USBC1.A7 (DN1), USBC1.B7 (DN2)
USB_DATA_RAW_P: D5.3a (IO2), USBC1.A6 (DP1), USBC1.B6 (DP2)
USB_DN: D5.1b (IO1), R7.2
USB_DP: D5.3b (IO2), R8.2
VBAT: Q3.2, TP14.1 (1_1); also elsewhere on the board
VBAT_PROTECTED: Q1.3 (D), Q3.3, TP15.1 (1_1); also elsewhere on the board
VDC: C28.1, Q2.3 (D); also elsewhere on the board
VUSB: C15.1, C16.1, D3.1 (A1), D5.5 (Vcc), USBC1.A4_B9 (VBUS), USBC1.B4_A9 (VBUS__1); also elsewhere on the board

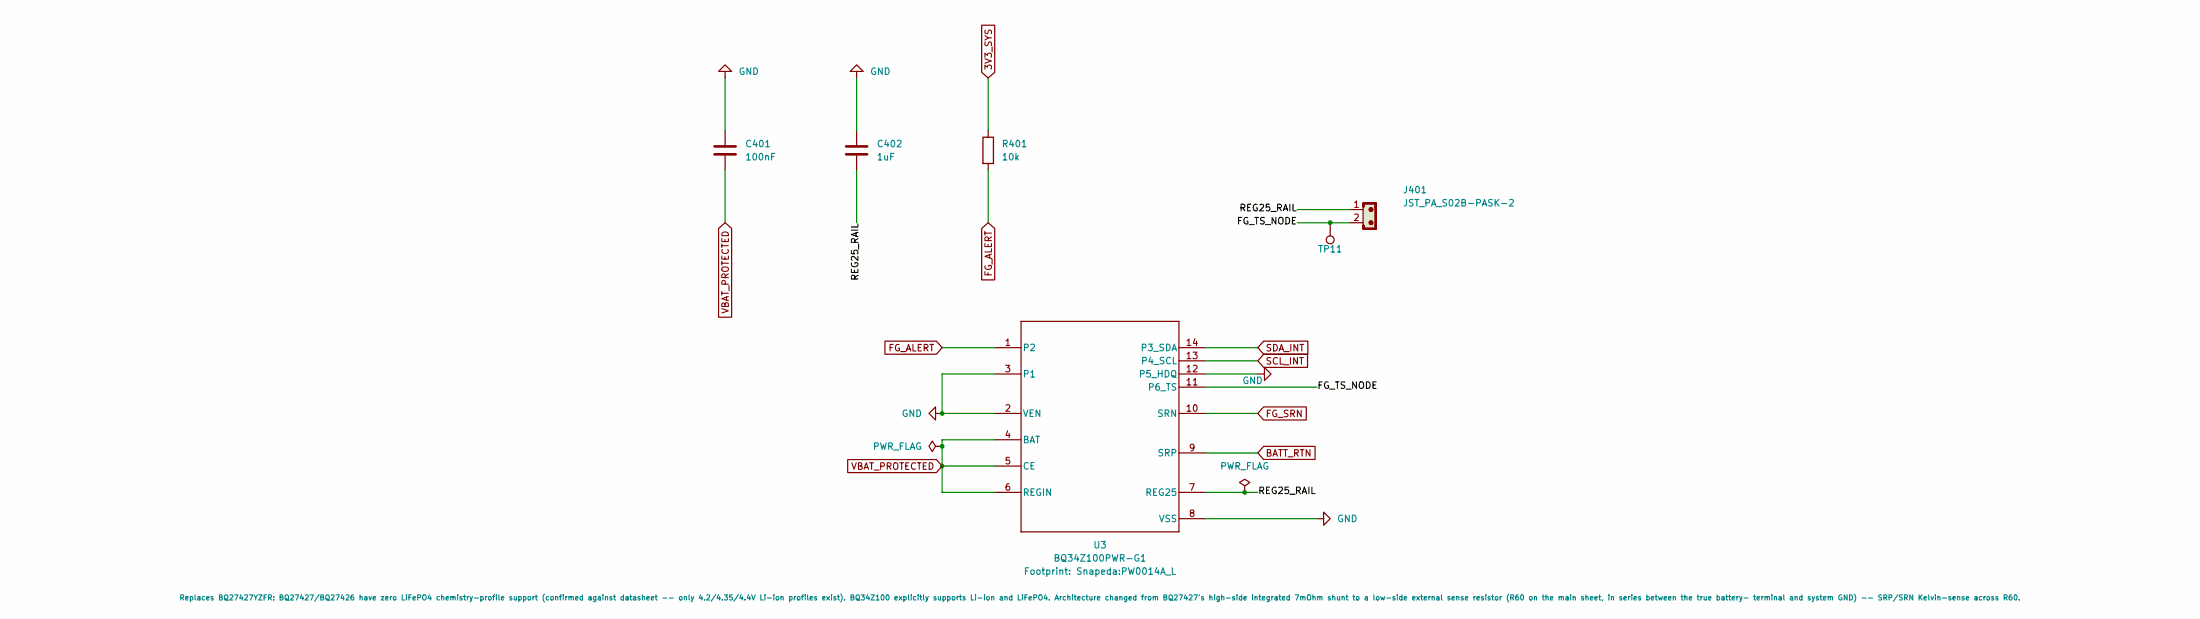
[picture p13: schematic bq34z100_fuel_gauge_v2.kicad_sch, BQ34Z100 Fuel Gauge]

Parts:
C401: 100nF; C_0402; MPN CL05B104KB54PNC; LCSC Part C307331
C402: 1uF; C_0603_1608Metric; MPN CL10A105KB8NNNC; LCSC Part C15849
J401: JST_PA_S02B-PASK-2; JST_PA_S02B-PASK-2_1x02_P2.00mm_Horizontal; MPN S02B-PASK-2(LF)(SN); LCSC Part C265094
R401: 10k; R_0603_1608Metric; MPN 0603WAF1002T5E; LCSC Part C25804
TP11: FG_TS_NODE; TestPoint-1.0mm
U3: BQ34Z100PWR-G1; PW0014A_L; MPN BQ34Z100PWR-G1; LCSC Part C91302

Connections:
3V3_SYS: R401.1; also elsewhere on the board
/BQ34Z100 Fuel Gauge/FG_TS_NODE: J401.2, TP11.1 (1_1), U3.11 (P6_TS)
/BQ34Z100 Fuel Gauge/REG25_RAIL: C402.2, J401.1, U3.7 (REG25)
BATT_RTN: U3.9 (SRP); also elsewhere on the board
FG_ALERT: R401.2, U3.1 (P2); also elsewhere on the board
FG_SRN: U3.10 (SRN); also elsewhere on the board
GND: C401.1, C402.1, U3.2 (VEN), U3.3 (P1), U3.8 (VSS), U3.12 (P5_HDQ); also elsewhere on the board
SCL_INT: U3.13 (P4_SCL); also elsewhere on the board
SDA_INT: U3.14 (P3_SDA); also elsewhere on the board
VBAT_PROTECTED: C401.2, U3.4 (BAT), U3.5 (CE), U3.6 (REGIN); also elsewhere on the board

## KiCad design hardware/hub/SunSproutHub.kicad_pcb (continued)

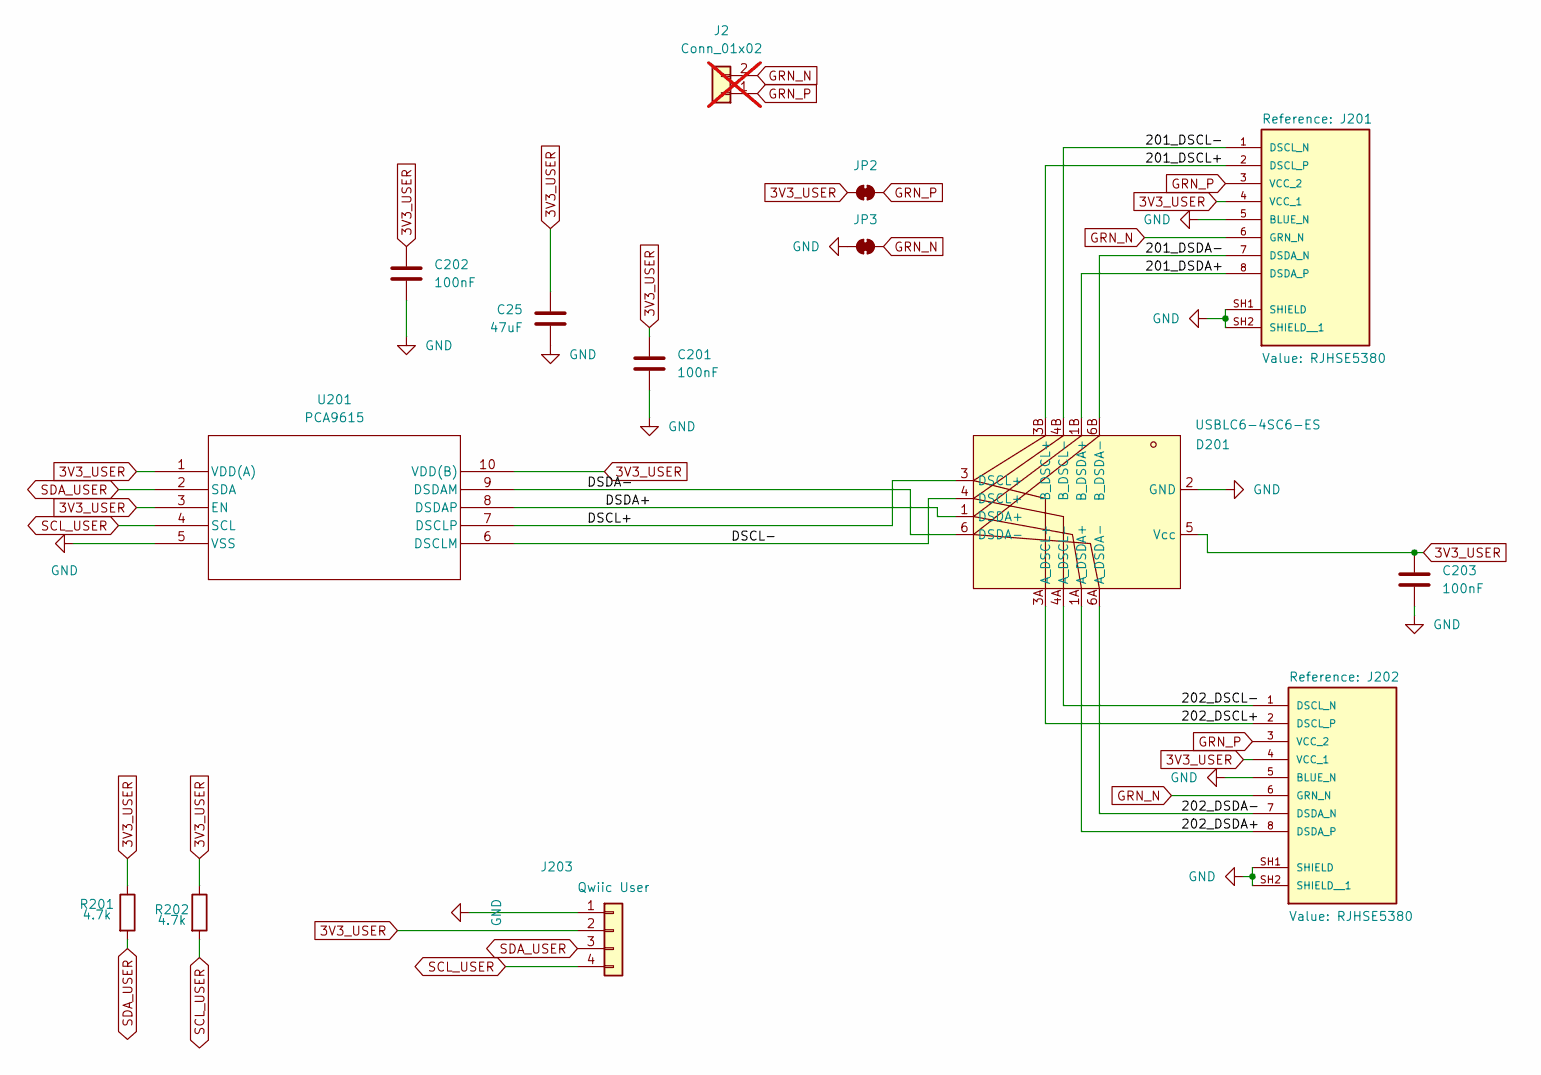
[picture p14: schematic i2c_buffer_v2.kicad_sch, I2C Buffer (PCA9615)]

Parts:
C25: 47uF; C_0805_2012Metric; LCSC Part C16780
C201, C202: 100nF; C_0402; MPN CL05B104KB54PNC; LCSC Part C307331
C203: 100nF; C_0402; LCSC Part C307331
D201: USBLC6-4SC6-ES; SOT23-6L_STM_w_NetTies_1346ab; MPN USBLC6-4SC6-ES; LCSC Part C5180279
J2: Conn_01x02; PinHeader_1x02_P2.54mm_Vertical; not fitted
J201, J202: RJHSE5380; AMPHENOL_RJHSE5380; MPN RJHSE5380; LCSC Part C464586
J203: Qwiic; JST_SH_BM04B-SRSS-TB_1x04-1MP_P1.00mm_Vertical; MPN BM04B-SRSS-TB(LF)(SN); LCSC Part C160390
JP2, JP3: SolderJumper-2_P1.3mm_Bridged_RoundedPad1.0x1.5mm
R201, R202: 4.7k; R_0603_1608Metric; MPN 0603WAF4701T5E; LCSC Part C23162
U201: PCA9615; TSSOP10_SOT552-1_NXP-L; MPN PCA9615DPZ; LCSC Part C3824272

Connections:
3V3_USER: C25.1, C201.1, C202.1, C203.1, D201.5 (Vcc), J201.4 (VCC_1), J202.4 (VCC_1), J203.2 (3v3), JP2.1 (A), R201.1, R202.1, U201.1 (VDD(A)), U201.3 (EN), U201.10 (VDD(B)); also elsewhere on the board
/User I2C/201_DSCL+: D201.3B (B_DSCL+), J201.2 (DSCL_P)
/User I2C/201_DSCL-: D201.4B (B_DSCL-), J201.1 (DSCL_N)
/User I2C/201_DSDA+: D201.1B (B_DSDA+), J201.8 (DSDA_P)
/User I2C/201_DSDA-: D201.6B (B_DSDA-), J201.7 (DSDA_N)
/User I2C/202_DSCL+: D201.3A (A_DSCL+), J202.2 (DSCL_P)
/User I2C/202_DSCL-: D201.4A (A_DSCL-), J202.1 (DSCL_N)
/User I2C/202_DSDA+: D201.1A (A_DSDA+), J202.8 (DSDA_P)
/User I2C/202_DSDA-: D201.6A (A_DSDA-), J202.7 (DSDA_N)
/User I2C/DSCL+: D201.3 (DSCL+), U201.7 (DSCLP)
/User I2C/DSCL-: D201.4 (DSCL+), U201.6 (DSCLM)
/User I2C/DSDA+: D201.1 (DSDA+), U201.8 (DSDAP)
/User I2C/DSDA-: D201.6 (DSDA-), U201.9 (DSDAM)
GND: C25.2, C201.2, C202.2, C203.2, D201.2 (GND), J201.5 (BLUE_N), J201.SH1 (SHIELD), J201.SH2 (SHIELD__1), J202.5 (BLUE_N), J202.SH1 (SHIELD), J202.SH2 (SHIELD__1), J203.1 (GND), JP3.1 (A), U201.5 (VSS); also elsewhere on the board
GRN_N: J2.2, J201.6 (GRN_N), J202.6 (GRN_N), JP3.2 (B)
GRN_P: J2.1, J201.3 (VCC_2), J202.3 (VCC_2), JP2.2 (B)
SCL_USER: J203.4 (SCL), R202.2, U201.4 (SCL); also elsewhere on the board
SDA_USER: J203.3 (SDA), R201.2, U201.2 (SDA); also elsewhere on the board

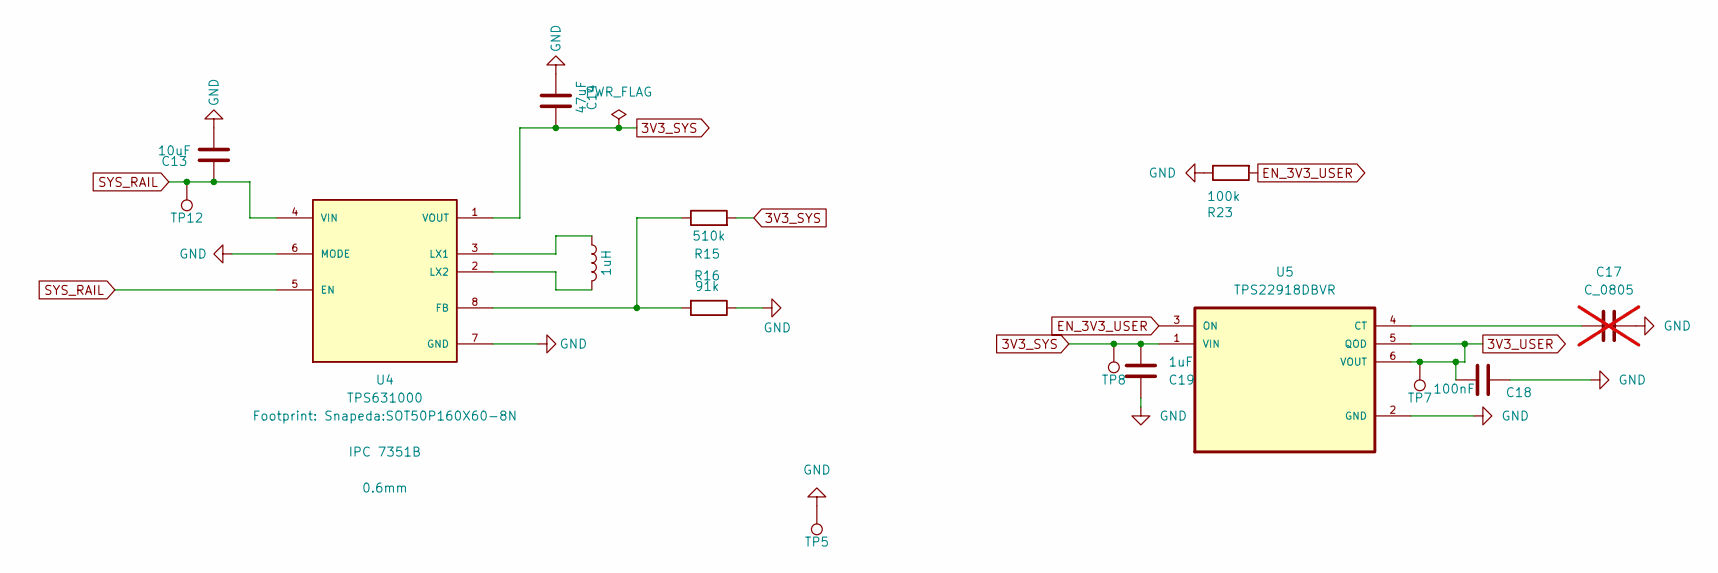
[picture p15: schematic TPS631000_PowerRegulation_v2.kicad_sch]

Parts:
C13: 10uF; C_0603_1608Metric; MPN CL10A106MA8NRNC; LCSC Part C96446
C14: 47uF; C_0805_2012Metric; LCSC Part C16780
C17: C_0805; C_0805_2012Metric; not fitted
C18: 100nF; C_0402; LCSC Part C307331
C19: 1uF; C_0603_1608Metric; MPN CL10A105KB8NNNC; LCSC Part C15849
L2: 1uH; L_Changjiang_FTC252012S; MPN FTC252012S1R0MBCD; LCSC Part C22400405
R15: 510k; R_0603_1608Metric; LCSC Part C23192
R16: 91k; R_0603_1608Metric; LCSC Part C23265
R23: 100k; R_0603_1608Metric; MPN 0603WAF1003T5E; LCSC Part C25803
TP5: GND; TestPoint-1.0mm
TP7: 3V3_USER; TestPoint-1.0mm
TP8: 3V3_SYS; TestPoint-1.0mm
TP12: SYS_RAIL; TestPoint-1.0mm
U4: TPS631000; SOT50P160X60-8N; MPN TPS631000DRLR; LCSC Part C5219190
U5: TPS22918DBVR; SOT95P280X145-6N; MPN TPS22918DBVR; LCSC Part C131941

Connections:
3V3_SYS: C14.1, C19.1, R15.2, TP8.1 (1_1), U4.1 (VOUT), U5.1 (VIN); also elsewhere on the board
3V3_USER: C18.2, TP7.1 (1_1), U5.5 (QOD), U5.6 (VOUT); also elsewhere on the board
EN_3V3_USER: R23.2, U5.3 (ON); also elsewhere on the board
GND: C13.2, C14.2, C17.2, C18.1, C19.2, R16.1, R23.1, TP5.1 (1_1), U4.6 (MODE), U4.7 (GND), U5.2 (GND); also elsewhere on the board
unnamed: R15.1, R16.2, U4.8 (FB)
unnamed: L2.2, U4.3 (LX1)
unnamed: L2.1, U4.2 (LX2)
unnamed: C17.1, U5.4 (CT)
SYS_RAIL: C13.1, TP12.1 (1_1), U4.4 (VIN), U4.5 (EN); also elsewhere on the board

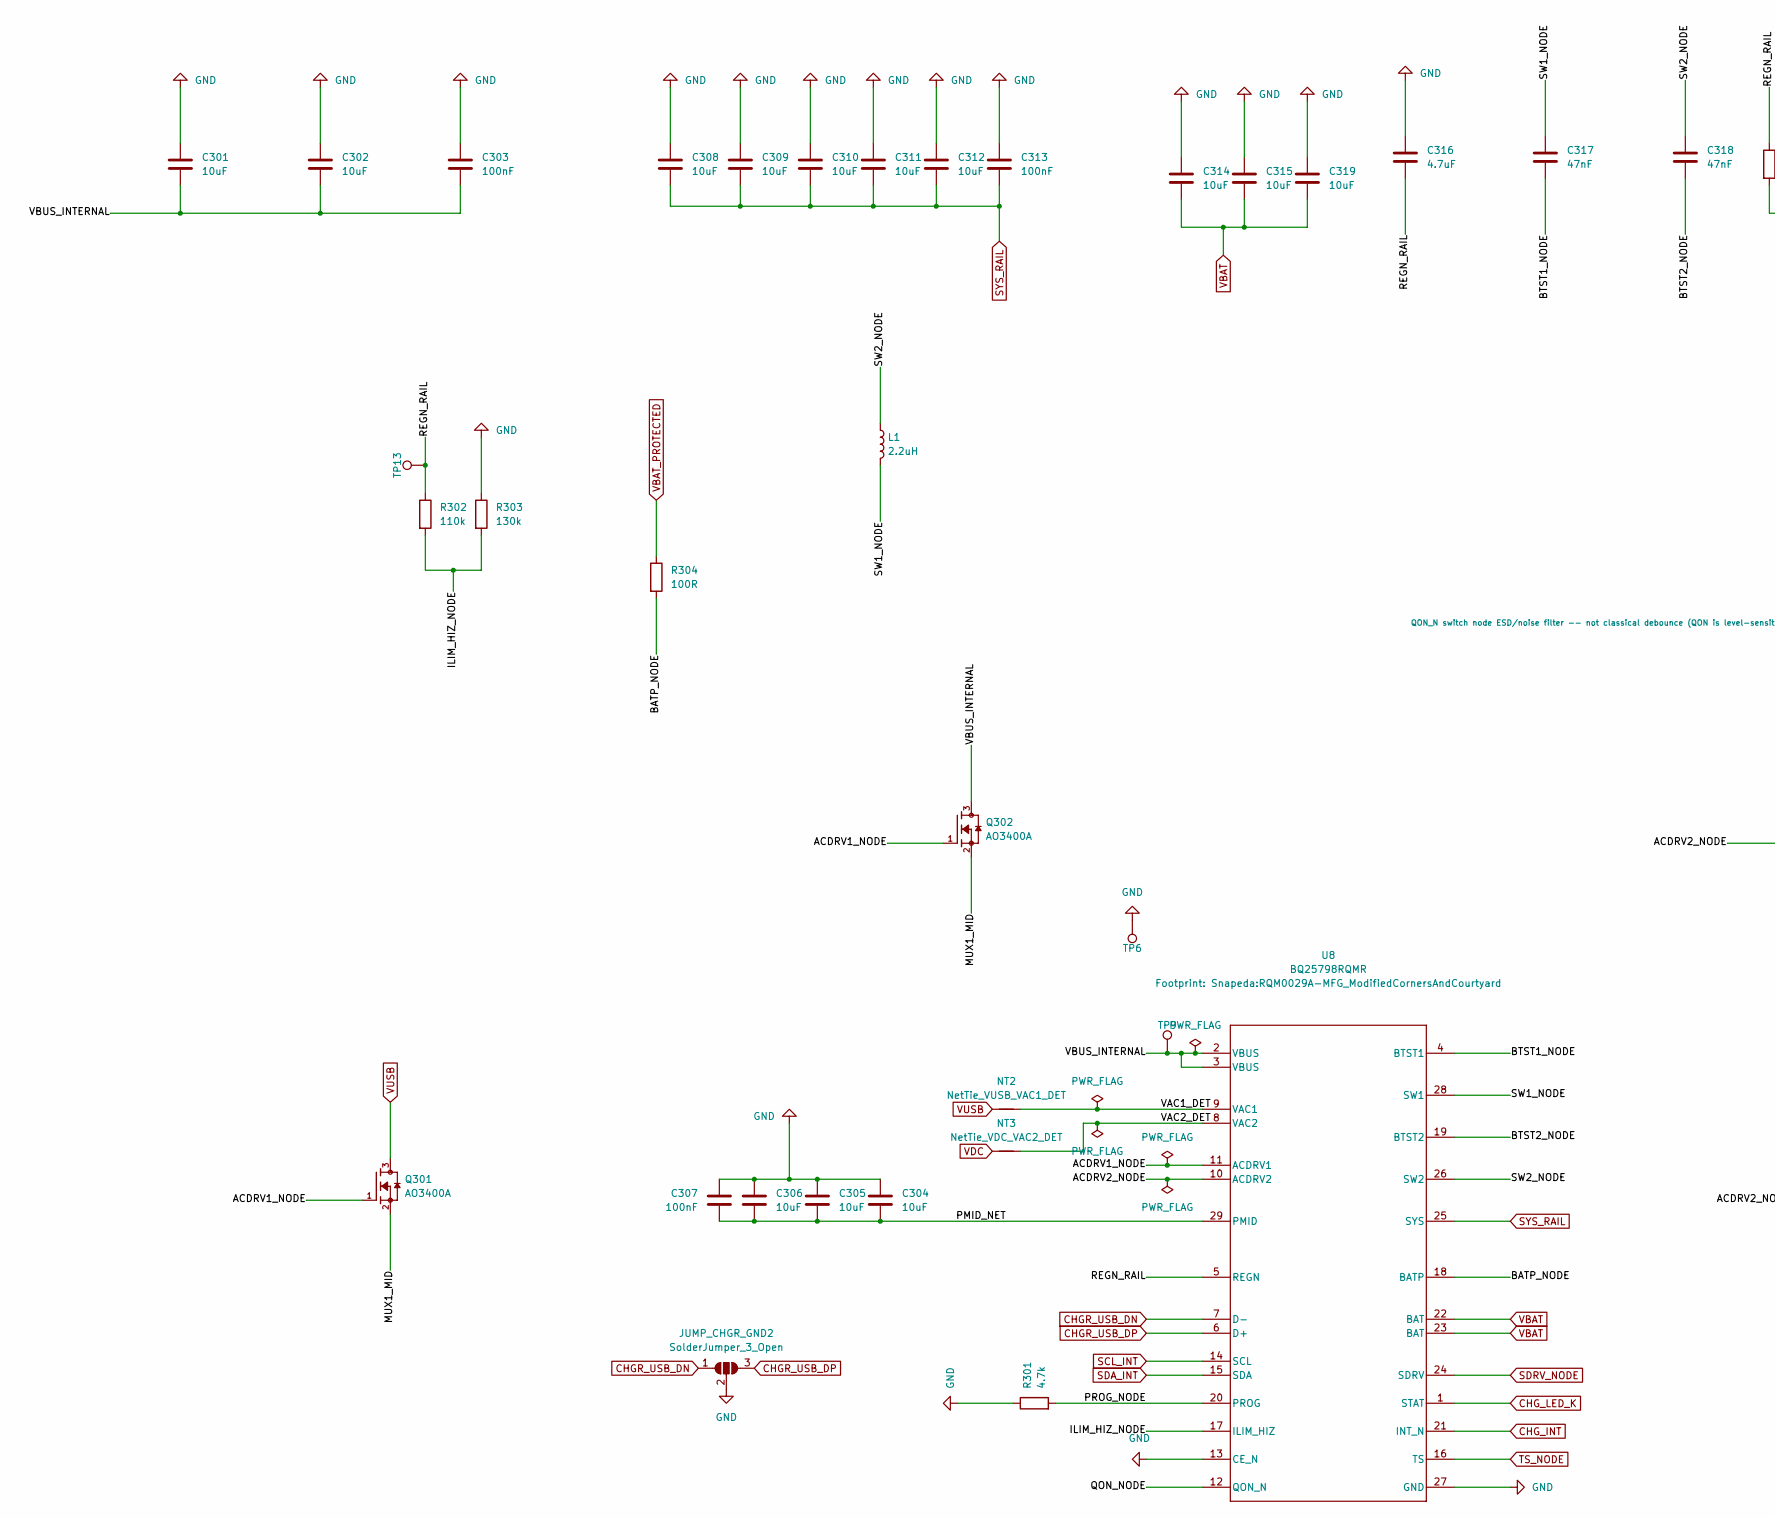
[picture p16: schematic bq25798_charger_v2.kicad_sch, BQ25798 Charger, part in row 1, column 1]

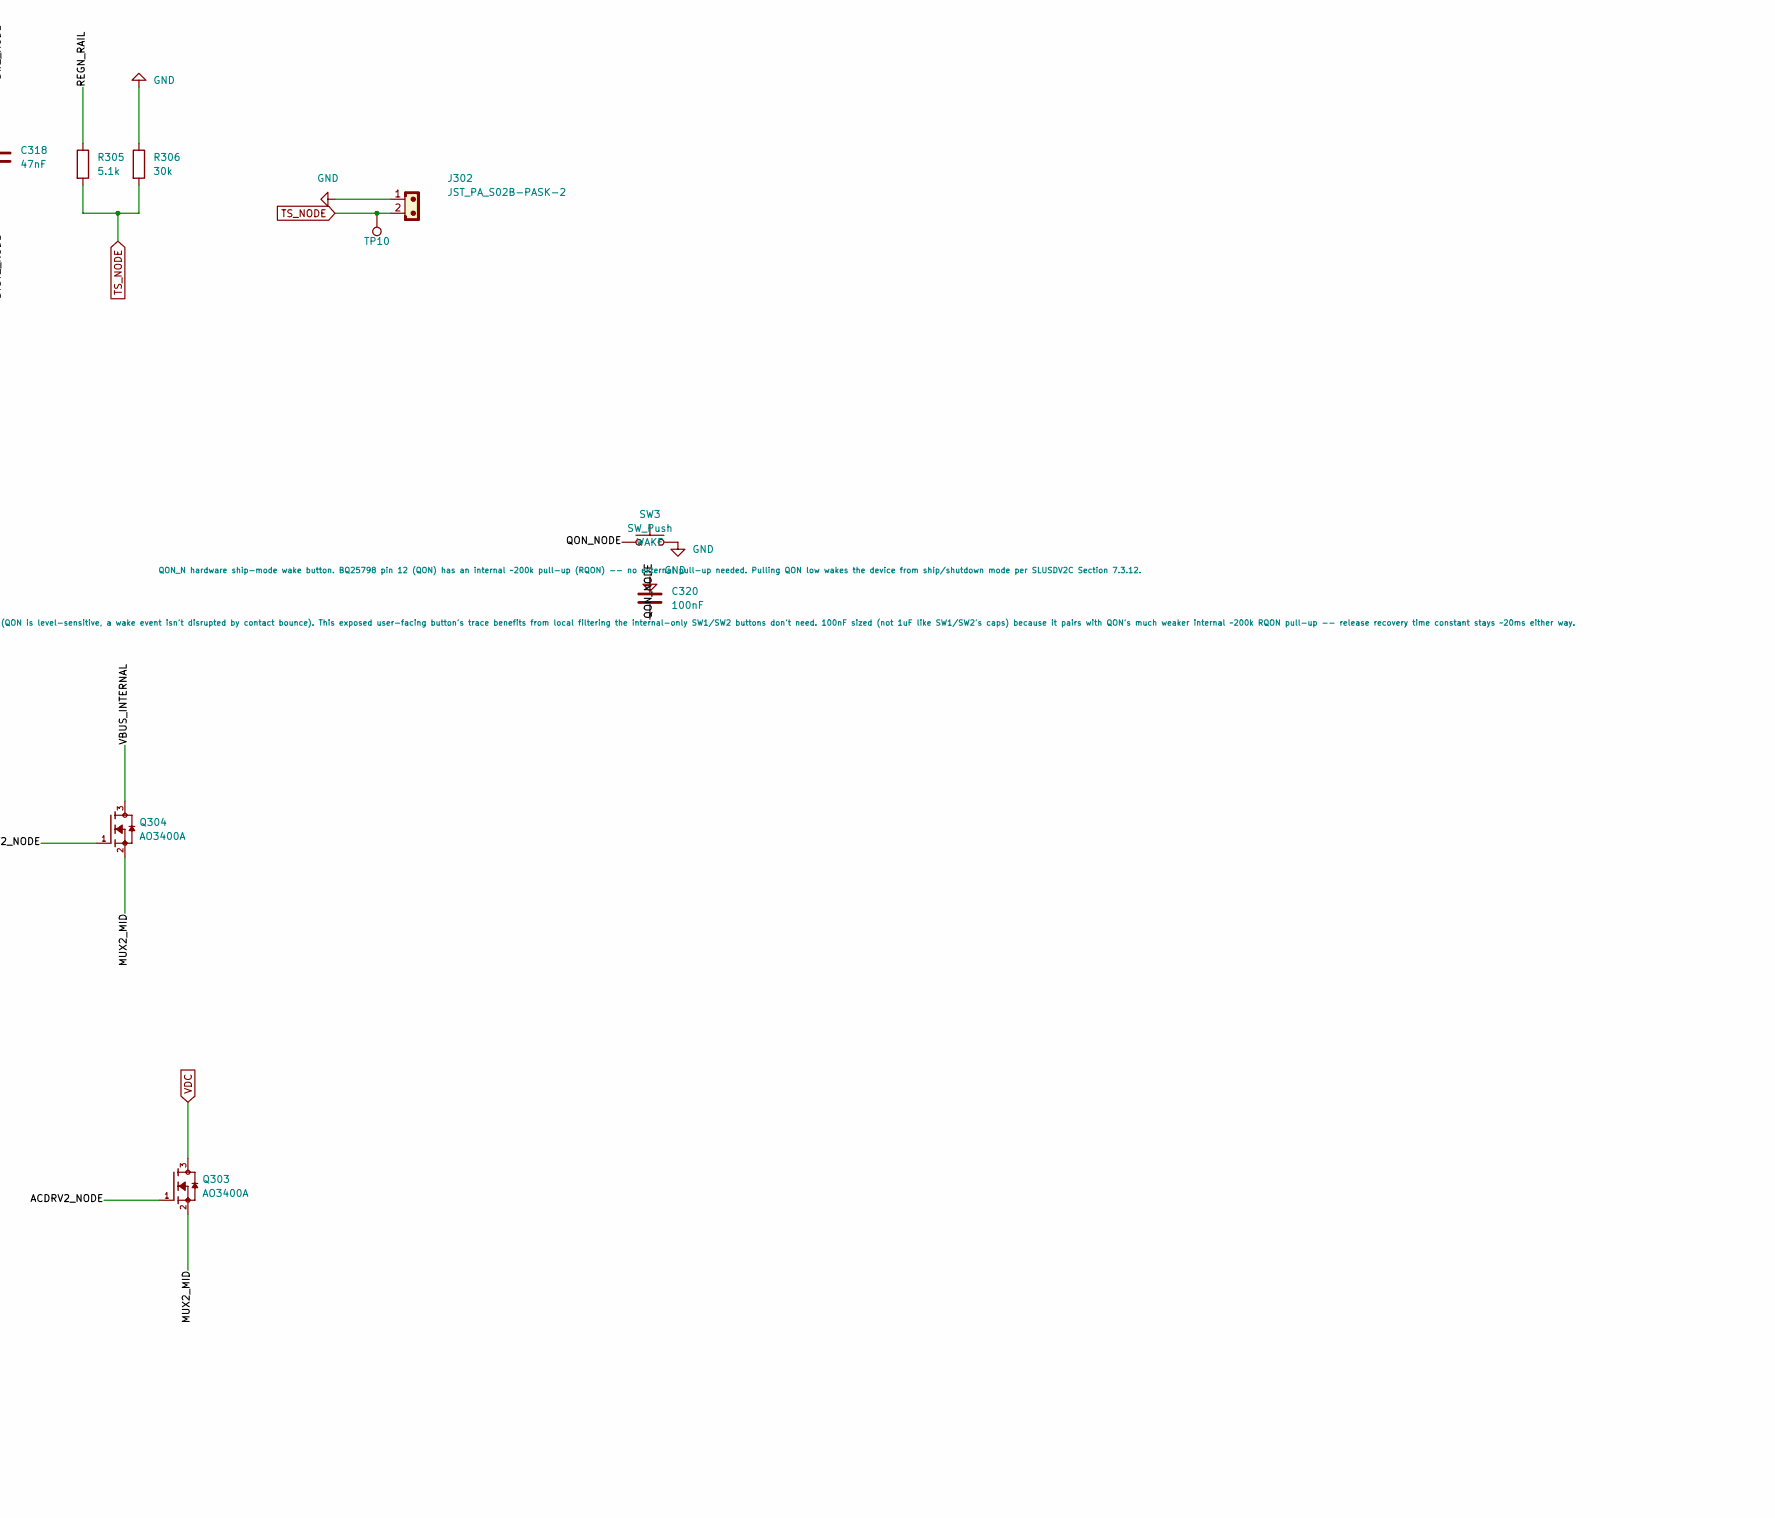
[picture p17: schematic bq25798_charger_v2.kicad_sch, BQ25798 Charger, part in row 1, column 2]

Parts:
C301, C302, C304, C305, C306: 10uF; C_0805_2012Metric; MPN GRM21BR61H106KE43L; LCSC Part C440198
C303, C307, C313, C320: 100nF; C_0402; MPN CL05B104KB54PNC; LCSC Part C307331
C308, C309, C310, C311, C312, C314, C315, C319: 10uF; C_0603_1608Metric; MPN CL10A106MA8NRNC; LCSC Part C96446
C316: 4.7uF; C_0805_2012Metric; MPN CL21A475KAQNNNE; LCSC Part C1779
C317, C318: 47nF; C_0603_1608Metric; MPN CL10B473KB8NNNC; LCSC Part C1622
J302: JST_PA_S02B-PASK-2; JST_PA_S02B-PASK-2_1x02_P2.00mm_Horizontal; MPN S02B-PASK-2(LF)(SN); LCSC Part C265094
JUMP_CHGR_GND2: SolderJumper_3_Open; SolderJumper-3_P1.3mm_Open_RoundedPad1.0x1.5mm_NumberLabels
L1: 2.2uH; L_Changjiang_FTC404030S; MPN FTC404030S2R2MGCA; LCSC Part C39676081
NT2: NetTie_VUSB_VAC1_DET; NetTie-2_SMD_Pad0.5mm
NT3: NetTie_VDC_VAC2_DET; NetTie-2_SMD_Pad0.5mm
Q301, Q302, Q303, Q304: AO3400A; SOT95P280X125-3N; MPN AO3400A; LCSC Part C20917
R301: 4.7k; R_0603_1608Metric; MPN 0603WAF4701T5E; LCSC Part C23162
R302: 110k; R_0603_1608Metric; MPN 0603WAF1103T5E; LCSC Part C25805
R303: 130k; R_0603_1608Metric; MPN 0603WAF1303T5E; LCSC Part C22795
R304: 100R; R_0603_1608Metric; MPN 0603WAF1000T5E; LCSC Part C22775
R305: 5.1k; R_0603_1608Metric; MPN 0603WAF5101T5E; LCSC Part C23186
R306: 30k; R_0603_1608Metric; MPN 0603WAF3002T5E; LCSC Part C22984
SW3: SW_Push; SW_SPST_TS-1088-xR020; MPN TS-1088-AR02016; LCSC Part C720477
TP6: GND; TestPoint-1.0mm
TP9: VBUS_INTERNAL; TestPoint-1.0mm
TP10: TS_NODE; TestPoint-1.0mm
TP13: REGN_RAIL; TestPoint-1.0mm
U8: BQ25798RQMR; RQM0029A-MFG_ModifiedCornersAndCourtyard; MPN BQ25798RQMR; LCSC Part C2876593

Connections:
/BQ25798 Charger/ACDRV1_NODE: Q301.1, Q302.1, U8.11 (ACDRV1)
/BQ25798 Charger/ACDRV2_NODE: Q303.1, Q304.1, U8.10 (ACDRV2)
/BQ25798 Charger/BATP_NODE: R304.2, U8.18 (BATP)
/BQ25798 Charger/BTST1_NODE: C317.2, U8.4 (BTST1)
/BQ25798 Charger/BTST2_NODE: C318.2, U8.19 (BTST2)
/BQ25798 Charger/ILIM_HIZ_NODE: R302.2, R303.2, U8.17 (ILIM_HIZ)
/BQ25798 Charger/MUX1_MID: Q301.2, Q302.2
/BQ25798 Charger/MUX2_MID: Q303.2, Q304.2
/BQ25798 Charger/PMID_NET: C304.2, C305.2, C306.2, C307.2, U8.29 (PMID)
/BQ25798 Charger/PROG_NODE: R301.2, U8.20 (PROG)
/BQ25798 Charger/QON_NODE: C320.2, SW3.1, U8.12 (QON_N)
/BQ25798 Charger/REGN_RAIL: C316.2, R302.1, R305.1, TP13.1 (1_1), U8.5 (REGN)
/BQ25798 Charger/SW1_NODE: C317.1, L1.2, U8.28 (SW1)
/BQ25798 Charger/SW2_NODE: C318.1, L1.1, U8.26 (SW2)
/BQ25798 Charger/VAC1_DET: NT2.2, U8.9 (VAC1)
/BQ25798 Charger/VAC2_DET: NT3.2, U8.8 (VAC2)
/BQ25798 Charger/VBUS_INTERNAL: C301.2, C302.2, C303.2, Q302.3, Q304.3, TP9.1 (1_1), U8.2 (VBUS), U8.3 (VBUS)
CHGR_USB_DN: JUMP_CHGR_GND2.1 (A), U8.7 (D-); also elsewhere on the board
CHGR_USB_DP: JUMP_CHGR_GND2.3 (B), U8.6 (D+); also elsewhere on the board
CHG_INT: U8.21 (INT_N); also elsewhere on the board
CHG_LED_K: U8.1 (STAT); also elsewhere on the board
GND: C301.1, C302.1, C303.1, C304.1, C305.1, C306.1, C307.1, C308.1, C309.1, C310.1, C311.1, C312.1, C313.1, C314.1, C315.1, C316.1, C319.1, C320.1, J302.1, JUMP_CHGR_GND2.2 (C), R301.1, R303.1, R306.1, SW3.2, TP6.1 (1_1), U8.13 (CE_N), U8.27 (GND); also elsewhere on the board
SCL_INT: U8.14 (SCL); also elsewhere on the board
SDA_INT: U8.15 (SDA); also elsewhere on the board
SDRV_NODE: U8.24 (SDRV); also elsewhere on the board
SYS_RAIL: C308.2, C309.2, C310.2, C311.2, C312.2, C313.2, U8.25 (SYS); also elsewhere on the board
TS_NODE: J302.2, R305.2, R306.2, TP10.1 (1_1), U8.16 (TS)
VBAT: C314.2, C315.2, C319.2, U8.22 (BAT), U8.23 (BAT); also elsewhere on the board
VBAT_PROTECTED: R304.1; also elsewhere on the board
VDC: NT3.1, Q303.3; also elsewhere on the board
VUSB: NT2.1, Q301.3; also elsewhere on the board



Board: 6 copper layers, 56.0 x 85.0 mm, 136 parts (21 on the bottom side), 88 nets.

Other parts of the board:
Fid1, Fid8, Fid9: Fiducial_1mm_Mask2mm
Fid6, Fid7: (no value)
MH1, MH2, MH3, MH4: MountingHole_2.7mm_M2.5

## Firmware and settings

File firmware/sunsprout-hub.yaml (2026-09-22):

# SunSprout hub board package.
#
# Describes the hardware only: the MCU module, both I2C buses, the charger, the
# fuel gauge, the status LED, the alert inputs and the switched user rail. It
# has no WiFi, API, OTA or deep-sleep configuration, so you can layer your own
# on top. See example-device.yaml for a complete device built from this file.
#
# Include it as a package:
#
#   packages:
#     hub: !include firmware/sunsprout-hub.yaml
#
# Override any of the substitutions below in your own config.

substitutions:
  # Nominal capacity of the attached cell, in mAh. Sets the charge-termination
  # current to C/10 and the fuel gauge's Design Capacity.
  battery_capacity: "6000"
  battery_energy_mwh: "19200"   # capacity x 3.2 V nominal, for LiFePO4

  # The cell chemistry. The charge voltage limit is derived from this and
  # written to the charger during setup -- the charger's PROG resistor selects
  # 4.2 V at power-on, which would damage a LiFePO4 cell. Change this if you
  # fit a different chemistry; do not set the voltage by hand.
  cell_chemistry: "lifepo4"
  # Conservative default. The hardware ceiling is 2000 mA -- see below.
  charge_current: "1000"

external_components:
  - source: github://JohnNeville/esphome-bq-drivers
    components: [bq25798, bq34z100]

esp32:
  # ESP32-C5-WROOM-1U-N8R8: 8 MB quad-SPI flash, 8 MB quad-SPI PSRAM.
  board: esp32-c5-devkitc-1
  variant: esp32c5
  flash_size: 8MB
  framework:
    type: esp-idf

psram:
  mode: quad
  speed: 80MHz

# --- I2C buses -------------------------------------------------------------
# Both buses have 4.7 kOhm pull-ups on the board.
#
# The ESP32-C5 has one general-purpose I2C controller and one low-power one.
# The low-power controller is hard-wired to GPIO2 for SDA and GPIO3 for SCL,
# which is exactly how SDA_INT and SCL_INT are routed, so the internal bus
# takes it and the user bus gets the general-purpose controller. Both run at
# once. Do not move either internal-bus pin: the low-power controller works on
# no other pair, and losing it puts the two buses back in contention.
i2c:
  # Always-on internal bus, on the low-power controller. Charger, fuel gauge
  # and the J6 port share it.
  - id: bus_internal
    sda: GPIO2      # SDA_INT / LP_I2C_SDA
    scl: GPIO3      # SCL_INT / LP_I2C_SCL
    low_power_mode: true
    scan: true

  # Switched user bus, behind the PCA9615 differential buffer. It has no power
  # until the 3V3_USER rail is enabled, so scanning it at boot finds nothing.
  - id: bus_user
    sda: GPIO9      # SDA_USER
    scl: GPIO10     # SCL_USER
    scan: false

# --- Charger ---------------------------------------------------------------
bq25798:
  i2c_id: bus_internal
  address: 0x6B
  update_interval: 30s

  battery_capacity: ${battery_capacity}
  chemistry: ${cell_chemistry}
  cell_count: 1
  default_charge_current: ${charge_current}

  # The board's PMID, SYS, SW1, SW2 and BAT copper is rated for 2 A, while the
  # IC will source 5 A. R302/R303 cap the *input* current at roughly 2 A in
  # hardware (REGN-dependent: ~2.00 A at 5 V in, ~2.14 A at 15 V in), but
  # there is no equivalent hardware limit on the charge current,
  # and in buck mode the charge current can exceed the input current. This
  # clamp is what keeps a firmware fault off the copper.
  max_charge_current: 2000

  # Q3 is the ship FET on SDRV, in series in the battery path between the
  # reverse-polarity FET Q1 and the charger's BAT pins. The charger locks
  # SDRV_CTRL (and EN_BATOC) at 0 until SFET_PRESENT is set, so this flag is
  # what makes the power-cycle button below do anything at all.
  ship_fet_present: true
  # The charger otherwise waits ~10 s before acting on SDRV_CTRL, which is a
  # long time to watch a board you just asked to reboot.
  ship_fet_action_delay: false
  # EN_BATOC opens Q3 above the IC's fixed ~9.3 A discharge threshold. That is
  # far above the 2 A this board's copper is rated for, so treat it as a
  # dead-short backstop rather than as copper protection -- the charge-current
  # ceiling below is what guards the copper.
  battery_ocp: true

  # Disabled: a watchdog expiry would silently revert the charge voltage to
  # the PROG default of 4.2 V, which would damage a LiFePO4 cell.
  watchdog: disabled

  # TS divider: R305 5.1 kOhm from REGN, R306 30 kOhm to ground, sized for
  # a 103AT-type 10 kOhm NTC. The thermistor itself is off-board, via J302.
  #
  # With J302 open the divider sits at 85.5% of REGN, above every JEITA cold
  # threshold (0 C is 73.3%), so the charger reads "too cold" and suspends
  # charging. These options only convert the TS reading into a temperature --
  # they do not write TS_IGNORE, and the driver does not expose it. A board
  # with nothing on J302 will not charge -- fit a 103AT-type 10 kOhm NTC.
  ts_resistor_upper: 5.1kOhm
  ts_resistor_lower: 30kOhm

  vbus_voltage:
    name: "Input Voltage"
    id: charger_vbus
  vac1_voltage:
    name: "USB Input Voltage"
    id: charger_vac1
  vac2_voltage:
    name: "Solar Input Voltage"
    id: charger_vac2
  vbat_voltage:
    name: "Battery Voltage"
    id: charger_vbat
  vsys_voltage:
    name: "System Voltage"
    id: charger_vsys
    disabled_by_default: true
  ibus_current:
    name: "Input Current"
    id: charger_ibus
  ibat_current:
    name: "Battery Current"
    id: charger_ibat
  battery_temperature:
    name: "Battery Temperature"
    id: charger_battery_temperature
  die_temperature:
    name: "Charger Temperature"
    disabled_by_default: true

  vbus_present:
    name: "Input Present"
  vac1_present:
    name: "USB Input Present"
  vac2_present:
    name: "Solar Input Present"
  power_good:
    name: "Power Good"
  charging:
    name: "Charging"
  battery_present:
    name: "Battery Present"
    disabled_by_default: true
  thermal_regulation:
    name: "Charger Thermal Regulation"
    disabled_by_default: true

  charge_status:
    name: "Charge Status"
  input_source:
    name: "Input Source"
  charger_fault:
    name: "Charger Fault"

  enable_charging:
    name: "Enable Charging"
    id: enable_charging
    restore_mode: ALWAYS_ON
  enable_mppt:
    name: "Enable MPPT"
    id: enable_mppt
    restore_mode: RESTORE_DEFAULT_ON
  enable_stat_led:
    name: "Charger Status LED"
    restore_mode: RESTORE_DEFAULT_ON
    disabled_by_default: true
  enable_acdrv1:
    name: "Enable USB Input"
    restore_mode: RESTORE_DEFAULT_ON
  enable_acdrv2:
    name: "Enable Solar Input"
    restore_mode: RESTORE_DEFAULT_ON
  enable_hiz:
    name: "Charger HIZ Mode"
    disabled_by_default: true
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

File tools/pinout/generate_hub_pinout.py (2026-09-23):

#!/usr/bin/env python3
"""
SunSproutHub Graphical Pinout Diagram Generator

Generates a modern, publication-grade vector SVG pinout diagram (Adafruit / SparkFun style)
for SunSproutHub. Embeds the high-resolution board render with color-coded callouts,
pin numbers, functional badges, strapping caveats, and interactive data attributes.

Usage:
    python tools/pinout/generate_hub_pinout.py \
        --board-image website/static/img/board-top.png \
        --output website/static/img/pinout-top.svg
"""

import argparse
import base64
import html
import os
import sys
from pathlib import Path


# ---------------------------------------------------------------------------
# Pin definitions for SunSproutHub
# ---------------------------------------------------------------------------

J7_PINS = [
    {"pin": 1, "board_y": 13.07, "tags": [("3V3_USER", "pwr"), ("Switched 3.3V", "pwr")]},
    {"pin": 2, "board_y": 15.61, "tags": [("GND", "gnd")]},
    {"pin": 3, "board_y": 18.15, "tags": [("GPIO0", "lp-gpio"), ("LP_GPIO0 / Wake", "lp-gpio")]},
    {"pin": 4, "board_y": 20.69, "tags": [("GPIO1", "gpio"), ("Free IO", "gpio")]},
    {"pin": 5, "board_y": 23.23, "tags": [("GPIO7", "gpio"), ("Free IO", "gpio"), ("SDIO Strap", "strap")]},
    {"pin": 6, "board_y": 25.77, "tags": [("GPIO9", "i2c-user"), ("SDA_USER", "i2c-user")]},
    {"pin": 7, "board_y": 28.31, "tags": [("GPIO10", "i2c-user"), ("SCL_USER", "i2c-user")]},
    {"pin": 8, "board_y": 30.85, "tags": [("GND", "gnd")]},
    {"pin": 9, "board_y": 33.39, "tags": [("3V3_USER", "pwr"), ("Switched 3.3V", "pwr")]},
]

J8_PINS = [
    {"pin": 1, "board_y": 13.82, "tags": [("3V3_USER", "pwr"), ("Switched 3.3V", "pwr")]},
    {"pin": 2, "board_y": 16.36, "tags": [("GND", "gnd")]},
    {"pin": 3, "board_y": 18.90, "tags": [("GPIO26", "gpio"), ("Free IO", "gpio"), ("Boot Strap", "strap")]},
    {"pin": 4, "board_y": 21.44, "tags": [("GPIO25", "gpio"), ("Free IO", "gpio"), ("Boot Strap", "strap")]},
    {"pin": 5, "board_y": 23.98, "tags": [("GPIO11", "uart"), ("U0TXD (Console)", "uart")]},
    {"pin": 6, "board_y": 26.52, "tags": [("GPIO12", "uart"), ("U0RXD (Console)", "uart")]},
    {"pin": 7, "board_y": 29.06, "tags": [("GPIO24", "gpio"), ("Free IO", "gpio")]},
    {"pin": 8, "board_y": 31.60, "tags": [("GPIO27", "gpio"), ("Free IO", "gpio"), ("Boot Strap", "strap")]},
    {"pin": 9, "board_y": 34.14, "tags": [("GPIO5", "gpio"), ("Free IO", "gpio")]},
]

LEGEND_ITEMS = [
    ("Power & Solar (3V3 / VIN)", "pwr"),
    ("Power Connectors (USB/Solar/Bat)", "pwr-conn"),
    ("Ground (GND)", "gnd"),
    ("Free GPIO", "gpio"),
    ("LP Core GPIO / Wake", "lp-gpio"),
    ("User I2C (HP_I2C)", "i2c-user"),
    ("Internal I2C (LP_I2C)", "i2c-int"),
    ("UART Console (U0TXD/RXD)", "uart"),
    ("Strapping Pins", "strap"),
    ("Buttons / Reset / Wake", "btn"),
    ("Differential I2C", "diff"),
]


# ---------------------------------------------------------------------------
# SVG Generator Implementation
# ---------------------------------------------------------------------------

def generate_pinout_svg(board_image_path: str, output_svg_path: str, css_path: str = None):
    """Renders the standalone vector SVG pinout diagram with rich typography and interactivity."""
    
    # Board physical dimensions
    BOARD_MM_W = 56.0
    BOARD_MM_H = 85.0
    
    # Canvas dimensions
    CANVAS_W = 1520
    CANVAS_H = 1040
    
    # Board placement on canvas
    BOARD_PIX_H = 650
    BOARD_PIX_W = int(BOARD_PIX_H * (BOARD_MM_W / BOARD_MM_H))  # ~428px
    BOARD_X = (CANVAS_W - BOARD_PIX_W) // 2
    BOARD_Y = 105
    
    def mm_to_canvas(bx_mm, by_mm):
        cx = BOARD_X + (bx_mm / BOARD_MM_W) * BOARD_PIX_W
        cy = BOARD_Y + (by_mm / BOARD_MM_H) * BOARD_PIX_H
        return cx, cy

    # Read CSS
    css_content = ""
    if css_path and os.path.exists(css_path):
        with open(css_path, "r", encoding="utf-8") as f:
            css_content = f.read()

    # Image source (embed as base64 data URI if found)
    image_href = ""
    if os.path.exists(board_image_path):
        try:
            from PIL import Image
            import io
            im = Image.open(board_image_path)
            if im.mode in ('RGBA', 'LA'):
                pix = im.load()
                w, h = im.size
                min_x, max_x = w, 0
                min_y, max_y = h, 0
                has_solid = False
                for y in range(h):
                    for x in range(w):
                        if pix[x, y][3] > 128:
                            has_solid = True
                            if x < min_x: min_x = x
                            if x > max_x: max_x = x
                            if y < min_y: min_y = y
                            if y > max_y: max_y = y
                if has_solid and (min_x > 0 or min_y > 0 or max_x < w - 1 or max_y < h - 1):
                    im = im.crop((min_x, min_y, max_x + 1, max_y + 1))
                    cpix = im.load()
                    for cy in range(im.size[1]):
                        for cx in range(im.size[0]):
                            if cpix[cx, cy][3] < 128:
                                cpix[cx, cy] = (0, 0, 0, 0)
            buf = io.BytesIO()
            im.save(buf, format="PNG")
            encoded = base64.b64encode(buf.getvalue()).decode("ascii")
            image_href = f"data:image/png;base64,{encoded}"
        except Exception:
            with open(board_image_path, "rb") as img_file:
                encoded = base64.b64encode(img_file.read()).decode("ascii")
                ext = Path(board_image_path).suffix.lower().lstrip(".")
                mime = "image/png" if ext == "png" else "image/jpeg"
                image_href = f"data:{mime};base64,{encoded}"
    else:
        image_href = os.path.basename(board_image_path)

    svg_lines = [
        f'<svg xmlns="http://www.w3.org/2000/svg" viewBox="0 0 {CANVAS_W} {CANVAS_H}" width="100%" height="100%" class="diagram" id="hub-pinout-svg">',
        '  <defs>',
        f'    <style type="text/css"><![CDATA[\n{css_content}\n]]></style>',
        '    <filter id="shadow" x="-5%" y="-5%" width="115%" height="115%">',
        '      <feDropShadow dx="0" dy="12" stdDeviation="16" flood-color="#000000" flood-opacity="0.6"/>',
        '    </filter>',
        '  </defs>',
        '',
        '  <!-- Background Canvas -->',
        f'  <rect width="{CANVAS_W}" height="{CANVAS_H}" fill="#0b1320"/>',
        f'  <rect x="20" y="20" width="{CANVAS_W - 40}" height="{CANVAS_H - 40}" class="panel"/>',
        '',
        '  <!-- Header Title -->',
        '  <g transform="translate(50, 68)">',
        '    <text class="title">SunSproutHub Pinout &amp; Signal Diagram</text>',
        '    <text y="26" class="subtitle">ESP32-C5-WROOM-1U • Dual Independent I2C Buses • BQ25798 Charger • BQ34Z100 Fuel Gauge</text>',
        f'    <rect x="{CANVAS_W - 250}" y="-20" width="150" height="30" rx="6" fill="#0f2b48" stroke="#0284c7" stroke-width="1.2"/>',
        f'    <text x="{CANVAS_W - 175}" y="-1" class="header-tag" text-anchor="middle">PCB REV 1.0</text>',
        '  </g>',
        '',
        '  <!-- Board Image Layer -->',
        '  <g filter="url(#shadow)">',
        f'    <image href="{image_href}" x="{BOARD_X}" y="{BOARD_Y}" width="{BOARD_PIX_W}" height="{BOARD_PIX_H}" preserveAspectRatio="none"/>',
        '  </g>',
        '',
    ]

    # Helper function to render a badge tag
    def render_badge(x, y, text, tag_type, is_right_aligned=False, width=None):
        char_len = len(text)
        w = width if width else (char_len * 8.6 + 22)
        h = 28
        rx = x - w if is_right_aligned else x
        rect_svg = f'<rect x="{rx:.1f}" y="{y - h/2:.1f}" width="{w:.1f}" height="{h:.1f}" class="badge-bg"/>'
        text_x = rx + w / 2
        escaped_text = html.escape(text)
        text_svg = f'<text x="{text_x:.1f}" y="{y:.1f}" class="badge-text" text-anchor="middle">{escaped_text}</text>'
        return f'<g class="tag-{tag_type}">{rect_svg}{text_svg}</g>', w

    # Helper function to render pin number pill
    def render_pin_pill(x, y, pnum, is_right_side=False):
        w, h = 32, 28
        rx = x if is_right_side else (x - w)
        rect = f'<rect x="{rx:.1f}" y="{y - h/2:.1f}" width="{w:.1f}" height="{h:.1f}" class="pin-num-bg"/>'
        text_x = rx + w / 2
        text = f'<text x="{text_x:.1f}" y="{y:.1f}" class="pin-num-text">{pnum}</text>'
        return f'<g>{rect}{text}</g>'

    # -----------------------------------------------------------------------
    # Left Header: J7 (9 pins)
    # -----------------------------------------------------------------------
    svg_lines.append('  <!-- J7 Expansion Header (Left Side) -->')
    j7_start_y = 175
    j7_spacing = 48
    end_x = 460
    
    svg_lines.append(f'  <text x="{end_x}" y="{j7_start_y - 25}" class="header-tag" text-anchor="end">J7 EXPANSION (2.54MM)</text>')

    for i, p in enumerate(J7_PINS):
        label_y = j7_start_y + i * j7_spacing
        pin_cx, pin_cy = mm_to_canvas(3.10, p["board_y"])
        elbow_x = BOARD_X - 35
        
        tags_csv = ",".join(t[1] for t in p["tags"])
        primary_name = p["tags"][0][0]
        
        svg_lines.append(f'  <g class="callout-group" data-pin="J7.{p["pin"]}" data-tags="{tags_csv}" data-name="{primary_name}">')
        svg_lines.append(f'    <path d="M {pin_cx:.1f} {pin_cy:.1f} L {elbow_x} {label_y} L {end_x} {label_y}" class="leader-line"/>')
        svg_lines.append(f'    <circle cx="{pin_cx:.1f}" cy="{pin_cy:.1f}" r="4.5" class="pin-dot pin-dot-{p["tags"][0][1]}"/>')
        svg_lines.append(f'    {render_pin_pill(end_x, label_y, p["pin"], is_right_side=False)}')
        
        curr_x = end_x - 38
        for text, tag_type in p["tags"]:
            badge_svg, badge_w = render_badge(curr_x, label_y, text, tag_type, is_right_aligned=True)
            svg_lines.append(f'    {badge_svg}')
            curr_x -= (badge_w + 6)
        svg_lines.append('  </g>')

    # -----------------------------------------------------------------------
    # Right Header: J8 (9 pins)
    # -----------------------------------------------------------------------
    svg_lines.append('  <!-- J8 Expansion Header (Right Side) -->')
    j8_start_y = 175
    j8_spacing = 48
    start_x = BOARD_X + BOARD_PIX_W + 55
    
    svg_lines.append(f'  <text x="{start_x}" y="{j8_start_y - 25}" class="header-tag" text-anchor="start">J8 EXPANSION (2.54MM)</text>')

    for i, p in enumerate(J8_PINS):
        label_y = j8_start_y + i * j8_spacing
        pin_cx, pin_cy = mm_to_canvas(53.00, p["board_y"])
        elbow_x = BOARD_X + BOARD_PIX_W + 35
        
        tags_csv = ",".join(t[1] for t in p["tags"])
        primary_name = p["tags"][0][0]
        
        svg_lines.append(f'  <g class="callout-group" data-pin="J8.{p["pin"]}" data-tags="{tags_csv}" data-name="{primary_name}">')
        svg_lines.append(f'    <path d="M {pin_cx:.1f} {pin_cy:.1f} L {elbow_x} {label_y} L {start_x} {label_y}" class="leader-line"/>')
        svg_lines.append(f'    <circle cx="{pin_cx:.1f}" cy="{pin_cy:.1f}" r="4.5" class="pin-dot pin-dot-{p["tags"][0][1]}"/>')
        svg_lines.append(f'    {render_pin_pill(start_x, label_y, p["pin"], is_right_side=True)}')
        
        curr_x = start_x + 38
        for text, tag_type in p["tags"]:
            badge_svg, badge_w = render_badge(curr_x, label_y, text, tag_type, is_right_aligned=False)
            svg_lines.append(f'    {badge_svg}')
            curr_x += (badge_w + 6)
        svg_lines.append('  </g>')

    # -----------------------------------------------------------------------
    # Top Callouts: SW1 & SW2 Buttons
    # -----------------------------------------------------------------------
    svg_lines.append('  <!-- Tactile Buttons (Top Area) -->')
    # SW1 (Reset)
    sw1_cx, sw1_cy = mm_to_canvas(42.40, 4.03)
    sw1_label_y = 82
    sw1_label_x = BOARD_X + BOARD_PIX_W + 120
    svg_lines.append('  <g class="callout-group" data-pin="SW1" data-tags="btn,pwr" data-name="SW1: Reset">')
    svg_lines.append(f'    <path d="M {sw1_cx:.1f} {sw1_cy:.1f} L {sw1_cx} {sw1_label_y} L {sw1_label_x} {sw1_label_y}" class="leader-line"/>')
    svg_lines.append(f'    <circle cx="{sw1_cx:.1f}" cy="{sw1_cy:.1f}" r="4.5" class="pin-dot pin-dot-pwr"/>')
    curr_x = sw1_label_x + 6
    for text, tag_type in [("SW1", "btn"), ("RESET / EN", "btn"), ("CHIP_PU", "pwr")]:
        badge_svg, badge_w = render_badge(curr_x, sw1_label_y, text, tag_type, is_right_aligned=False)
        svg_lines.append(f'    {badge_svg}')
        curr_x += (badge_w + 6)
    svg_lines.append('  </g>')

    # SW2 (Bootloader GPIO28)
    sw2_cx, sw2_cy = mm_to_canvas(42.40, 10.65)
    sw2_label_y = 118
    sw2_label_x = BOARD_X + BOARD_PIX_W + 120
    svg_lines.append('  <g class="callout-group" data-pin="SW2" data-tags="btn,strap" data-name="SW2: Bootloader">')
    svg_lines.append(f'    <path d="M {sw2_cx:.1f} {sw2_cy:.1f} L {sw2_cx + 40} {sw2_label_y} L {sw2_label_x} {sw2_label_y}" class="leader-line"/>')
    svg_lines.append(f'    <circle cx="{sw2_cx:.1f}" cy="{sw2_cy:.1f}" r="4.5" class="pin-dot pin-dot-strap"/>')
    curr_x = sw2_label_x + 6
    for text, tag_type in [("SW2", "btn"), ("GPIO28", "strap"), ("Download Boot Strap", "strap")]:
        badge_svg, badge_w = render_badge(curr_x, sw2_label_y, text, tag_type, is_right_aligned=False)
        svg_lines.append(f'    {badge_svg}')
        curr_x += (badge_w + 6)
    svg_lines.append('  </g>')

    # -----------------------------------------------------------------------
    # Center / Bottom Peripherals: Stemma QT, USB-C, Solar, Buttons, Differential
    # -----------------------------------------------------------------------
    svg_lines.append('  <!-- Peripherals & Ports -->')
    # J4 (Battery Connector JST PH)
    j4_cx, j4_cy = mm_to_canvas(48.995, 48.187)
    j4_label_y = 615
    j4_label_x = BOARD_X + BOARD_PIX_W + 55
    svg_lines.append('  <g class="callout-group" data-pin="J4" data-tags="pwr-conn,pwr" data-name="J4: Battery Connector (JST PH)">')
    svg_lines.append(f'    <path d="M {j4_cx:.1f} {j4_cy:.1f} L 940.0 {j4_cy:.1f} L 940.0 {j4_label_y} L {j4_label_x} {j4_label_y}" class="leader-line"/>')
    svg_lines.append(f'    <circle cx="{j4_cx:.1f}" cy="{j4_cy:.1f}" r="4.5" class="pin-dot pin-dot-pwr-conn"/>')
    curr_x = j4_label_x + 6
    for text, tag_type in [("J4", "pwr-conn"), ("Battery (JST PH)", "pwr-conn"), ("VBAT / GND", "pwr")]:
        badge_svg, badge_w = render_badge(curr_x, j4_label_y, text, tag_type, is_right_aligned=False)
        svg_lines.append(f'    {badge_svg}')
        curr_x += (badge_w + 6)
    svg_lines.append('  </g>')

    # J6 (Stemma QT Int)
    j6_cx, j6_cy = mm_to_canvas(39.81, 28.32)
    j6_label_y = 665
    j6_label_x = BOARD_X + BOARD_PIX_W + 55
    svg_lines.append('  <g class="callout-group" data-pin="J6" data-tags="i2c-int" data-name="J6: STEMMA QT (Internal)">')
    svg_lines.append(f'    <path d="M {j6_cx:.1f} {j6_cy:.1f} L 905.0 {j6_cy:.1f} L 905.0 {j6_label_y} L {j6_label_x} {j6_label_y}" class="leader-line"/>')
    svg_lines.append(f'    <circle cx="{j6_cx:.1f}" cy="{j6_cy:.1f}" r="4.5" class="pin-dot pin-dot-i2c-int"/>')
    curr_x = j6_label_x + 6
    for text, tag_type in [("J6", "i2c-int"), ("STEMMA QT Internal", "i2c-int"), ("LP_I2C (GPIO2/3)", "i2c-int")]:
        badge_svg, badge_w = render_badge(curr_x, j6_label_y, text, tag_type, is_right_aligned=False)
        svg_lines.append(f'    {badge_svg}')
        curr_x += (badge_w + 6)
    svg_lines.append('  </g>')

    # J203 (Stemma QT User)
    j203_cx, j203_cy = mm_to_canvas(39.81, 36.61)
    j203_label_y = 715
    j203_label_x = BOARD_X + BOARD_PIX_W + 55
    svg_lines.append('  <g class="callout-group" data-pin="J203" data-tags="i2c-user" data-name="J203: STEMMA QT (User)">')
    svg_lines.append(f'    <path d="M {j203_cx:.1f} {j203_cy:.1f} L 870.0 {j203_cy:.1f} L 870.0 {j203_label_y} L {j203_label_x} {j203_label_y}" class="leader-line"/>')
    svg_lines.append(f'    <circle cx="{j203_cx:.1f}" cy="{j203_cy:.1f}" r="4.5" class="pin-dot pin-dot-i2c-user"/>')
    curr_x = j203_label_x + 6
    for text, tag_type in [("J203", "i2c-user"), ("STEMMA QT User", "i2c-user"), ("HP_I2C (GPIO9/10)", "i2c-user")]:
        badge_svg, badge_w = render_badge(curr_x, j203_label_y, text, tag_type, is_right_aligned=False)
        svg_lines.append(f'    {badge_svg}')
        curr_x += (badge_w + 6)
    svg_lines.append('  </g>')

    # SW3 (Wake Button)
    sw3_cx, sw3_cy = mm_to_canvas(35.79, 55.83)
    sw3_label_y = 765
    sw3_label_x = BOARD_X + BOARD_PIX_W + 55
    svg_lines.append('  <g class="callout-group" data-pin="SW3" data-tags="btn,pwr" data-name="SW3: Wake Button">')
    svg_lines.append(f'    <path d="M {sw3_cx:.1f} {sw3_cy:.1f} L 835.0 {sw3_cy:.1f} L 835.0 {sw3_label_y} L {sw3_label_x} {sw3_label_y}" class="leader-line"/>')
    svg_lines.append(f'    <circle cx="{sw3_cx:.1f}" cy="{sw3_cy:.1f}" r="4.5" class="pin-dot pin-dot-btn"/>')
    curr_x = sw3_label_x + 6
    for text, tag_type in [("SW3", "btn"), ("WAKE", "btn"), ("Ship-Mode Wake (QON)", "pwr")]:
        badge_svg, badge_w = render_badge(curr_x, sw3_label_y, text, tag_type, is_right_aligned=False)
        svg_lines.append(f'    {badge_svg}')
        curr_x += (badge_w + 6)
    svg_lines.append('  </g>')

    # USBC1 (USB-C Native Receptacle)
    usbc_cx, usbc_cy = mm_to_canvas(2.67, 47.71)
    usbc_label_y = 615
    usbc_label_x = BOARD_X - 55
    svg_lines.append('  <g class="callout-group" data-pin="USBC1" data-tags="pwr-conn,pwr" data-name="USBC1: USB-C Native">')
    svg_lines.append(f'    <path d="M {usbc_cx:.1f} {usbc_cy:.1f} L {usbc_cx - 25} {usbc_label_y} L {usbc_label_x} {usbc_label_y}" class="leader-line"/>')
    svg_lines.append(f'    <circle cx="{usbc_cx:.1f}" cy="{usbc_cy:.1f}" r="4.5" class="pin-dot pin-dot-pwr-conn"/>')
    curr_x = usbc_label_x - 6
    for text, tag_type in [("USBC1", "pwr-conn"), ("USB-C Native", "pwr-conn"), ("VBUS • D+/D-", "pwr-conn")]:
        badge_svg, badge_w = render_badge(curr_x, usbc_label_y, text, tag_type, is_right_aligned=True)
        svg_lines.append(f'    {badge_svg}')
        curr_x -= (badge_w + 6)
    svg_lines.append('  </g>')

    # CN5 (Solar Input Terminal Block)
    cn5_cx, cn5_cy = mm_to_canvas(4.06, 65.58)
    cn5_label_y = 665
    cn5_label_x = BOARD_X - 55
    svg_lines.append('  <g class="callout-group" data-pin="CN5" data-tags="pwr-conn,pwr" data-name="CN5: Solar Input Terminal">')
    svg_lines.append(f'    <path d="M {cn5_cx:.1f} {cn5_cy:.1f} L {cn5_cx - 30} {cn5_label_y} L {cn5_label_x} {cn5_label_y}" class="leader-line"/>')
    svg_lines.append(f'    <circle cx="{cn5_cx:.1f}" cy="{cn5_cy:.1f}" r="4.5" class="pin-dot pin-dot-pwr-conn"/>')
    curr_x = cn5_label_x - 6
    for text, tag_type in [("CN5", "pwr-conn"), ("Solar Input", "pwr-conn"), ("VIN_SOLAR / GND", "pwr")]:
        badge_svg, badge_w = render_badge(curr_x, cn5_label_y, text, tag_type, is_right_aligned=True)
        svg_lines.append(f'    {badge_svg}')
        curr_x -= (badge_w + 6)
    svg_lines.append('  </g>')

    # J201 / J202 (Differential I2C)
    diff_cx, diff_cy = mm_to_canvas(28.00, 80.00)
    diff_label_y = 715
    diff_label_x = BOARD_X - 55
    svg_lines.append('  <g class="callout-group" data-pin="J201/J202" data-tags="diff" data-name="J201/J202: Differential I2C">')
    svg_lines.append(f'    <path d="M {diff_cx:.1f} {diff_cy:.1f} L {diff_cx - 80} {diff_label_y} L {diff_label_x} {diff_label_y}" class="leader-line"/>')
    svg_lines.append(f'    <circle cx="{diff_cx:.1f}" cy="{diff_cy:.1f}" r="4.5" class="pin-dot pin-dot-diff"/>')
    curr_x = diff_label_x - 6
    for text, tag_type in [("J201 / J202", "diff"), ("Diff I2C (PCA9615)", "diff"), ("Dual 8P8C / RJ45", "diff")]:
        badge_svg, badge_w = render_badge(curr_x, diff_label_y, text, tag_type, is_right_aligned=True)
        svg_lines.append(f'    {badge_svg}')
        curr_x -= (badge_w + 6)
    svg_lines.append('  </g>')

    # -----------------------------------------------------------------------
    # Legend Bar (Footer)
    # -----------------------------------------------------------------------
    legend_y = CANVAS_H - 125
    legend_h = 100
    svg_lines.append('  <!-- Legend Panel -->')
    svg_lines.append(f'  <rect x="50" y="{legend_y}" width="{CANVAS_W - 100}" height="{legend_h}" rx="10" fill="#09101d" stroke="#1e293b" stroke-width="1.2"/>')
    svg_lines.append(f'  <text x="70" y="{legend_y + 22}" class="legend-title">Signal Classification Legend (Click to Filter)</text>')

    leg_x = 70
    leg_item_y = legend_y + 52
    line_h = 34
    for name, tag_type in LEGEND_ITEMS:
        badge_svg, w = render_badge(leg_x, leg_item_y, name, tag_type, is_right_aligned=False)
        if leg_x + w > CANVAS_W - 70:
            leg_x = 70
            leg_item_y += line_h
            badge_svg, w = render_badge(leg_x, leg_item_y, name, tag_type, is_right_aligned=False)
        svg_lines.append(f'  <g class="legend-badge" data-tag="{tag_type}" style="cursor: pointer;">{badge_svg}</g>')
        leg_x += (w + 14)

    svg_lines.append('</svg>')
    
    # Write output
    os.makedirs(os.path.dirname(os.path.abspath(output_svg_path)), exist_ok=True)
    with open(output_svg_path, "w", encoding="utf-8") as f:
        f.write("\n".join(svg_lines))
    print(f"Generated pinout diagram: {output_svg_path}")
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

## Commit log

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2026-09-15 Key the ERC baseline on symbol, not pin uuid, so CI stops flapping
    CI's first real run failed on a violation that was not a design change. The
    GPIO1 to GPIO3 move caused ERC to report power_pin_not_driven against U3 pin 6
    (REGIN) where it had previously reported pin 4 (BAT).
    Both pins sit on the same VBAT net, along with U3 pin 5. ERC emits one
    violation per net for this rule and names an arbitrary representative pin, so
    which pin appears is not stable across unrelated edits. Keying the baseline on
    that pin's uuid made the check fail on noise.
    Matching now uses (rule type, symbol reference). That collapses the ten
    recorded entries to five -- one per symbol rather than one per representativ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
2026-09-15 Clamp Q2's gate so the DC input can run to the charger's full 24 V (#1)
    * Clamp Q2's gate so the DC input can run to the charger's full 24 V
    The solar/DC reverse-polarity FET Q2 is self-biased: its gate sits at ground
    through R19, so the full input voltage appears across the gate oxide. That is
    true in normal operation, not only under a reversed source - a correctly
    connected 24 V panel stresses the gate exactly as hard as a backwards one. The
    DMP3098L-7's +/-20 V gate rating therefore capped the usable input at 20 V,
    below the 24 V the BQ25798 itself accepts. The protection, not the charger, was
    setting the ceiling.
    D2 (BZT52C12S, 12 V zener, LCSC C19077447) clamps gate-to-source: cathode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
    [SunSproutHub.kicad_pcb, SunSproutHub.kicad_sch, TPS631000_PowerRegulation_v2.kicad_sch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]
2026-09-16 Add ESPHome firmware for the hub's charger and fuel gauge (#2)
    * Add ESPHome firmware for the hub's charger and fuel gauge
    Adds a board package and an example device configuration for the SunSprout
    hub, plus the design notes behind them. The BQ25798 and BQ34Z100 drivers
    live in JohnNeville/esphome-bq-drivers, because they are drivers for stock TI
    parts rather than anything specific to this board; the package pulls them in
    through external_components.
    Four hardware facts shape the configuration, each easy to get wrong:
    - The charger reads its PROG resistor at power-on and comes up configured for
    a 4.2 V cell, which would damage the LiFePO4 cell this board is built for.
    The package decl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
    [sunsprout-hub.yaml]
2026-09-16 Correct the input-current-limit and no-firmware-charging claims (#5)
    * Correct the input-current-limit and no-firmware-charging claims
    Two documented claims were wrong, both found by checking this board against the
    BQ25798 reference design at Marek128b/BQ25798-mppt-solar-charger, whose own
    write-up derives the ILIM divider and reports its 1 A target landing at 975 mA.
    The input limit is not "exactly 2.00 A". The charger derives the clamp from
    V(ILIM_HIZ) = 1 V + 800 mOhm * I, and the R302/R303 divider sets that voltage as
    a fraction of REGN - which is itself input-dependent: 4.8 V typical at a 5 V
    input, 5.0 V at 15 V, specified over 4.6 V to 5.2 V. The divider was sized for
    the 5 V case,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
    [sunsprout-hub.yaml]
2026-09-16 Correct the claim that the gauge chemistry needs bqStudio per board (#8)
    All three firmware pages said the LiFePO4 chemistry profile "cannot be loaded
    over I2C". That overstates the datasheet.
    What holds: there is no I2C command that sets the chemistry -- CHEM_ID only
    reports it -- the one selection path TI documents is the BQChem feature in
    bqStudio (SS8.1.2.1.6), and the chemistry tables are not published. The gauge
    ships set up for Li-ion, with Device Chemistry defaulting to LION.
    What does not hold: that the write is out of reach. The chemistry is ordinary
    data flash, and SS7.2.3.1 lists "the BQ34Z100 evaluation software or ... data
    flash block transfers" as the two routes -- the secon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
2026-09-16 Pack the gerber archive with Python instead of the missing zip(1) (#9)
    The KiCad container image has no zip binary, so the release job died at
    exit 127 right after plotting the gerbers. Python ships with the image,
    and `python3 -m zipfile -c` from inside gerbers/ produces the same flat
    archive the fab houses expect.
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2026-09-16 Drop the rejected resistor workaround for the missing thermistor (#11)
    * Drop the fixed-resistor workaround for the missing thermistor
    The earlier text pointed at a 10 kOhm resistor across J302 as the tracked fix.
    That was my own proposal, not the datasheet's. TI gives no guidance at all for
    an unused TS pin - the pin description says to connect an NTC and recommends a
    103AT-2, section 7.3.9.5 assumes a thermistor throughout, and the application
    chapter mentions TS only to say route it away from the switching nodes. The
    absence is telling, since the same datasheet does give unused-pin guidance
    elsewhere, recommending a 1 nF cap from SDRV to BAT when no ship FET is fitted.
    The resistor is a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
    [sunsprout-hub.yaml]
2026-09-16 Stamp the released gerbers with the commit they were built from (#12)
    * Stamp the released gerbers with the commit they were built from
    The board silkscreens ${VCSSHORTHASH}, but only the KiCad GUI resolves that
    variable. kicad-cli renders the literal "no hash", so every headless export has
    shipped an unstamped board and the fab output could not be traced to a revision.
    Confirmed it was never a CI problem: exporting F.SilkS locally from a clean
    checkout and diffing against the CI gerber gave byte-identical geometry, the
    only differences being the KiCad version and timestamp headers.
    A project text variable of the same name does take precedence over the built-in,
    so write the short SHA int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
2026-09-16 Build the release fab set with Fabrication Toolkit, and drop the local script (#13)
    JLCPCB rejects kicad-cli's pick-and-place outright - it emits
    Ref,Val,Package,PosX,PosY,Rot,Side where the uploader wants
    Designator,Mid X,Mid Y,Rotation,Layer - so the CPL in every release so far has
    been unusable. Fabrication Toolkit writes JLCPCB's own headers, applies the
    rotation and offset corrections their assembler expects, and names the gerbers
    with the Protel extensions they recommend.
    It runs in the stock KiCad image with no private libraries, since the board
    carries its own footprint geometry; only xvfb has to be installed on top.
    Pinned to the same 5.3.1 tools/kicad-ci.Dockerfile uses.
    This als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
2026-09-17 Modify release workflow for PDF and STEP file naming
    Updated output filenames for schematic PDF and STEP model exports to include branch name and short SHA.
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2026-09-17 Swap thermistor inputs J302/J401 from JST ZH to JST PA
    The ZH (S2B-ZR) 1.5 mm housings are impractical to hand-crimp, which
    blocks the intended workflow of an end user terminating their own NTC
    probe. Move both thermistor inputs to JST PA 2.0 mm side entry
    (S02B-PASK-2, LCSC C265094).
    Why PA over the alternatives:
    - Not PH. J4 (battery input) is already JST PH 2.0 mm; sharing that
    family would let a 4.2 V cell be plugged onto a BQ25798 TS pin.
    - Rated -40..+105 C, against -25..+85 C for PH, XH and EH. The connector
    should not be narrower than the range the thermistor qualifies.
    - Positive lock. An intermittent TS connection reads as out-of-range and
    suspends charging, so retention ma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
    [SunSproutHub.kicad_pcb, bq25798_charger_v2.kicad_sch, bq34z100_fuel_gauge_v2.kicad_sch]
2026-09-17 Dial in the JST TH connection placement for JLCPCB Fix minor issue in RJ45 ports
    [SunSproutHub.kicad_pcb]
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2026-09-19 Move charger to 750kHz, fix inductor selection, rework USB data tap
    Switch the BQ25798 to its 750kHz mode and correct both power inductors,
    which were specified from unverifiable data and fitted on a land pattern
    JLCPCB flagged as undersized.
    Inductors
    - R301 3.0k -> 4.7k (C23162, Basic): selects 750kHz/1s per Table 7-1.
    - L1 -> FTC404030S2R2MGCA (C39676081), 2.2uH/10.5A/22mOhm. Datasheet
    8.2.2.2 ties inductance to frequency: 750kHz works only with 2.2uH.
    - L2 -> FTC252012S1R0MBCD (C22400405), 1uH/6.5A/16mOhm. Not in TI's
    Table 7-2 but beats every listed part; the top entry (Murata
    DFE252012P-1R0M=P2) is 4.3A/42mOhm in the same body.
    - Both now use manufacturer-drawn KiCad footprints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
    [SunSproutHub.kicad_pcb, SunSproutHub.kicad_sch, TPS631000_PowerRegulation_v2.kicad_sch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]
2026-09-19 Mask over D5 net-tie stub pads 1c/3c
    Pads 1c and 3c are the charger-branch legs of the D+/D- star point. They
    sit outside the SOT-23-6 body at y=-1.59/+1.6 with no lead on them, but
    were still opening soldermask and taking stencil paste.
    Set both to (layers "F.Cu") so they behave as copper only, like a trace,
    and drop the now-inert solder_mask_margin. Pads 1a/1b and 3a/3b are each
    exactly half a standard land (0.48895 of 0.9779) under the actual lead
    and keep their mask and paste.
    This removes paste that had nowhere to go and structurally eliminates the
    solder_mask_bridge error class at those two locations.
    Applied to both the library footprint and the placed instance, since
    library edits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
    [SunSproutHub.kicad_pcb]
2026-09-19 Populate VCC_1/VCC_2/GND on the differential I2C net-tie footprint, document VCC_2 jumper
    The USBLC6-4SC6-ES net-tie footprint was missing copper for VCC_1/VCC_2/GND,
    leaving those nets unpopulated on the differential I2C jacks despite being
    wired in schematic. Added a dedicated net-tie footprint
    (SOT23-6L_STM_w_NetTies_1346ab) and reworked the ESD device footprint/symbol
    to carry all three nets through.
    Documented the JP2/JP3/J2 VCC_2 power-injection scheme in
    pca9615-i2c-buffer.md: JP2/JP3 default-bridge VCC_2/GRN_N to the board's own
    3V3_USER/GND, and can be cut to feed VCC_2 from an external 5V/12V boost
    converter via J2 later without touching this sheet.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
    [SunSproutHub.kicad_pcb, i2c_buffer_v2.kicad_sch]
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2026-09-19 Remove TPS631000 output cap C29, regenerate docs-site assets
    C29 (1nF) sat on the PCB between U4 and C14, pushing the 47µF output
    capacitor - the one the datasheet's Section 7.4.1 layout guidance actually
    asks to be closest to VOUT/PGND - further from the IC. Section 7.2.2.3
    recommends a single 47µF output cap with no upper limit; C29 was never a
    datasheet requirement, so it's gone and C14 can sit where it belongs.
    docs/hub/modules/tps631000-regulator.md updated to match (single output
    cap). Also corrects an earlier mix-up in tps22918-load-switch.md: C18
    (100nF) is TPS22918's VOUT decoupling cap, not a TPS631000 part - it
    never belonged in the TPS631000 doc's capacitor table.
    Also includ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
    [SunSproutHub.kicad_pcb, TPS631000_PowerRegulation_v2.kicad_sch, bq25798_charger_v2.kicad_sch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]
2026-09-19 Fix rotation and add orientation mark to TVs for diff i2c collect and embed 3d models
    [SunSproutHub.kicad_pcb]
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2026-09-21 fix(satellite): Consolidate shared libraries, fix MDX/links, and update JST PA LCSC part (#24)
    * Consolidate Hub and Satellite libraries into shared hardware/libraries
    * Add SunSprout logo to Satellite silkscreen and refresh documentation assets
    * Fix MDX compilation error and broken links in satellite documentation
    * Update DS18B20 and moisture probe connectors to JST PA with LCSC part C131339
    [SunSproutSatellite.kicad_pcb, adc_sensors.kicad_sch, adc_sensors_v1.kicad_sch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]
2026-09-22 feat(hardware, website): Hub & Satellite layout review fixes, interactive pinout component, and dual-board documentation (#25)
    ## Overview
    This PR completes post-routing design review fixes across both the **SunSprout Hub** and **SunSprout Satellite** PCBs, resolves ESPHome firmware driver dependencies, and upgrades the documentation site with interactive React pinout components, enhanced typography, and a true-to-scale dual-board hero showcase.
    ## Key Changes
    ### 1. Hardware & PCB Layout Fixes
    * **Checklist Audit:** Fully audited both boards against standard DFM/DFA and mass-manufacturing layout checklists (0 DRC violations, 0 unconnected items).
    * **Hub Improvements (`hardware/hub`):**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
    [SunSproutHub.kicad_pcb, SunSproutHub.kicad_sch, SunSproutSatellite.kicad_pcb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]
2026-09-22 fix(satellite+hub): fix 3D render solder mask; prune legacy static doc assets (#26)
    - Hardware & Tooling:
    - Update `pcbplotparams layerselection` in `SunSproutSatellite.kicad_pcb` to
    enable solder mask layers (`F.Mask`, `B.Mask`), resolving an issue where
    `kicad-cli pcb render` produced a black substrate with naked copper traces.
    - Pass `--preset follow_pcb_editor` in `tools/generate-docs-assets.sh` so
    CLI 3D renders always faithfully reflect the full board assembly.
    - Re-render Satellite top/bottom orthographic views and the combined hero
    with consistent green solder mask finish.
    - Static Assets & Cleanup:
    - Remove unstyled draft SVGs (`pinout-top-draft.svg`,
    `sa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
    [SunSproutHub.kicad_pcb, SunSproutSatellite.kicad_pcb]
2026-09-22 fix(docs): fix Satellite render aspect ratio and use primary board images for hero cards
    - Fix Satellite 3D render aspect ratio:
    - Update tools/generate-docs-assets.sh viewport for Satellite from 1200x1800 to 960x1800 to match its 27.25 x 51.10 mm (0.533) physical aspect ratio without empty side padding.
    - Re-render satellite-board-top.png, satellite-board-bottom.png, and regenerate satellite pinout SVGs.
    - Simplify hero showcase & drop redundant scripts:
    - Update website/src/pages/index.tsx to link directly to board-top.png and satellite-board-top.png.
    - Proportionalize hero card heights and apply native GPU filter: drop-shadow(...) in index.module.css, guaranteeing 1:1 physical sca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
2026-09-22 ci(docker): handle unauthorized token gracefully when cloning vendor library
    - Wrap private library git clone in kicad-assets.Dockerfile with failure fallback so unauthorized tokens don't fail the build
    - Set GITHUB_TOKEN in deploy-docs.yml to PAT_TOKEN only to avoid passing default repo token that lacks cross-repo access
2026-09-22 fix(ci): run docker with root permissions to prevent permission denied on mounted volume
2026-09-23 fix(docs): separate Buttons and USB-C filters, correct CN5 to solar input terminal, and add USBC1 & SW3 callouts
    [generate_hub_pinout.py]
2026-09-23 fix(docs): update satellite pinouts with accurate U2/ADS1115 location, 1-Wire & Qwiic callouts, TVS/termination, and swap bottom jumper sides
    [generate_satellite_pinout.py]
2026-09-23 fix(docs): resolve J6 and J203 leader line overlap on Hub pinout
    [generate_hub_pinout.py]
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2026-09-23 feat(docs): replace USB category with Power Connectors for USB-C, Solar, and Battery connectors
    [generate_hub_pinout.py]
2026-09-23 docs: correct JP2/JP3 documentation to RJ45 aux power isolation (VCC_2)
    [generate_hub_pinout.py]
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2026-09-23 feat(satellite): redesign power entry architecture, solder jumpers, and address footprints
    - Decouple raw cable power (Pair 1: RJ45_VCC_1/GND_1, Pair 3: RJ45_VCC_2/GND_2) onto 4P header J7
    - Add 2P header J9 for local satellite power (SAT_3V3, GND) to support external regulation
    - Add normally-closed cuttable jumpers JP18 (VCC_1 <-> SAT_3V3) and JP17 (GND_1 <-> GND)
    - Tie PCA9615 VDDB, diff termination bias (R3/R5/R6/R8), and TVS U4 to RJ45_VCC_1/GND_1
    - Place bulk cap C1 (22uF) across RJ45_VCC_1 and RJ45_GND_1 at cable entry
    - Split inner planes: continuous RJ45_GND_1 reference on In2.Cu under B.Cu diff pairs; In1.Cu split (SAT GND, RJ45 GND, VCC2)
    - Update 1-Wire address jumper footprint w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
    [SunSproutSatellite.kicad_pcb, _hybrid.kicad_sch, _mintest.kicad_sch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]
2026-09-24 docs(satellite): update specifications, schematics, net references, and pinout diagrams for power redesign
    [generate_satellite_pinout.py]
2026-09-24 Update website assets for redesigned satellite board
    [SunSproutSatellite.kicad_pcb]
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2026-09-24 Fixed missed 603 component that was marked DNP
    [SunSproutSatellite.kicad_pcb, onewire_v1.kicad_sch]
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2026-10-13 fix(firmware): silence the unavoidable GPIO2 strapping-pin warning
    SDA_INT has to be on GPIO2: the low-power I2C controller is hard-wired to
    GPIO2/GPIO3, so the pin cannot move. Mark it with ignore_strapping_warning
    so every build log stops warning about a condition the board accepts.
2026-10-13 fix(firmware): rename the charger STAT switch so it is not read as the LED
    The "Charger Status LED" entity is a switch that enables or disables the
    charger's STAT output; LED2 is driven by the charger, not the MCU. Rename
    it "Enable Charger Status LED", mark it as a config entity, and say so in
    a comment.
2026-10-13 feat(hub): add BQ34Z100 sense filter, move REGIN to 3V3_SYS, dim LEDs
    - Add the SRP/SRN differential filter: R402/R403 100R (C22775) and
    C403 100nF, symmetric about the sense resistor R404 (formerly R60).
    Kelvin taps land on the shunt's own pads.
    - Power BQ34Z100 CE/REGIN from 3V3_SYS instead of VBAT_PROTECTED so the
    gauge no longer clamps the I2C bus without a battery; move C401 to
    REGIN as its decoupling cap.
    - Leave R9/R11 (charger D+/D-) unpopulated: the charger on the shared
    USB data lines caused enumeration failures.
    - Raise LED series resistors to cut brightness: R10 680R (C23228),
    R3 330R (C23138).
    - Fill in Usage/Placement fields for R402, R403, R404, C403.
    - Set F.Fab t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
2026-10-13 docs: replace "never fabricated or tested" banner with prototype status
    - README and website overview: the hub prototype built from 1645733 has
    been assembled and bench-tested; say what worked, what bring-up found,
    and that the corrected revision is not built yet.
    - Fuel gauge doc: CE/REGIN now come from 3V3_SYS; rewrite the battery
    connection section and its trade-offs to match.
    - Charger doc: note the 0R link finding for R9/R11.
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2026-10-13 fix(hub): set PCB title block revision to Rev 1.0 to match silkscreen
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2026-10-13 docs: accuracy pass across hub, satellite and attribution pages
    - Hub pages: thermistor behaviour (charger suspends charging by default,
    ts_ignore overrides), user bus description, strapping pins, test
    points, connector pinouts, source arbitration, wireless wording, and
    removal of the stale HVDCP and gauge-supply claims.
    - Remove brittle counts and part labels (BOM, capacitor and test point
    counts, connector counts).
    - Firmware and use-cases pages: replace "never built" banners with
    prototype status, DS2484 -> DS2482, label old-board figures.
    - Satellite pages: fix swapped JP1 address rows, JP17 isolation claim,
    jumper table, cable-length claim, pull-up and layer descriptions.
    -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
2026-10-13 fix(hub): turn reverse-polarity FETs Q1/Q2 around so their body diodes block
    Q1 and Q2 had their source on the connector and drain on the board. The
    gate turned the channel off on a reversed input, but the body diode then
    conducted from the board to the connector and dragged VDC / VBAT_PROTECTED
    to roughly the reversed voltage, beyond the charger's -2 V VAC/VBUS rating.
    - Swap drain and source on Q1 and Q2: drain on J4 / CN5, source on the
    board.
    - Move D2's cathode to VDC so it still clamps Q2 gate-to-source.
    - Rewrite the topology section of input-protection.md, and update the
    overview and testing-status pages.
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2026-10-13 docs(website): render the testing status page from JSON fetched from a Gist
    The checklist can now be updated by editing a Gist, without a commit or a
    release. The page fetches the Gist's raw JSON in the browser and falls back
    to src/data/testing-status.json, bundled with the site, if the fetch fails.
    TESTING_STATUS_URL overrides the source at build time.
    Also marks "End of charge" as tested.
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2026-10-14 feat(hub): add FG_PWR jumper to choose the fuel gauge's power source
    A three-pad solder jumper on the bottom feeds the BQ34Z100's CE/REGIN
    (FG_REGIN) from either 3V3_SYS (pads 1-2 bridged, default) or
    VBAT_PROTECTED (cut 1-2, bridge 2-3). BAT stays on the battery. The default
    keeps the gauge from blocking the internal I2C bus when no battery is
    fitted; the battery setting keeps it counting through ship mode.
    Also adds the power flag needed to clear the ERC "input power pin not
    driven" error on REGIN.
2026-10-14 docs: document FG_PWR and trim the overview page
    - Fuel gauge doc: power section rewritten around the FG_PWR jumper.
    - pinout.md lists FG_PWR; overview notes the gauge restart depends on it;
    testing-status data updated.
    - Overview trimmed from 230 to 140 lines: remove design rationale and the
    REGN divider derivation (kept in the charger notes), tighten the
    protection, I2C and charging sections, and fix the stale "internal mux"
    wording.
2026-10-14 docs(website): add JLCPCB ordering guide and getting started, formalize hazard alerts
    Public pages now name connectors by silkscreen label or function instead of
    KiCad designators, and the prototype warning lists concrete failure modes
    (charge voltage, thermistor, charge current, reverse polarity).
    - add Order from JLCPCB and Getting started pages under "Build your own"
    - replace the prototype warning in the README, overview and homepage with
    danger/caution blocks
    - rewrite the landing feature copy with explicit input ranges and bus layout
    - use Qwiic Sys / Qwiic User, RESET / BOOT / WAKE and VCC_2 INJ in connectors
    and overview; align the download-mode steps in the firmware page
    Co-Au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
2026-10-14 docs: reword the prototype status as validation incomplete, not unverified
    Charging, charge termination and battery-alone operation have worked on the
    prototype, so the banners no longer call the charging hardware unverified.
    They are now warnings, and the cell chemistry, thermistor and charge-current
    ceiling are a setup list rather than listed as hazards. Reverse polarity stays
    marked untested because the FETs changed after the prototype.
2026-10-14 docs: close the warning blocks and correct the charge current wording
    The rewrite dropped the closing ::: on the overview, getting started and
    ordering pages, so the whole page rendered as a warning. Also stop saying
    nothing in hardware limits the charge current: the input current limit
    restricts it, but only loosely, so the firmware ceiling is what holds it.
    Word the chemistry and charge current items the same way, as settings to
    make in the firmware.
2026-10-14 docs: say the thermistor can be replaced by ts_ignore in the status warnings
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2026-10-14 hardware(hub): stencil registration, recoloured connector models, wider power traces
    - Add F.Paste circles on the four mounting holes so the stencil gets
    registration openings (Ø2.7 mm, matching the holes)
    - Recolour 3D models: TS connectors (J302/J401) white, battery (J4) and
    Qwiic (J203/J6) tan, PH pins silver; models live in libraries/3dmodels
    and are referenced via ${KIPRJMOD}; the JST PA footprint now uses the
    repo copy instead of the Snapeda library
    - Widen REGN_RAIL/FG_REGIN and several GND segments; Power and Power_2A
    netclass widths raised to 0.4 mm
    - R9/R11 switched to R_0603 hand-solder footprint (schematic updated)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
2026-10-14 hardware(satellite): stencil registration openings and wider traces
    - Add F.Paste circles (Ø2.1 mm) on the three mounting holes for stencil
    registration
    - Widen RJ45_GND_1 and SAT_3V3 narrow runs and other minor trace fixes
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

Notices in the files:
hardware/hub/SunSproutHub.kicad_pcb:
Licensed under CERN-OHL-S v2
